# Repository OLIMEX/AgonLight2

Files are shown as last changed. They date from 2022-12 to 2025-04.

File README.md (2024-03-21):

# AgonLight2

AgonLight OSHW Retro Z80 computer - an updated version with few updates

This is a re-design of the original version of AgonLight made by Bernardo Kastrup: https://github.com/TheByteAttic/AgonLight

What is new:
- The board schematic and PCB were re-captured and re-layout in KiCad instead of EasyEDA, KiCad is open source software – free to download and use, it is a more fitting CAD tool for an Open Source Hardware project;
- The power of the original AgonLight is delivered through USB-A connector. We decided to replace it with USB-C connector which is used in all new phones, tablets, and devices due to the new EU directive. Usually everyone has such a cable at home to charge and transfer files to their cell phone;
- The linear voltage regulator is replaced with DCDC which delivers up to 2A current;
- Battery Li-Po charger and step-up converter were added, this keeps the board fully operational even if the external power supply gets disconnected;
- The original design has a PS2 connector for a keyboard and required a USB to PS2 adapter to operate with the more available USB keyboards. We replaced the PS2 connector with a USB-A connector so a normal USB keyboard (which supports PS2) can be directly plugged-in to AgonLight;
- AS7C34096A-10TCTR SRAM is routed with 40 ohm impedance lines as per the datasheet;
- Fixed a signal naming in the ESP32-PICO-D4, which now is updated in the original AgonLight documentation;
- The bare header 32-pin connector is replaced with a plastic boxed 34-pin connector following the same layout and adding two additional signals Vbat and Vin which allow AgonLight to be powered via this connector too;
- [UEXT connector](https://www.olimex.com/Products/Modules/UEXT/) was added - it allows AgonLight to be expanded easily (without soldering) with: [temperature sensors, environmental air quality sensors, pressure sensors, humidity sensors, gyroscopes, light sensors, RS485, LCDs, LED matrices, relays, Bluetooth modules, Zigbee modules, Lora modules, GSM modules, RFID readers, GPS, pulse, EKG, RTC, etc](https://www.olimex.com/Products/Modules/);
- Added four 3.3mm mount holes with GND sleeve were added so the board can be attached firmly to a box or another board but also kept the original 2.5mm mount holes.

Please do not forget to check AgonLight topics in GitHub for many utilities and code written by AgonLight community: https://github.com/topics/agon-light

## Useful Agon Resources
- Bernardo Kastrup https://github.com/TheByteAttic/AgonLight
- Dean Belfield Agon VDP, MOS, BBC-BASIC, Agon DOCs, projects https://github.com/breakintoprogram
- Lennart Benschop FORTH, Nano editor and MOS utilities https://github.com/lennart-benschop
- Jeroen Venema Agon Flash, HexLoad, Z80 assembler, tools, sokoban game https://github.com/envenomator
- Mario Smit Agon ZDI Load and tools https://github.com/S0urceror
- Reinhard Schu Agon Assembly https://github.com/schur/Agon-Light-Assembly
- AgonLight emulator https://github.com/james7780/AgonLightEmuSDL
- Alexander Sharikhin MOS tools https://github.com/nihirash/Agon-MOS-Tools
- Nicholas Pratt Agon Game https://github.com/NicholasPratt/Nova-Star
- Robert Lowe Agon Games collection https://github.com/pngwen
- LuzrBum Agon Games https://github.com/LuzrBum

## Licensee
* Hardware is released under CERN Open Hardware Licence Version 2 - Strongly Reciprocal, all silkscreen credits to Bernardo Kastrup and Dean Belfield should remain;
* Software is released under zlib Licensee
* Documentation is released under CC BY-SA 3.0

## Change History

23-04-2023 - Add Resources

14-12-2022 - Initial upload  of CAD files for first prototypes

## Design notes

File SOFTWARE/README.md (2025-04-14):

A properly operating AgonLight2 system has three software components: Quark™ VDP + Quark™ MOS + Quark™ BBC BASIC. By default each Olimex AgonLight2 board comes with VDP and MOS already programmed. You only need to download the contents of folder "1-SD-card-contents" to a micro SD card to start using the AgonLight2 board. You need an micro SD card in FAT or FAT32 format.

Notice that certain combinations of versions of VDP, MOS, and BBC BASIC might be incompatible. Meaning that you might need to upgrade or downgrade MOS, VDP, BASIC in order to run the board. If in doubt, use the versions we provide.

We load the versions currently at this GitHub but the board that was not purchased directly from us might arrive with previous version of VDP and MOS.

It is always recommended to get the latest files and instructions from the official VDP, MOS, BASIC locations listed below, however if you enounter problems use the versions we have provided, we have tested them and confirmed them to work. 

    • Quark™ BBC BASIC – https://github.com/breakintoprogram/agon-bbc-basic/releases - BBC Basic interpreter
    • Quark™ MOS - https://github.com/breakintoprogram/agon-mos/releases - command line machine operating system, similar to CP/M or DOS
    • Quark™ VDP - https://github.com/breakintoprogram/agon-vdp/releases - the VDP is a serial graphics terminal that takes a BBC basic text output stream as input. The output is via the VGA connector on the Agon.

The "1-SD-card-contents" folder contains sub-folders with files for the SD card, also mos files that can be flashed via bootloader without programmer (if possible);

The "2-AgonLight2-VDP-XXX" folder contains VDP;

The "3-AgonLight2-MOS-XXX" folder contains MOS that can be flashed via programmer;

The "4-AgonLight2-Console8" folder contains Console8 versions of VDP, MOS, BBC basic that can be used to upgrade the system via SD card. Refer to the README.md file in the folder for details on how to switch to Console8 VPD, MOS, BBC basic.

Copy the contents in from the "SD Card Content" into the root directory of the card. The contents are:

1) bbcbasic.bin (for the latest version check: https://github.com/breakintoprogram/agon-bbc-basic);
2) autoexec.txt which runs the BASIC on restart;
3) basic_examples_tests – various BASIC examples/test/games programs;
4) Agon-CPM2.2 – contains CPM;
5) mos – contains files suitable for updating mos without programmer.

**Updating the Agon Quark VDP on the ESP32 chip with a binary:**

1. If you don't want to compile the source code you can just upload the binary (if you wish to compile from source check next chapter)
2.  Download all contents from /2-AgonLight2-VDP-104/binary-flasher - https://github.com/OLIMEX/AgonLight2/tree/main/SOFTWARE/2-AgonLight2-VDP-104/binary-flasher
3.  Open terminal or command line to the folder where the contents are
4.  Execute flash.sh followed by com port number of device assigned by operating system (usually COMx in Windows, TTYx in Linux).

**To compile and update the Agon Quark VDP on the ESP32 chip you have to install IDE, package and libraries:**

1. Arduino IDE

    1.1. Go to: https://www.arduino.cc/en/software

    1.2 While this will most likely work with 2.x.x we recommend you to download 1.8.9 which is shown a little bit below in the section "Legacy IDE (1.8.x)"

    1.3. Download, install and run it

2. Install the ESP32 package

    2.1. Go to "Main menu --> Preferences" (CTRL+,)

    2.2. In the "Additional Boards Manager URLs" add in a new line: https://raw.githubusercontent.com/espressif/arduino-esp32/gh-pages/package_esp32_index.json

    2.3. Go to "Main menu -> Tools -> Board -> Boards manager..."

    2.4. Look for the package "ESP32" (since there are lots of packages you can filter them by typing "ESP32" in the search bar on the top)

    2.5. Install the package (it is tested with v2.0.14, notice that versions 3.x.x are confirmed not working)

3. Install the FabGL library

    3.1. Go to "Main menu -> Sketch -> Include Library -> Manage Libraries..." (CTRL+SHIFT+I)

    3.2. Look for library FabGL (just like the packages earlier you can filter all the libraries by typing "FabGL" in the search bar).

    3.3. There are two results, select the vdp-gl version by Igor Cananena. Install it. Notice: If you have trouble in the next step (errors during compilation) maybe deinstall vdp-gl and try the with FabGL instead, version 1.0.8, newer versions of the library may not work. 

4. VDP compile and update
   
    4.1. Open the sketch /2-AgonLight2-VDP-104/Source/Video/video.ino (the provided one is version 1.04, for the latest one check https://github.com/breakintoprogram/agon-vdp )

    4.2. Go to "Main menu -> Tools -> Board -> ESP32 Arduino" and select "ESP32 Dev Module"

    4.3. Plug the USB to the AgonLight2 board

    4.4. In Device manager you can see the COM# at which our device has connected

    4.5. Go to "Main menu -> Tools -> Port" select the one ESP32 has connected

    4.6. Go to "Main menu -> Tools -> PSRAM" select Enabled

    4.7. Compile and Upload (every time after opening the project in Arduino the first compilation is VERY slow - be patient)

**Updating the Agon Quark MOS on the eZ80 chip:**

1. Usually you can update the MOS without the need of programmer (the board needs to have MOS 1.02). Follow the instructions in /1-SD-card-contents/mos/README.txt - https://github.com/OLIMEX/AgonLight2/tree/main/SOFTWARE/1-SD-card-contents/mos

2. If there is no MOS at all or it's older than 1.02 you must have "ZILOG eZ80F92" programmer and have to install IDE:

    2.1. Download "ZDS II - eZ80Acclaim!" from here: https://zilog.com/index.php?option=com_zcm&task=view&soft_id=54&Itemid=74 (tested with 5.3.5 but should work with newer versions)

    2.2. Install the IDE and run it

    2.3. Go to "Main menu -> File -> Open Project" and navigate to  "3-AgonLight2-MOS-104/MOS.zdsproj" (the provided versions is 1.04, for the latest one check https://github.com/breakintoprogram/agon-mos )

    2.4. Build the project (F7)

    2.5. Connect the programmer to the ZDI connector on the AgonLight2 board

    2.6. Go to "Main menu -> Debug -> Download the code"

    2.7. When the download is complete go again to "Main menu --> Debug --> Stop Debugging" (SHIFT + F5)

    2.8. Disconnect the programmer from the board

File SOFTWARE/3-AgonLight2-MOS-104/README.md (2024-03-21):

# agon-mos

Part of the official Quark firmware for the Agon series of microcomputers

### What is the Agon

Agon is a modern, fully open-source, 8-bit microcomputer and microcontroller in one small, low-cost board. As a computer, it is a standalone device that requires no host PC: it puts out its own video (VGA), audio (2 identical mono channels), accepts a PS/2 keyboard and has its own mass-storage in the form of a µSD card.

https://www.thebyteattic.com/p/agon.html

### What is a MOS

The MOS is a command line machine operating system, similar to CP/M or DOS, that provides a human interface to the Agon file system.

It also provides an API for file I/O and other common operations for BBC Basic for Z80 and other third-party applications.

### Loadig BBC Basic for Z80

1. Download bbcbasic.bin from [agon-bbc-basic releases](https://github.com/breakintoprogram/agon-bbc-basic/releases)
2. Copy it to the root directory of the Agon SD card
3. Insert the SD card into the AGON and reset/boot it
4. Check the file is on the SD card with a `CAT` or `.` command
5. Type the following commands into MOS:
	- `LOAD bbcbasic.bin`
	- `RUN`
6. You should then be greeted with the BBC Basic for Z80 prompt

### Etiquette

Please do not issue pull requests or issues for this project; it is very much a work-in-progress.
I will review this policy once the code is approaching live status and I have time to collaborate more.

### Build

The eZ80 is programmed via the ZDI connector on the left-hand side of the board. This requires a Zilog Smart Cable that can be purchased from online stockists such as Mouser or RS Components.

There are three compatible cables with the following part numbers:

- `ZUSBSC00100ZACG`: USB Smart Cable (discontinued)
- `ZUSBASC0200ZACG`: USB Smart Cable (in stock - this requires ZDS II version 5.3.5)
- `ZENETSC0100ZACG`: Ethernet Smart Cable (in stock)

Important! Make sure you get the exact model of cable; there are variants for the Zilog Encore CPU that have similar part numbers, but are not compatible with the Acclaim! eZ80 CPU.

You can download the ZDS II tools for free via these links. The software contains an IDE, Debugger, C Compiler and eZ80 Assembler.

- [Zilog ZDS II Tools version 5.3.4](https://zilog.com/index.php?option=com_zcm&task=view&soft_id=38&Itemid=74)
- [Zilog ZDS II Tools version 5.3.5](https://zilog.com/index.php?option=com_zcm&task=view&soft_id=54&Itemid=74)

You will also need a [Hex2Bin utility](https://sourceforge.net/projects/hex2bin/) to convert the MOS.hex file to MOS.bin ready for release.

NB:

- The tools are only available for Windows PC.
- The tools are compatible with Wine on Linux / OSX, but the USB Smart Cable drivers do not work
- The Ethernet Smart Cable may be compatible with the tools running on Wine, though this combination has not been tested by me

I currently build the official Quark software on a Windows XP KVM running on Ubuntu 20.04 LTS, using ZDS II Tools version 5.3.4, connecting to the Agon with the discontinued USB smart cable.

It is recommended that building and testing the MOS is done via the ZDS II tools and a Zilog Smart Cable, otherwise there is an increased risk of bricking the Agon.

Other options for developing C and eZ80 on the Agon are available. Please check the [Agon Programmers Group on Facebook](https://www.facebook.com/groups/667325088311886) for more information.

Any custom settings for Agon development is contained within the project files, so no further configuration will need to be done.

### Documentation

The AGON documentation can now be found on the [Agon Light Documentation Wiki](https://github.com/breakintoprogram/agon-docs/wiki)

### Licenses

This code is released under an MIT license, with the following exceptions:

* FatFS: The license for the [FAT filing system by ChaN](http://elm-chan.org/fsw/ff/00index_e.html) can be found here [src_fatfs/LICENSE](src_fatfs/LICENSE) along with the accompanying code.

### Links

- [Zilog eZ80 User Manual](http://www.zilog.com/docs/um0077.pdf)
- [ZiLOG Developer Studio II User Manual](http://www.zilog.com/docs/devtools/um0144.pdf)
- [FatFS - Generic File System](http://elm-chan.org/fsw/ff/00index_e.html)
- [AVRC Tutorials - Initialising an SD Card](http://www.rjhcoding.com/avrc-sd-interface-1.php)

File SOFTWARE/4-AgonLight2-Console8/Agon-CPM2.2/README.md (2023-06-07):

# CP/M 2.2 for Agon Light



This is port of CP/M 2.2 for Agon Light(and Agon Light 2) that didn't require reflashing VDP.

It starts directly from MOS as application(exit only via RESET) and uses MOS's filesystem drivers for working with drive images.

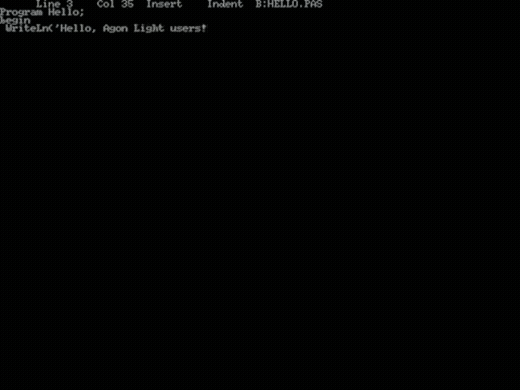
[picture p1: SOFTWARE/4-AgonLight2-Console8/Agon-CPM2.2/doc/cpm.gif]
GIF screen capture


## Usage

Create some directory on Agon's SD card, put `cpm.bin` and disk images(**TO THE SAME DIRECTORY**) that will be named `cpma.dsk`, `cpmb.dsk` etc, drives from `A:` to `P:` are supported. 

Load and run binary and you'll be in CP/M's wonderland.

## Working with images

I'm using [cpmtools](https://github.com/lipro-cpm4l/cpmtools) for working with CP/M drive images.

Disk definition can be copied from `diskdefs` file(in `disks` directory).

For new drives better use template.dsk(make copy with proper naming and copy yourown files to it). 

## Development

Make sure that you **really want it**.

Build process have 2 stages. Building CP/M itself(`sources` directory) - you'll need [sjasmplus](https://github.com/z00m128/sjasmplus). As result - you'll got `cpm.sys` file that should be placed to directory with bootstrap source. 

Bootstrap can be built with [ez80asm](https://github.com/envenomator/agon-ez80asm). Better use latest version.

As result - you'll got `cpm.bin` executable that will include bootstrap and system both.

## Important remarks

BIOS and CP/M core should be aligned by 256 bytes.

If you'll make some changes in code - make sure that bios starts from 0xXX00 address. In other case - you'll die until you find issue why software got broken.

All terminal issues caused by current VDP implementation. They can be fixed soon. 

## Licensing

CP/M itself [opensourced](https://www.theregister.com/2001/11/26/cp_m_collection_is_back/) and free for redistribution. 

My parts of code licensed as usual under [Coffeeware License](LICENSE).

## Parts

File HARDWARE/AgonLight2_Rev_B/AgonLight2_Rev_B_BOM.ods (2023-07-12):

Qty | Designation | Package | Designator
12 | 33R/0603 | R_0603_5MIL_DWS | R1,R2,R3,R5,R6,R7,R8,R12,R18,R19,R24,R43
1 | 150R/0603 | R_0603_5MIL_DWS | R23
1 | 220R/0603 | R_0603_5MIL_DWS | R58
1 | 270R/0603 | R_0603_5MIL_DWS | R25
3 | 430R/1%/0603 | R_0603_5MIL_DWS | R26,R28,R30
3 | 820R/0603 | R_0603_5MIL_DWS | R27,R29,R31
1 | 1.1K/1%/0603 | R_0603_5MIL_DWS | R50
10 | 2.2K/0603 | R_0603_5MIL_DWS | R22,R37,R38,R39,R40,R47,R48,R51,R56,R57
8 | 4.7K/0603 | R_0603_5MIL_DWS | R4,R9,R10,R11,R13,R14,R15,R16
2 | 5.1K/0603 | R_0603_5MIL_DWS | R45,R46
1 | 8.2K/1%/0603 | R_0603_5MIL_DWS | R49
12 | 10K/0603 | R_0603_5MIL_DWS | R17,R32,R33,R34,R42,R44,R54,R55,R61,R60, R62,R63
2 | 22K/0603 | R_0603_5MIL_DWS | R20,R21
1 | 49.9K/1%/0603 | R_0603_5MIL_DWS | R53
1 | 220K/0603 | R_0603_5MIL_DWS | R52
1 | RA1206_(4x0603)_4B8_100k | RA1206_(4X0603)_4B8_xx | RM1
2 | 27pF/C0G/50VDC/5%/0603 | C_0603_5MIL_DWS | C55,C56
8 | 1nF/X7R/50VDC/0402 | C_0402_5MIL_DWS | C9,C10,C11,C12,C14,C15,C16,C17
22 | 100nF/10V/20%/X5R/0402 | C_0402_5MIL_DWS | C5,C6,C7,C8,C13,C18,C19,C20,C21,C26,C28, C29,C31,C32,C35,C39,C40,C41,C42,C58, C62,C63
1 | 33nF/X7R/50VDC/10%/0603 | C_0603_5MIL_DWS | C38
20 | 10uF/6.3V/20%/X5R/0603 | C_0603_5MIL_DWS | C1,C2,C3,C4,C22,C23,C24,C25,C27,C30,C33, C34,C36,C37,C43,C44,C45,C49,C59,C60
4 | 22uF/6.3V/20%/X5R/C0603 | C_0603_5MIL_DWS | C51,C52,C57,C61
6 | 47uF/6.3V/20%/X5R/0805 | C_0805_5MIL_DWS | C46,C47,C48,C50,C53,C54
2 | 1N4148W/SOD123 | SOD-123_1C-2A_KA | D1,D2
2 | 1N5822/SS34/SMA | SMA-KA | D4,D5
2 | 1N5819S4/SOD123 | SOD-123_1C-2A_KA | D6,D7
1 | LED/YELLOW/0603 | LED_0603_KA | CHARGING1
1 | LED/RED/0603 | LED_0603_KA | POWER1
2 | 2.2uH/1.5A/ NRS3015T2R2MNGH | CD32 | L5,L6
4 | FB0805/600R/2A | L_0805_5MIL_DWS | L1,L2,L3,L4
2 | BSS138(SOT23-3) | SOT23 | FET1,FET2
1 | WPM2015-3/TR | SOT23 | FET3
3 | BC817-40NPN(SOT23) | SOT23 | Q2,Q4,Q5
1 | Q12MHz/20pF/10ppm/ 4P/3.2x2.5mm | TSX-3.2x2.5mm_GND(3) | Q3
1 | ASE-18.432MHZ-L-C-T | Oscillator-18.432MHz-3.2x2.5mm | Q1
2 | SN74LVC1G125DBVR | SOT-23-5 | BUF1,BUF2
1 | SN74LVC1G04DBVR | SOT-23-5 | BUF3
1 | EZ80F92AZ020EG(LQFP100) | LQFP-100_14x14mm_ STM32H730VBT6 | U1
1 | AS7C34096A-10TCTR | TSOP-44_Pitch-0.80mm_ 18.80x11.80x1.20mm | U2
1 | ESP32-PICO-D4 | ESP32-PICO-D4 | U3
1 | BL4054B-42TPRN(SOT23-5) | SOT-23-5 | U5
1 | SY8089AAAC(SOT23-5) | SOT-23-5 | U7
1 | MT3608(SOT23-6) | SOT23-6 | U8
1 | CH340T(SSOP20W) | SSOP-20W | U9
1 | VDA2710NTA(SOT-23) | SOT-23 | U10
1 | APS6404L-3SQR-SN | SO-8 | U4
1 | BUZZER_PB1221P (1.1-1.7V_2kHz_12MM) | PB1221P_1-Plus_2-Minus | BUZ1
1 | B-R-10-LF(BH10R) 2x05_90DEGREE | UEXT_BH10R | UEXT1
1 | BH06S_2x3(B-D-02x3-LF) | BH06S | ZDI1
1 | B-R-34-LF(BH34R) 2x17_90DEGREE | BH34R | GPIO1
1 | HN1x4 | HN1x4 | ACCESS_BUS1
1 | DW02R | LIPO_BAT-CON2DW02R | BAT1
1 | USBLC6-2P6 | SOT-666 | U6
1 | B3F-3150 | B3F-31XX | RESET1
1 | VGA15 | VGA15-F(CD0515S21J0) | VGA1
1 | PJ-3.5-365-5P (SCJ325P00XG0B02G)-COPY | SCJ325P00XG0B02G | AUDIO1
1 | TFC-WPAPR-08-LF | TFC-WPAPR-08 | MICRO_SD1
1 | USB-C-16P-F (A40-00119-A52-12) | USB2.0_TYPE-C (A40-00119-A52-12) | USB1
1 | USB-SRWH-4A-LF(USB-A) | USB_PN87520_HOST_PTH | USB_KEYBOARD1
3 | HN1x2+MJ6 | HN1x2_Jumper | BUZ_EN1,UART_DIS1,ESP_PROG1
45 | NA | D_0402_5MIL_DWS | TVS1,TVS2,TVS3,TVS4,TVS5,TVS6,TVS7, TVS11,TVS12,TVS13,TVS14,TVS15,TVS16, TVS17,TVS18,TVS19,TVS20,TVS21,TVS22, TVS23,TVS24,TVS25,TVS26,TVS27,TVS28, TVS29,TVS30,TVS31,TVS32,TVS33,TVS34, TVS35,TVS36,TVS37,TVS38,TVS39,TVS40, TVS41,TVS42,TVS43,TVS44,TVS45,TVS46, TVS47,TVS48
6 | NA(GG0402052R542P) | D_0402_5MIL_DWS | TVS8,TVS9,TVS10,TVS49,TVS50,TVS51
2 | NA(120R/0603) | R_0603_5MIL_DWS | R35,R36
2 | NA | R_0603_5MIL_DWS | R41,R59
1 | NA | SMA-KA | D3

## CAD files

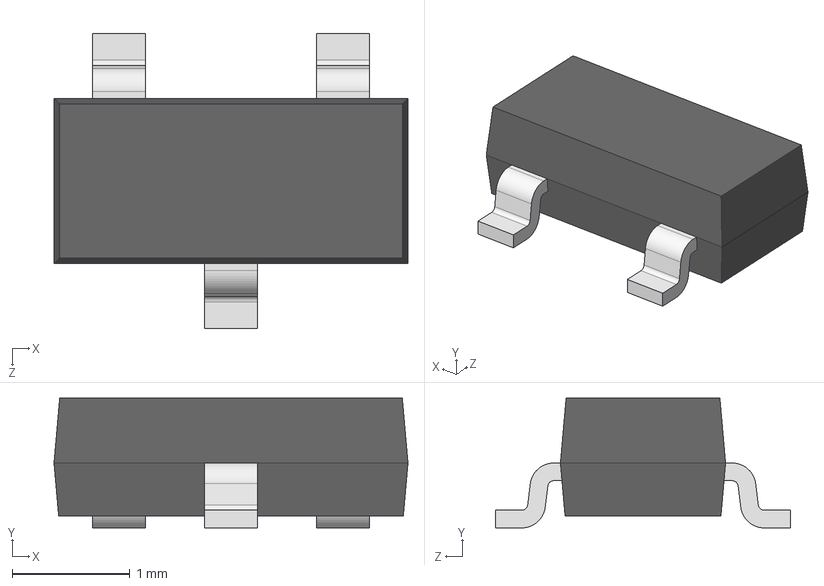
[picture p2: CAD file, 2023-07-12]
HARDWARE/AgonLight2_Rev_B/3d/SOT-23.step
3.00 x 1.10 x 2.50 mm

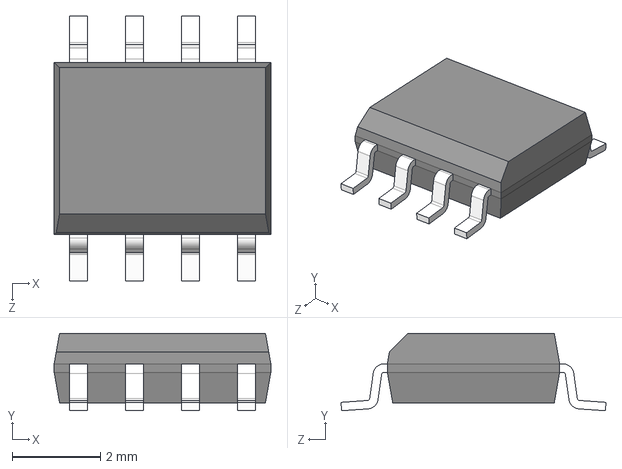
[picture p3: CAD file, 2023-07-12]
HARDWARE/AgonLight2_Rev_B/3d/SO-8_150mil---SN65HVDA1050AQDRQ1.STEP
4.90 x 1.75 x 5.99 mm

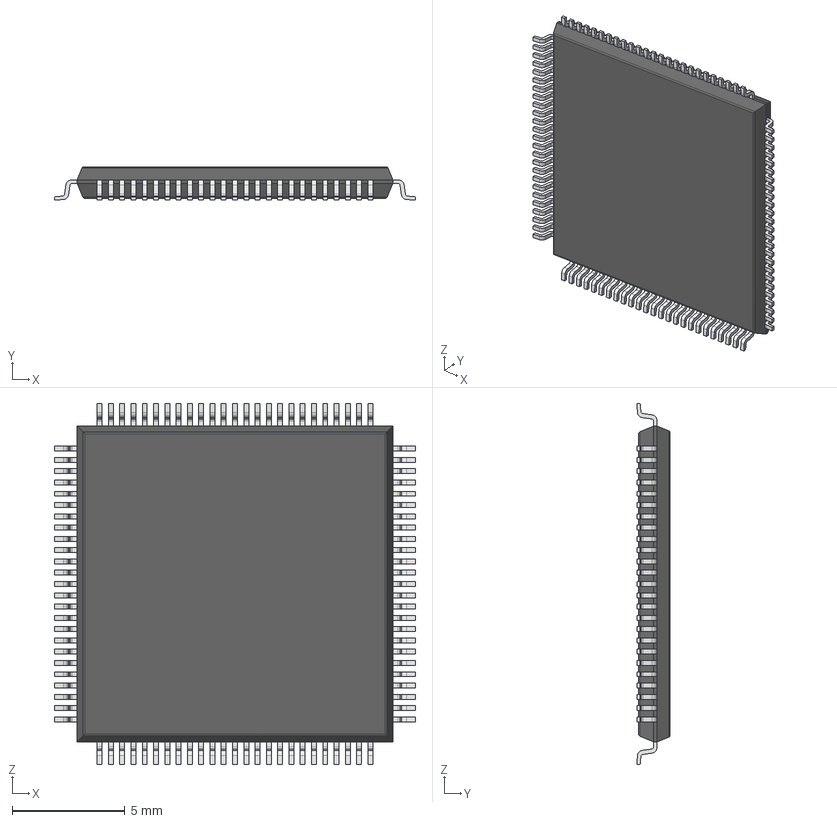
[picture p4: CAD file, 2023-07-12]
HARDWARE/AgonLight2_Rev_B/3d/stm32f103vet6.stp
16.0 x 1.48 x 16.0 mm

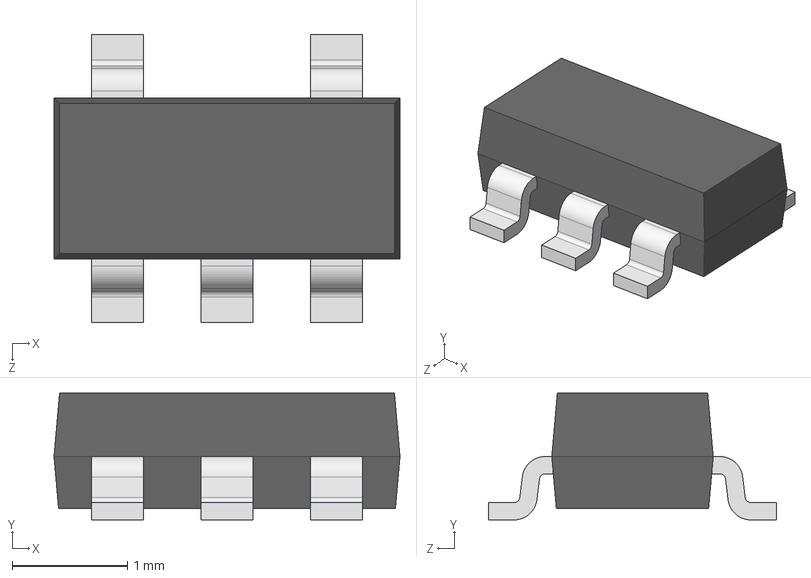
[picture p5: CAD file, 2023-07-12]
HARDWARE/AgonLight2_Rev_B/3d/SOT-23-5.step
3.00 x 1.10 x 2.50 mm

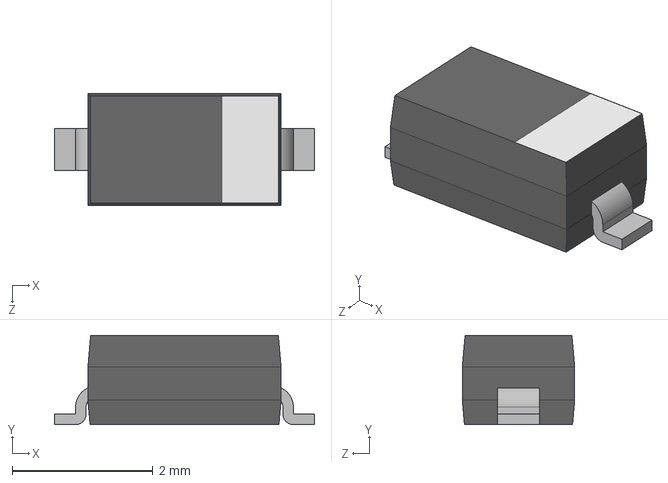
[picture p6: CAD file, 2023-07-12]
HARDWARE/AgonLight2_Rev_B/3d/SOD123.step
3.70 x 1.27 x 1.60 mm

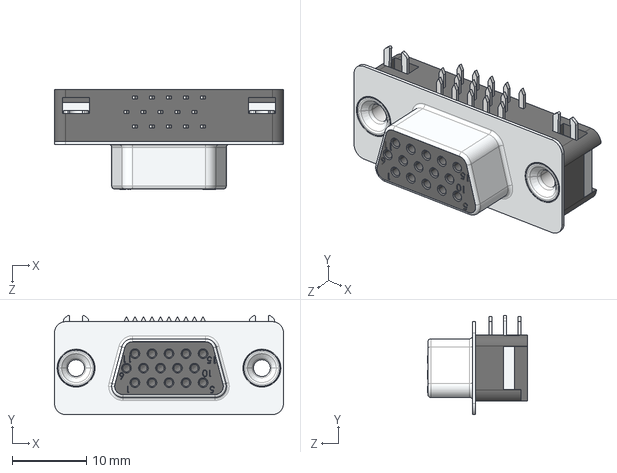
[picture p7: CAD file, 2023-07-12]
HARDWARE/AgonLight2_Rev_B/3d/User Library-SLIM D-SUB RIGHT ANGLE PCB MOUNT.step
30.8 x 13.3 x 13.5 mm

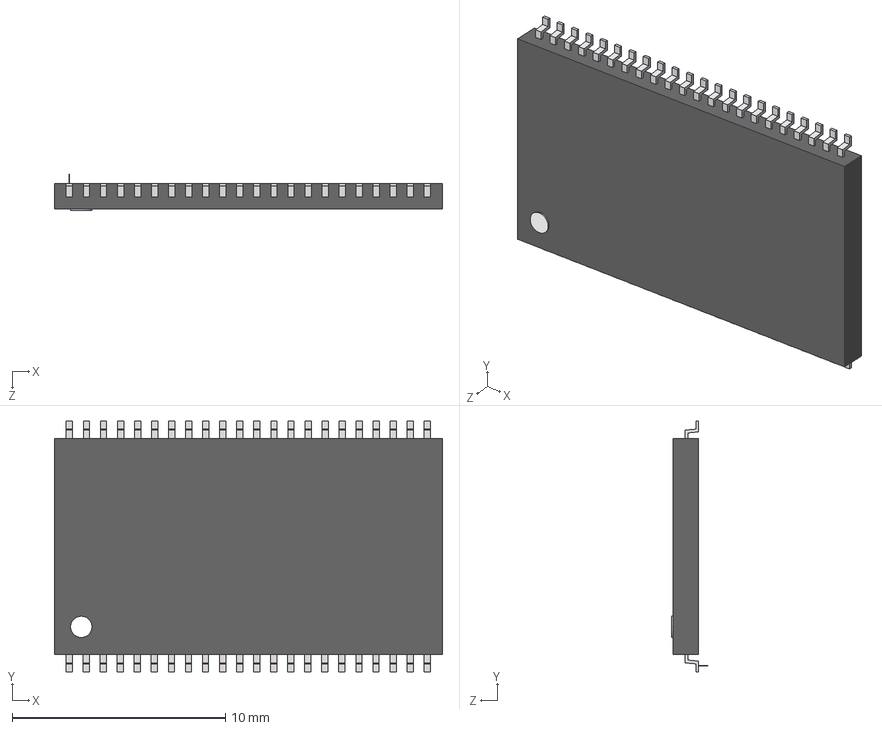
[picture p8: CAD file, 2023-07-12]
HARDWARE/AgonLight2_Rev_B/3d/User_Library-TSOP2-44.STEP
18.2 x 11.8 x 1.70 mm
Extruded2 x 44
Board4 x 44
Extruded3
Board3
Board5

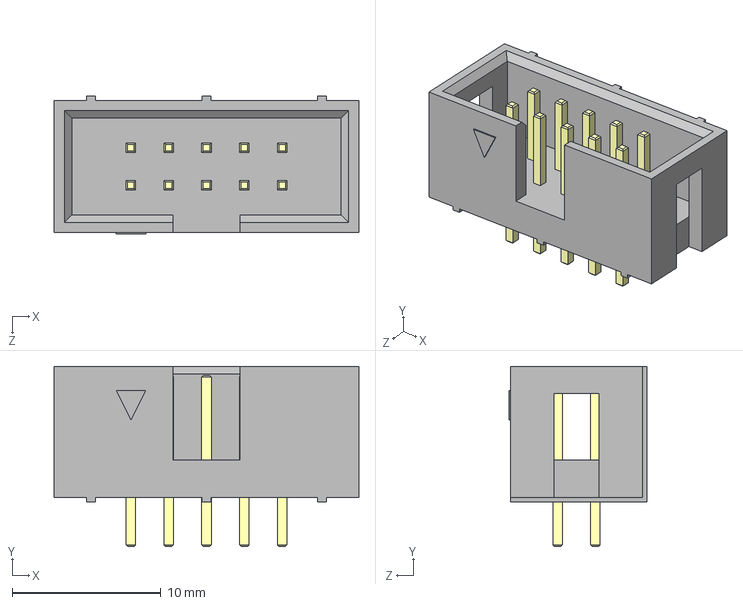
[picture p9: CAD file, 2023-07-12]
HARDWARE/AgonLight2_Rev_B/3d/BH-10__64.step
20.5 x 12.1 x 9.30 mm

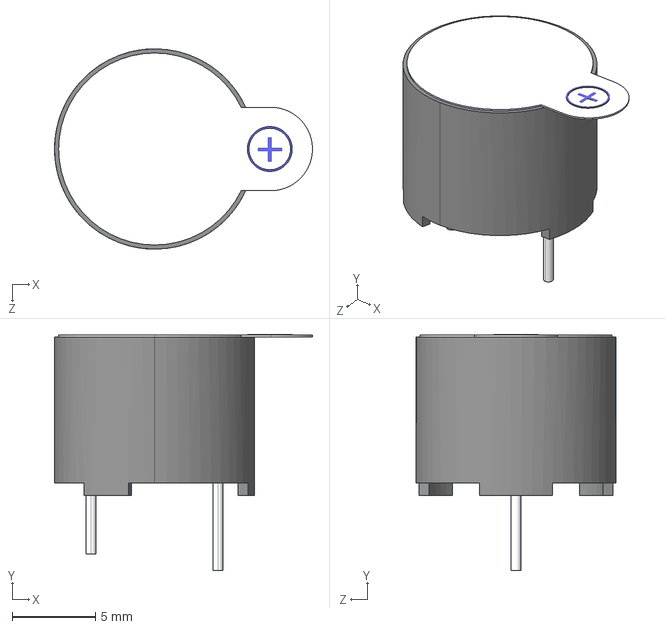
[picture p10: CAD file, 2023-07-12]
HARDWARE/AgonLight2_Rev_B/3d/ALSRobot-BUZZER.step
15.5 x 14.2 x 12.0 mm

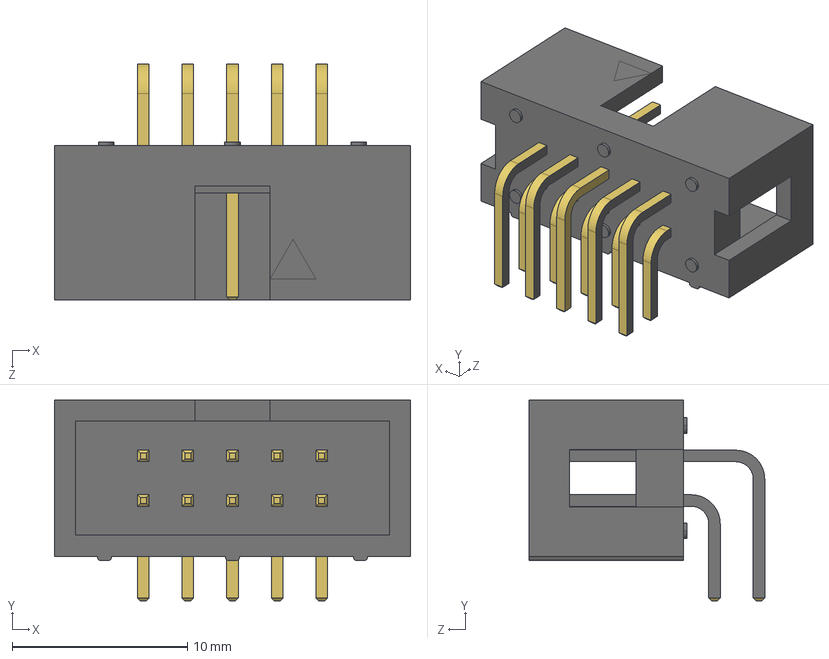
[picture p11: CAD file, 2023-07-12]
HARDWARE/AgonLight2_Rev_B/3d/Header_right_angle_10way(2x5).step
20.3 x 11.4 x 13.4 mm

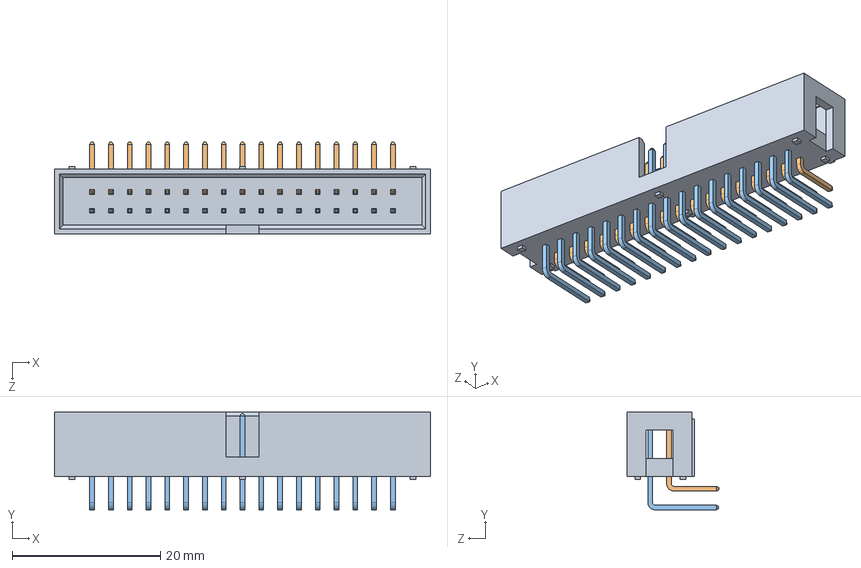
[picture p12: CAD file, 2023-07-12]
HARDWARE/AgonLight2_Rev_B/3d/BH34R_CH87342H100.STEP
50.8 x 13.2 x 12.4 mm
CH87 BASE_34
H TYPEµuPIN x 17
H TYPEªøPIN x 17

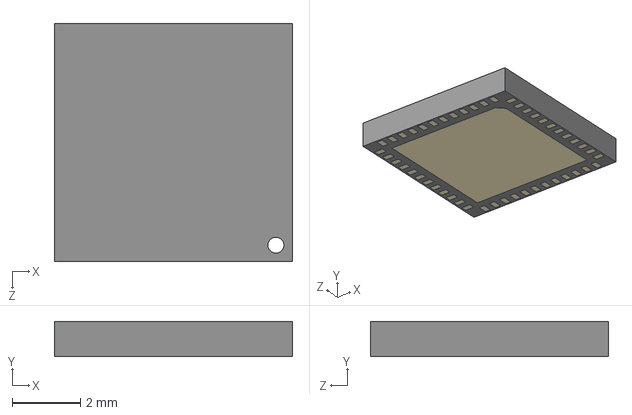
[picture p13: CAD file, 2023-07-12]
HARDWARE/AgonLight2_Rev_B/3d/ESP32-PICO-D4.STEP
7.00 x 1.04 x 7.00 mm

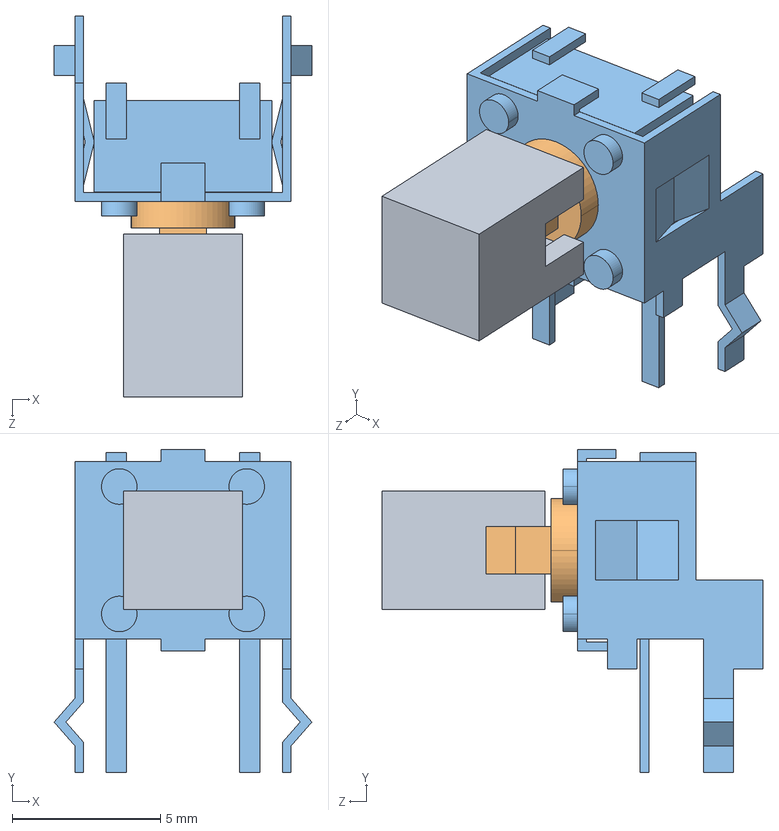
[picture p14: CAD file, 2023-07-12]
HARDWARE/AgonLight2_Rev_B/3d/B3F_3150.step
8.70 x 10.9 x 12.9 mm
B32_1000
B3F_3150_BUTTON
B3F_3150_BASE

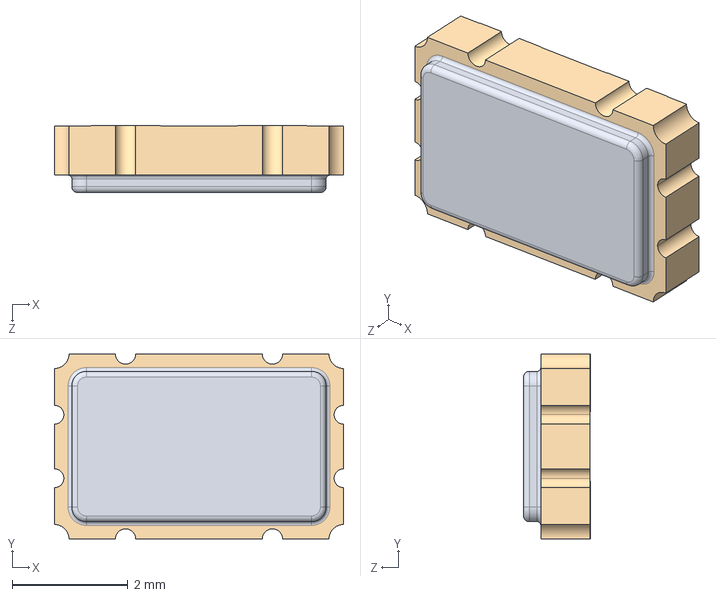
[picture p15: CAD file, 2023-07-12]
HARDWARE/AgonLight2_Rev_B/3d/QSG5032.step
5.00 x 3.20 x 1.16 mm

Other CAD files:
HARDWARE/AgonLight2_Rev_B/3d/TFC-WPAPR-08---112J-TXAR-R_C_1-1.STEP
HARDWARE/AgonLight2_Rev_B/3d/L-CD32_shielded.step
HARDWARE/AgonLight2_Rev_B/3d/72w2538_292303-4.stp
HARDWARE/AgonLight2_Rev_B/3d/DO-214AC_SMA.step
HARDWARE/AgonLight2_Rev_A/3d/72w2538_292303-4.stp
HARDWARE/AgonLight2_Rev_A/3d/Audio_Jack-3.5mm---CUI_SJ1-3515-SMT-TR.step
HARDWARE/AgonLight2_Rev_A/3d/DO-214AC_SMA.step
HARDWARE/AgonLight2_Rev_A/3d/HN1x2-PinHeader_1x02_P2.54mm_Vertical.step
HARDWARE/AgonLight2_Rev_A/3d/HN1x4-PinHeader_1x04_P2.54mm_Vertical.step
HARDWARE/AgonLight2_Rev_A/3d/JST_B2B-PH-SM4-TB(DW02R).step
HARDWARE/AgonLight2_Rev_A/3d/L-CD32_shielded.step
HARDWARE/AgonLight2_Rev_A/3d/SOT-23-6.step
HARDWARE/AgonLight2_Rev_A/3d/TFC-WPAPR-08---112J-TXAR-R_C_1-1.STEP
HARDWARE/AgonLight2_Rev_A/3d/User Library-SOT50P160X60-6.step
HARDWARE/AgonLight2_Rev_B/3d/Audio_Jack-3.5mm---CUI_SJ1-3515-SMT-TR.step
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

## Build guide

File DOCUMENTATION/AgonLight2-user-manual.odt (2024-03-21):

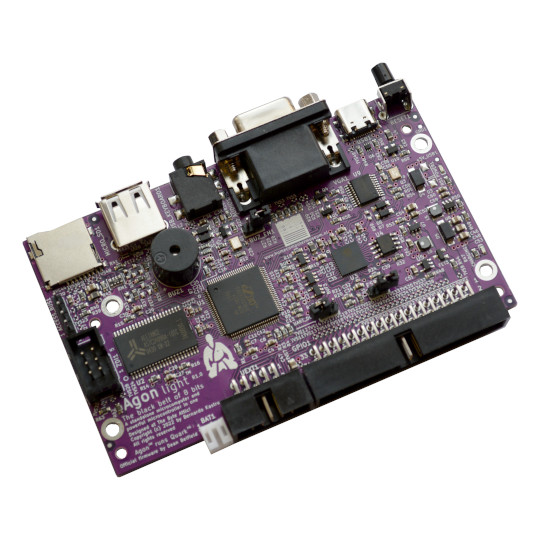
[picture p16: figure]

AgonLight2

User Manual

Rev.1.9 March 2024 olimex.com

# INTRODUCTION

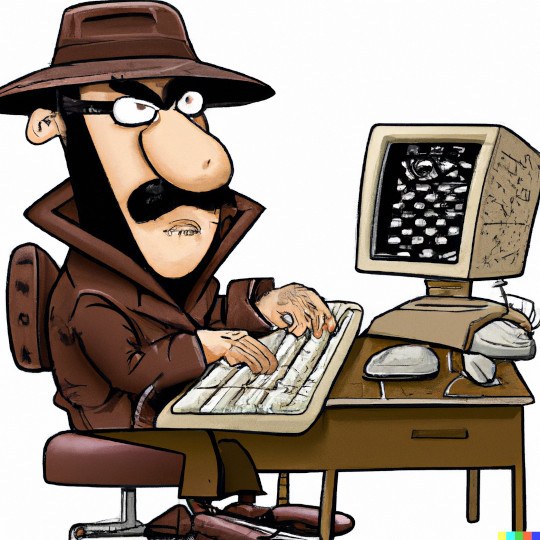
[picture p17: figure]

## What is AgonLight2?

AgonLight2 (https://www.olimex.com/Products/Retro-Computers/AgonLight2/open-source-hardware) is a re-design of the original AgonLight eZ80F92 retro computer, designed as a hobby project by Bernardo Kastrup;

AgonLight2 (https://www.olimex.com/Products/Retro-Computers/AgonLight2/open-source-hardware) is a complete Single Board Computer (SBC) with VGA display output, PS2 keyboard, and SD card (acting as an external disk). This means that to write and run programs you do not need an external computer like Arduino boards do;

AgonLight2 (https://www.olimex.com/Products/Retro-Computers/AgonLight2/open-source-hardware) is BASIC-programmable microcomputer;

AgonLigh (https://www.olimex.com/Products/Retro-Computers/AgonLight2/open-source-hardware)t2 (https://www.olimex.com/Products/Retro-Computers/AgonLight2/open-source-hardware) has a GPIO connector with GPIO ports, I2C, SPI, and more signals, which are accessible and can be used to interact with additional hardware (sensors, expansions, etc);

AgonLight and AgonLight2 (https://www.olimex.com/Products/Retro-Computers/AgonLight2/open-source-hardware) are Open Source Hardware and officially OSHWA certified (https://certification.oshwa.org/bg000090.html);

All CAD source files are available at AgonLight (https://github.com/TheByteAttic/AgonLight) and AgonLight2 (https://github.com/OLIMEX/AgonLight2) GitHub repositories. They are released under CERN Open Hardware License Version 2 – Strongly Reciprocal and allow users to learn, study, edit, modify, produce, and sell same or derivative products based on these designs. The only requirements is to open source their work under the same licensee.

The firmware of AgonLight is written by Dean Belfield and reproduces BBC Basic for Z80. The firmware is also Open Source Software and available on GitHub (https://github.com/breakintoprogram/agon-bbc-basic/). The same firmware works on AgonLight2 (https://www.olimex.com/Products/Retro-Computers/AgonLight2/open-source-hardware) without any modifications.

AgonLight2 (https://www.olimex.com/Products/Retro-Computers/AgonLight2/open-source-hardware) is RoHS, REACH, CE and UKCA compliant.

## Order codes and links for AgonLight2 and accessories

AgonLight2 (https://www.olimex.com/Products/Retro-Computers/AgonLight2/open-source-hardware) Single board BBC BASIC Z80 Retro style computer

MICRO-SD-CLASS (https://www.olimex.com/Products/Components/Storage/MICRO-SD-CLASS10/) You need a microSD card to store BASIC and software (demos, examples)

AgonLight2-Proto (https://www.olimex.com/Products/Retro-Computers/AgonLight2-Proto/open-source-hardware) DIY expansion kit with big proto area; compatible with AgonLight2

BOX-AGONLIGHT2-BLACK (https://www.olimex.com/Products/Retro-Computers/BOX-AGONLIGHT2-BLACK/) Protective metal boxwith polymer coating; compatible with AgonLight2

CABLE-USB-A-C-1M (https://www.olimex.com/Products/Components/Cables/CABLE-USB-A-C-1M/) USB-C data and power cable

BATTERY-LIPO1400mAh (https://www.olimex.com/Products/Power/Lipo-battery/BATTERY-LIPO1400mAh/) Li-po battery 3.7V 1400mAh – note that these batteries can be shipped only by ground so we can deliver only to EU destinations

USB-KEYBOARD-PS2 (https://www.olimex.com/Products/USB-Modules/USB-KEYBOARD-PS2/) USB keyboard which supports PS2 and can be used for AgonLight2 (https://www.olimex.com/Products/Retro-Computers/AgonLight2/open-source-hardware)

B (https://www.olimex.com/Products/Breadboarding/BREADBOARD-1/)READBOARD-1 (https://www.olimex.com/Products/Breadboarding/BREADBOARD-1/) Breadboard for experimenting with AgonLight2 (https://www.olimex.com/Products/Retro-Computers/AgonLight2/open-source-hardware)

JW-200x10-FM (https://www.olimex.com/Products/Breadboarding/JUMPER-WIRES/JW-200x10-FM/) 10 pieces female-male jumper wires for breadboarding

JW-200x10 (https://www.olimex.com/Products/Breadboarding/JUMPER-WIRES/JW-200x10/) 10 pieces male-male jumper wires for breadboarding

JW-200x10-FF (https://www.olimex.com/Products/Breadboarding/JUMPER-WIRES/JW-200x10-FF/) 10 pieces female-female jumper wires for breadboarding

UEXT modules (https://www.olimex.com/Products/Modules/) Different sensors, relays, LCDs, RTC, GSM, GPS etc accessories which can be connected to AgonLight2 (https://www.olimex.com/Products/Retro-Computers/AgonLight2/open-source-hardware) UEXT connector

MOD-Wii-UEXT-NUNCHUCK (https://www.olimex.com/Products/Modules/Sensors/MOD-WII/MOD-Wii-UEXT-NUNCHUCK/open-source-hardware) 3 axis joystick, two buttons game controller with UEXT connector

## The differences between AgonLight and AgonLight2

AgonLight2 (https://www.olimex.com/Products/Retro-Computers/AgonLight2/open-source-hardware) has these differences from the original design:

- KiCad is used for the CAD, instead of EasyEDA. KiCad is open source software – free to download and use, it is a more fitting CAD tool for an Open Source Hardware project;
- USB-C connector for power supply;
- DCDC power converter with up to 2A output instead of linear power converter;
- Li-Po battery backup power supply, the battery acts like a UPS and will power the computer even if the USB-C gets disconnected. The battery is charged automatically when USB or external power supply is present;
- USB connector for keyboard (but the keyboard must be PS2 compatible!!!);
- SRAM routed with 40 ohm impedance as per part datasheet;
- Fixed some wrong signal naming on ESP32-PICO-D4 GPU co-processor;
- Fixed GPIO and programming connector pin ordering;
- Replaced the naked header 32-pin connector with a plastic boxed 34-pin connector following the same layout and adding two additional signals Vbat and Vin which allow AgonLight2 (https://www.olimex.com/Products/Retro-Computers/AgonLight2/open-source-hardware) to be powered by this connector too;
- Added UEXT connector (https://www.olimex.com/Products/Modules/UEXT/) – it allows AgonLight to be expanded easily (without soldering) with: temperature sensors, environmental air quality sensors, pressure sensors, humidity sensors, gyroscopes, light sensors, RS485, LCDs, LED matrices, relays, Bluetooth modules, Zigbee modules, Lora modules, GSM modules, RFID readers, GPS, pulse, EKG, RTC, etc (https://www.olimex.com/Products/Modules/);
- Added 4 grounded mount holes with 3.3mm diameter, but also kept the original 2.5 mm mount holes.

## First time start up or how to prepare the SD card and boot

Important! Notice that AgonLight2 (https://www.olimex.com/Products/Retro-Computers/AgonLight2/open-source-hardware) comes completely assembled, tested, and programmed with firmware. The only thing you would need to do is prepare a microSD card with BBC basic and some examples, then connect your display and peripherals and apply power supply. The board comes without micro SD card which has to be purchased separately! You might need extra SD card writer.

1. Open a web browser and navigate to: https://github.com/OLIMEX/AgonLight2

2. Click on: “Code” → Download ZIP (in “Local” tab);

3. Extract the downloaded ZIP file in your PC;

4. Enter the folders “SOFTWARE” and then “1-SD-card-contents”, then copy the contents of the folder;

5. Attach a class-10 micro SD card to your PC (formatted in FAT32 and with a size of maximum 32GB);

6. Paste the contents of the folder “1-SD-card-contents” which you’ve copied in step 4, to the microSD card. Files should be placed directly into main folder of the card;

7. Eject the micro SD card from your PC;

8. Insert the micro SD card into the AgonLight2 board;

9. Connect a VGA monitor and a PS/2 keyboard (or a PS/2-compatible USB keyboard,

via a PS/2 adapter) to the AgonLight2 unit;

10. Turn the AgonLight2 board on by connecting it to the USB cable.

More detailed info about the software can be found further below in the document.

## AgonLight reference documents:

Links to original AgonLight manuals: AgonLight Hardware Manual (https://github.com/TheByteAttic/AgonLight/blob/main/Agon%20light%20R1.0%20Manual.pdf), QuickStart Guide (https://github.com/TheByteAttic/AgonLight/blob/main/Agon%20light%20Quick%20Start%20Guide.pdf), and Firmware Installation Guide (https://github.com/TheByteAttic/AgonLight/blob/main/Agon%20light™%20Firmware%20Installation%20Guide.pdf).

# HARDWARE

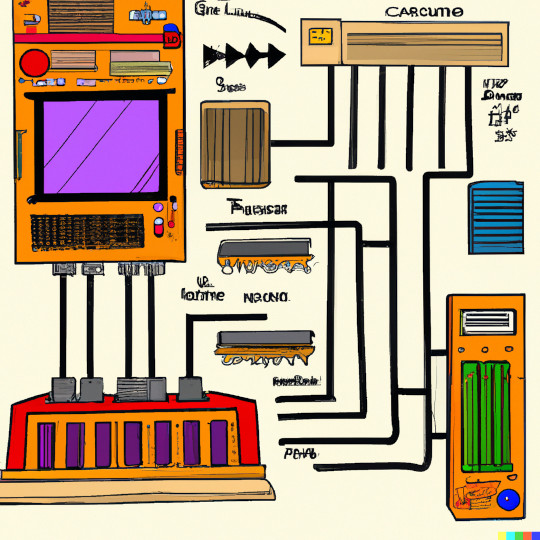
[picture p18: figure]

## AgonLight2 layout

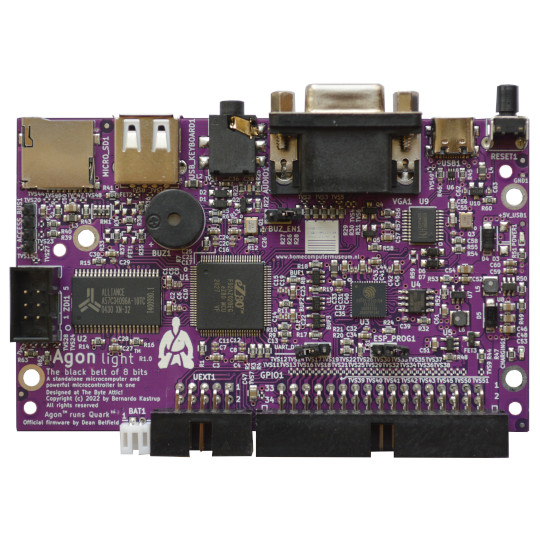
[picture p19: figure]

Micro SD card

USB-PS2 keyboard

Buzzer

LiPo battery

UEXT

GPIO

connector

ESP32 programming

jumper

ESP32 UART disable

jumper

Buzzer enable

jumper

EZ80 programming

Access bus

Audio Out

VGA

USB-C power

Reset button

## AgonLight2 schematic

The current AgonLight2 (https://www.olimex.com/Products/Retro-Computers/AgonLight2/open-source-hardware) design is available for download and print at GitHub (https://github.com/OLIMEX/AgonLight2/tree/main/HARDWARE) – there is PDF export of the schematic, all sources, 3D view files, gerbers, bill-of-materials and more.

## AgonLight2 dimensions

Dimensions can be found in this document:

https://github.com/OLIMEX/AgonLight2/blob/main/DOCUMENTATION/AgonLight2-dimensions-mm.pdf

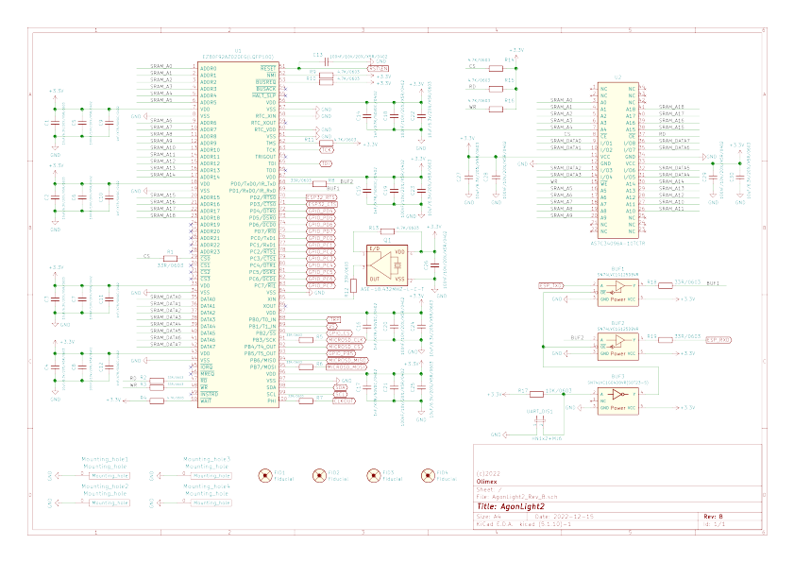
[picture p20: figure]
SVG Picture created as AgonLight2_Rev_B.svg date 2023/07/14 13:05:54 Picture generated by Eeschema-SVG
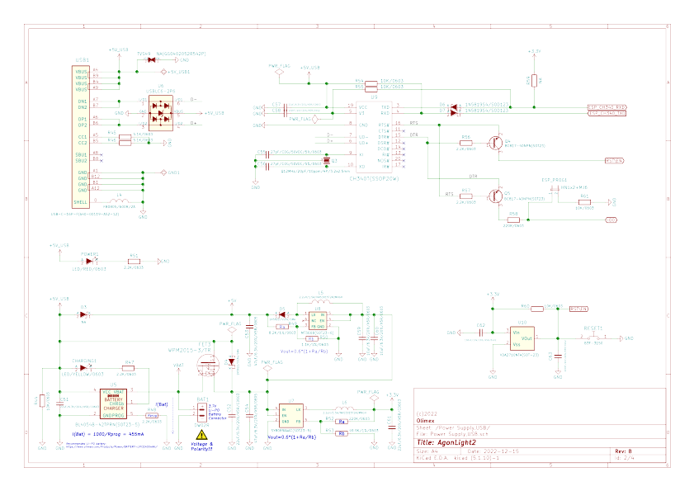
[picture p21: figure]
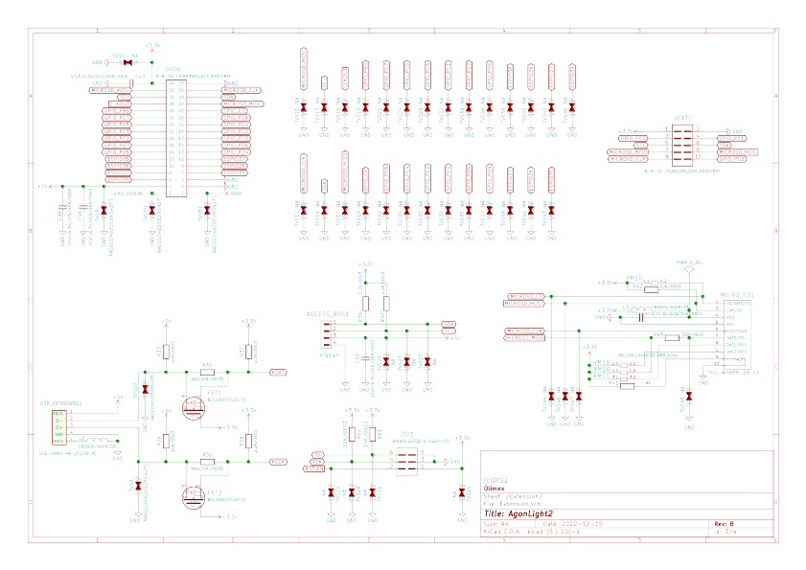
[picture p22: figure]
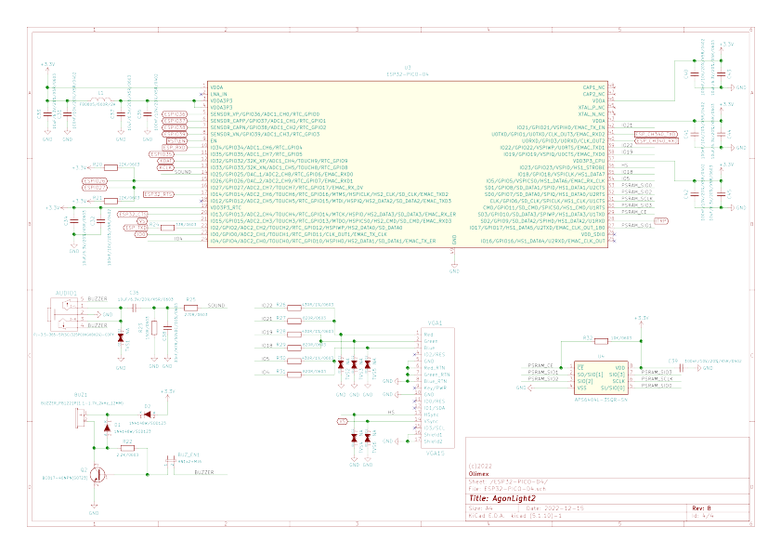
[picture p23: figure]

## AgonLight2 power supply and consumption

(https://www.olimex.com/Products/Retro-Computers/AgonLight2/open-source-hardware)

AgonLight2 (https://www.olimex.com/Products/Retro-Computers/AgonLight2/open-source-hardware) can be powered by 3 sources:

- USB-C connector;
- Li-Po battery connector;
- GPIO.pin2 (5V_USB) note that this wire is connected to the 5V of the USB so when you power AgonLight2 (https://www.olimex.com/Products/Retro-Computers/AgonLight2/open-source-hardware) from GPIO.pin2 – you should not connect have USB cable attached at the same time!!!

The power consumption of AgonLight2 (https://www.olimex.com/Products/Retro-Computers/AgonLight2/open-source-hardware) is approximately 130mA without a keyboard and around 180mA with a keyboard connected.

If a Li-Po battery is connected it will get charged automatically when power supply is attached with up to 100mA.

When the LiPo battery is attached and external power supply is missing internal DCDC step-up converter and switching circuit automatically powers AgonLight2 (https://www.olimex.com/Products/Retro-Computers/AgonLight2/open-source-hardware) from the battery. 1400mAh battery will provide about 8 hours of stand-alone operation.

+ The LiPo battery connector is JST 2.0 mm connector and uses Olimex’s battery polarity. If you use batteries from other manufacturers please make sure PLUS and MINUS are connected properly as you WILL damage the board!!!

## GPIO connector

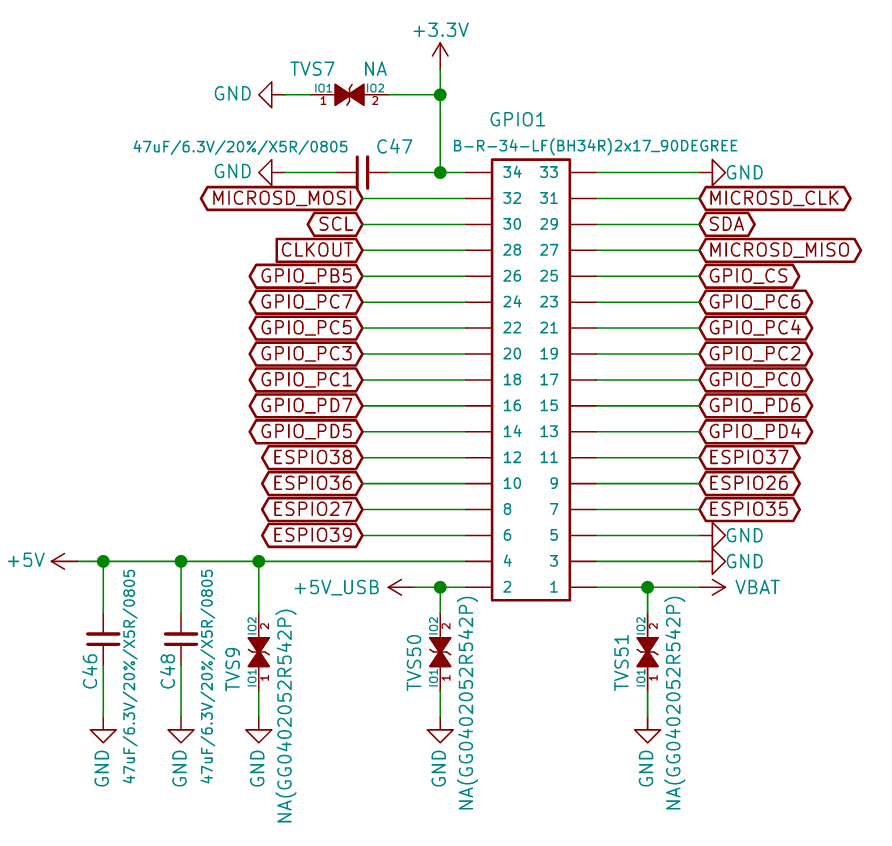
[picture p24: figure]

Pin.1 is connected to the Li-Po battery PLUS you can connect external battery on this pin or to use battery voltage to external circuits.

Pin. 2 is 5V power supply connected to USB-C +5V signal, you can power the board from this signal if the USB-C is not connected. It must be regulated 5V power supply, applying more than 5V will damage the board.

Pin.3, Pin.5, Pin.33 are GND

Pin.34 is +3.3V output capable to source up to 2A note that 200mA are used by AgonLight2

Pin.4 is +5V output capable to source up to 2A (1.8A + AgonLight2 0.2A), it’s backed by LiPo UPS so even if there is interruption on power supply if LiPo battery is attached there will be 5V on this pin.

All GPIOs operate at +3.3V levels. This means you should not connect signals above 3.3V to these ports as this will damage the board.

## UEXT connector

UEXT connector stands for Universal EXTension connector and contain +3.3V, GND, I2C, SPI, UART signals:

UEXT is 0.1” 2.54mm step boxed plastic connector. All signals are with 3.3V levels.

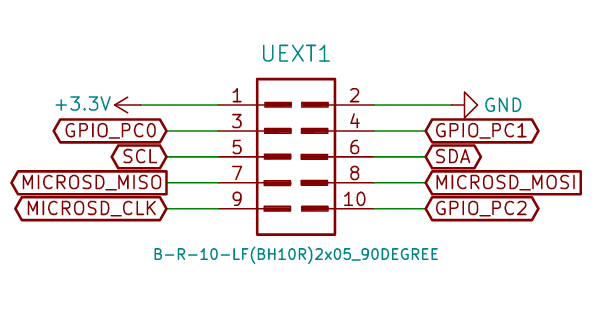
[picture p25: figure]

Olimex has developed number of MODULES (https://www.olimex.com/Products/Modules/) compatible with this connector. There are temperature, humidity, pressure, magnetic field, light sensors. Modules with LCDs, LED matrix, relays, Bluetooth, Zigbee, WiFi, GSM, GPS, RFID, RTC, EKG, etc.

## Access bus connector

This is I2C and power supply with 3.3V levels.

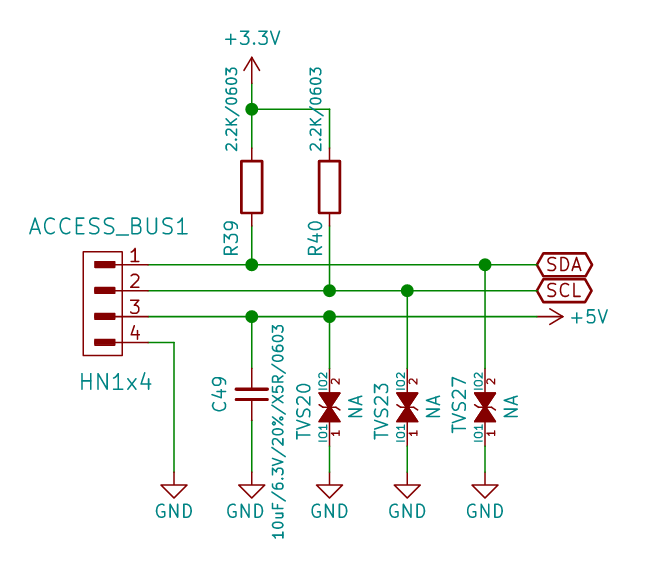
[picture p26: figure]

## eZ80 programming connector

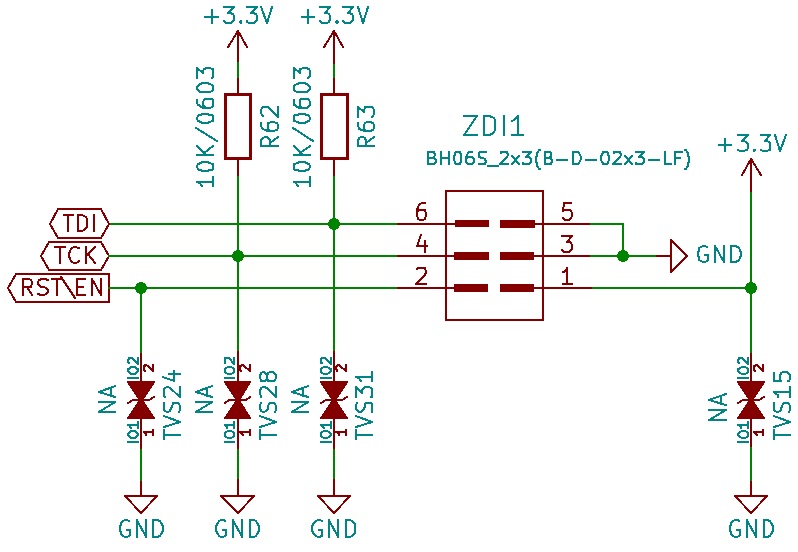
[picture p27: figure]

This connector is used for initial programming of eZ80 microcontroller. AgonLight2 comes with pre-programmed firmware so you do not need to use this connector nor programmer for it.

If you want to develop your own firmware Jeroen Venema (https://github.com/envenomator/Agon/tree/master/Programs/flash)wrote flash utility (https://github.com/envenomator/Agon/tree/master/Programs/flash) which allows you to flash new firmware without need of external programmer.

## Jumpers

Typically you don’t need to change the positions of the jumpers to use the board.

BUZ_EN1 – buzzer enable jumper – when closed the buzzer plays the sound commands.

Default state: Open (Buzzer disabled)

ESP_PROG1 – ESP programming enabled when closed ESP32 enters bootloader mode at reset and can be programmed over the USB connector.

Default state: Open (ESP programming handled by software)

UART_D – UART disable – when closed the UART connection between eZ80 and ESP32 is disconnected. This is necessary when ESP32 is programming.

Default state: Open (communication between eZ80 and ESP32 enabled)

# SOFTWARE

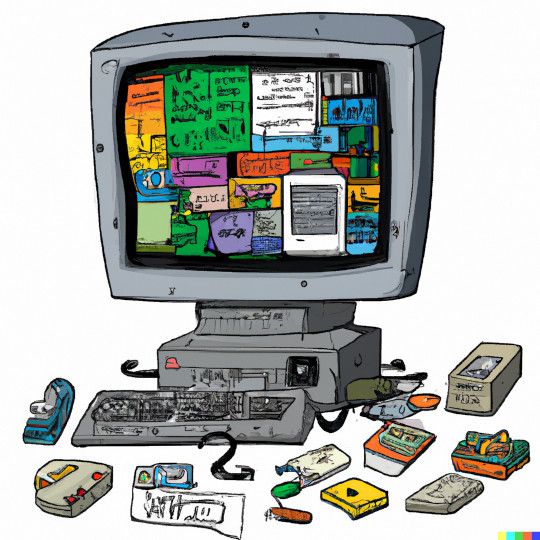
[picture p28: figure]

## Official AgonLight Firmware

The three modules of AgonLight official firmware, called Quark™, can be found here:

- Quark™ BBC BASIC (https://github.com/breakintoprogram/agon-bbc-basic/releases) – BBC Basic interpreter
- Quark™ MOS (https://github.com/breakintoprogram/agon-mos/releases) - command line machine operating system, similar to CP/M or DOS
- Quark™ VDP (https://github.com/breakintoprogram/agon-vdp/releases) - The VDP is a serial graphics terminal that takes a BBC Basic text output stream as input. The output is via the VGA connector on the Agon.

## Extra info about AgonLight2 firmware:

A properly operating AgonLight2 system has three software components Quark™ VDP + Quark™ MOS + Quark™ BBC BASIC. By default each Olimex AgonLight2 board comes with VDP and MOS already programmed. You only need to download the basic and the examples to an SD card to start using the AgonLight2 board. For the BASIC, MOS updater, CP/M and other examples and test programs you need a micro SD card in FAT or FAT32 format and a SD card writer. Micro SD cards are purchased separately.

Notice that certain combinations of versions of VDP, MOS and basic might be incompatible. Meaning that you might need to upgrade or downgrade MOS, VDP, basic in order to run the board. If in doubt, use the versions we provide.

It is always recommended to get the latest files and instructions from the official VDP, MOS, BASIC locations listed below:

• Quark™ BBC BASIC – https://github.com/breakintoprogram/agon-bbc-basic/releases – BBC Basic interpreter

• Quark™ MOS – https://github.com/breakintoprogram/agon-mos/releases – command line machine operating system, similar to CP/M or DOS

• Quark™ VDP – https://github.com/breakintoprogram/agon-vdp/releases – the VDP is a serial graphics terminal that takes a BBC basic text output stream as input. The output is via the VGA connector on the Agon.

However, if you encounter problems use the versions we have provided at our GitHub, we have tested them and confirmed them to work:

https://github.com/OLIMEX/AgonLight2/tree/main/SOFTWARE

The "1-SD-card-contents" folder contains sub-folders with files for the SD card, also mos files that can be flashed via bootloader without programmer (if possible);

The "2-AgonLight2-VDP-XXX" folder contains VDP;

The "3-AgonLight2-MOS-XXX" folder contains MOS that can be flashed via programmer.

## BASIC and demo installation

Brand new AgonLight2 board requires only the contents of folder “1-SD-card-contents” to start. Copy the contents from the "1-SD-card-contents" into the root directory of a micro SD card.

The content involves:

1) bbcbasic.bin (current version is 1.04, for the latest one check: https://github.com/breakintoprogram/agon-bbc-basic);

2) autoexec.txt which runs the BASIC on restart;

3) basic_examples_tests – various BASIC examples/test/games programs;

4) Agon-CPM2.2 – contains CPM;

5) mos – contains files suitable for updating mos without programmer.

### Agon Quark VDP installation

For the Agon Quark VDP on the ESP32 chip you have to install IDE, package and libraries:

1) Arduino IDE

1.1) Go to: https://www.arduino.cc/en/software

1.2) While this will most likely work with 2.x.x we recommend you to download 1.8.9 which is shown a little bit below in the section "Legacy IDE (1.8.x)"

1.3) Download, install and run it

2) Install the ESP32 package

2.1) Go to "Main menu -> Preferences" (CTRL+,)

2.2) In the "Additional Boards Manager URLs" add in a new line: https://raw.githubusercontent.com/espressif/arduino-esp32/gh-pages/package_esp32_index.json

2.3) Go to "Main menu -> Tools -> Board -> Boards manager..."

2.4) Look for the package "ESP32" (since there are lots of packages you can filter them by typing "ESP32" in the search bar on the top)

2.5) Install the package (it is tested with 2.0.9v but later are likely to work)

3) Install the FabGL library

3.1) Go to "Main menu -> Sketch -> Include Library -> Manage Libraries..." (CTRL+SHIFT+I);

3.2) Look for library FabGL (just like the packages earlier you can filter all the libraries by typing "FabGL" in the search bar);

3.3) Install it (it is tested with 1.0.8, newer versions of the library may not work);

4) Compile and Upload the firmware (Agon Quark VDP);

4.1) Open the sketch 2-AgonLight2-VDP-104-RC1.ino(the provided one is version 1.04RC1, for the latest one check https://github.com/breakintoprogram/agon-vdp );

4.2) Go to "Main menu -> Tools -> Board -> ESP32 Arduino" and select "ESP32 Dev Module";

4.3) Plug the USB to the AgonLight2 board;

4.4) In Device manager you can see the COM# at which our device has connected;

4.5) Go to "Main menu -> Tools -> Port" select the one ESP32 has connected;

4.6) Go to "Main menu -> Tools -> PSRAM" select Enabled;

4.7) Compile and Upload (every time after opening the project in Arduino the first compilation is VERY slow – be patient).

### Agon Quark MOS installation on the eZ80 chip

1) If there is no MOS at all or it's older than 1.02 you must have "ZILOG eZ80F92" programmer and have to install IDE:

1.1) Download "ZDS II - eZ80Acclaim!" from here: https://zilog.com/index.php?option=com_zcm&task=view&soft_id=54&Itemid=74 (tested with 5.3.5 but should work with newer versions)

1.2) Install the IDE and run it

1.3) Go to "Main menu -> File -> Open Project" and navigate to "3-AgonLight2-MOS-104-RC1/MOS.zdsproj" (the provided version is 1.04-RC1, for the latest one check https://github.com/breakintoprogram/agon-mos )

1.4) Build the project (F7)

1.5) Connect the programmer to the ZDI connector on the AgonLight2 board

1.6) Go to "Main menu -> Debug -> Download the code"

1.7) When the download is complete go again to "Main menu -> Debug -> Stop Debugging" (SHIFT + F5)

1.8) Disconnect the programmer from the board

2) If there is MOS 1.02 and you want to update it to a newer version you can still use the method described above but you can also do it from the console on the AgonLight2 board itself without the need of the programmer and IDE

## Olimex tested firmware and examples

These can be found in the repository here:

https://github.com/OLIMEX/AgonLight2/tree/main/SOFTWARE/

Disclaimer: Most of the examples located in the repository above are NOT written by Olimex. We have just tested them and confirmed them working at the time of release, then re-hosted them. The repository contains: examples taken from AgonLight repository (https://github.com/TheByteAttic/AgonLight/tree/main/uSD%20card%20files), solutions to our weekly programming challenge, and other interesting examples we found online.

## MOS commands

LOAD “”

SAVE “”

*CAT *DIR

*CD /

*MKDIR

*BYE *CPM

*ERA file

*ESC [ON OFF]

*EXEC file

*OPT

*REN oldfile ewfile

*SAVE file aaaa bbbb

*SPOOL file

*TYPE file

*| comment

## BBC Basic commands reference

Variables:

X – float

X% - integer

X$ - string

&X – hex

Pressing ESC key breaks the code execution

This is list of the BBC Basic commands click on the command name for more info and use.

ABS

ACS

ADVAL

AND

ASC

ASN

ATN

AUTO

BGET

BPUT

CALL

CHAIN

CHR$

CLEAR

CLG

CLOSE

CLS

COLOUR

COS

COUNT

DATA

DEF

DEG

DELETE

DIM

DIV

DRAW

ELSE

END

ENDPROC

ENVELOPE

EOF

EOR

ERL

ERR

ERROR

EVAL

EXP

EXT

FALSE

FN

FOR

GCOL

GET

GET()

GET$

GOSUB

GOTO

HIMEM

IF

INKEY

INKEY$

INPUT

INSTR(

INT

LEFT$

LEN

LET

LINE

LIST

LN

LOAD

LOCAL

LOG

LOMEM

MID$

MOD

MODE

MOVE

NEW

NEXT

NOT

OFF

OLD

ON ERROR

ON ERROR OFF

ON X%

OPENIN

OPENOUT

OPT

OR

PAGE

PAGE

PI

PLOT

POINT(

POS

PRINT

PROC

PTR

PUT A, X

RAD

READ

REM

RENUMBER

REPEAT

REPORT

RESTORE

RETURN

RIGHT$(

RND

RUN

SAVE

SGN

SIN

SOUND

SPC

SQR

STEP

STOP

STR$

STRING$(

TAB(X)

TAB(X,Y)

TAN

THEN

TIME

TO

TRACE

TRUE

UNTIL

USR

VAL

VDU

VPOS

WIDTH

## Software access to GPIOs

eZ80 ports are described in the eZ80-specification (https://www.zilog.com/docs/ez80/ps0130.pdf).

Port direction register set if the port is INPUT or OUTPUT. Upon RESET all GPIOs are set as Inputs.

Direction registers are 8 bit and each bit corresponds to port signal. If 1 is written on the corresponding port will be set as Input if 0 as Output.

Port B data direction register is at address: 009Bh = 153 decimal

Port C data direction register is at address: 009Fh = 159 decimal

Port D data direction register is at address: 00A3h = 163 decimal

If we read the Port C direction register we can PRINT GET(159) and it should return 255

If we want to set GPIO_PC0 as output we should write 0 in bit 0 with the command PUT 159,254.

Data registers are 8 bit and each bit corresponds to port signal. If 1 is written on the corresponding port will be set 3.3V if 0 is written 0V will be set.

Port B data register is at address: 009Ah = 152 decimal

Port C data register is at address: 009Eh = 158 decimal

Port D data register is at address: 00A2h = 162 decimal

If we read data register with GET() command, for instance PRINT GET(158) it will return the state of Port C.

We can write the data register with PUT command, for instance PUT 158,1 will set GPIO_PC0 to +3.3V and PUT 158,0 will set it to 0V.

## Software access to I2C

TBD

## Software access to SPI

TBD

## Software access to VPU

TBD

## Text Editors:

- AED: Another Text Editor (https://github.com/avalonbits/aed) – Another Text Editor.
- nano (https://github.com/lennart-benschop/agon-utilities#nano) – Editor with nano-style key bindings.
- Vi (https://github.com/tomm/toms-agon-experiments/tree/main/vi) – Vi for the Agon series of eZ80 computers.

## Programming Languages:

- AgDev (https://github.com/pcawte/AgDev) – Port to Agon Light of TI-84-CE C/C++ Toolchain which uses LLVM and generates eZ80 ADL code.
- agon-ez80asm (https://github.com/envenomator/agon-ez80asm) – ez80 assembler, running natively on the Agon platform.
- Agon Forth (https://github.com/lennart-benschop/agon-forth) – Forth for Agon computer.
- BBC Basic (https://github.com/breakintoprogram/agon-bbc-basic) – Official AGON QUARK Firmware: BASIC Interpreter.
- BBC Basic ADL (https://github.com/breakintoprogram/agon-bbc-basic-adl) – Official AGON QUARK Firmware: BASIC Interpreter (ADL version).
- Turbo Rascal Syntax Error (https://lemonspawn.com/turbo-rascal-syntax-error-expected-but-begin/) – TRSE is a complete suite (IDE, compiler, programming language, resource editor) intended for developing games/demos for 8 / 16-bit line of computers.
- Z88DK (https://github.com/z88dk/z88dk) – The Development Kit for Z80 Computers.

## Operating systems:

- CP/M 2.2 for Agon Light (https://github.com/nihirash/Agon-CPM2.2) – CP/M 2.2 port for Agon Light that didn’t require custom firmware. Use your Agon fully and have access to CP/M system.
- TRS-OS for Agon Light (https://github.com/sijnstra/agon-projects/tree/main/OSboot) – A bootstrap to run TRS-OS on Agon Light under MOS. TRS-OS is an eZ80 port of the LS-DOS TRS-80 operating system. No firmware change required.
- Zeal-8-bit-OS for Agon Light (https://github.com/sijnstra/agon-projects/tree/main/OSbootZ) – A bootstrap to run Zeal 8-bit on the Agon Light under MOS. No firmware change required.

## Games:

- AgonLight Game Library (https://github.com/eightbitswide/AgonLight-Game-Library) – Games for the BBC Micro and Electron converted for AgonLight.
- Agon Light Invaders (https://github.com/pgregory/agon-light-invaders) – Invaders for the Agon Light.
- Dans la prison hantée (https://mokona78.itch.io/dans-la-prison-hante) – This prison is haunted. But this prison also hides a treasure. And finding treasures is your job.
- Diamond Quest (https://github.com/richardturnnidge/diamond) – eZ80 game on AgonLight. A simple game, built purely as a goal to learn z80 assembly routines on the Agon Light.
- Draegerman (https://github.com/8BitVino/draegerman) – Draegerman for Agon Light.
- Drug Wars (https://github.com/oldpatientsea/DRUG-WARS-for-the-Agon-Light) – An adaption of the DOS version of the game, converted to BBC BASIC (Z80) for the Agon Light.
- Escape the Mansion (https://github.com/richardturnnidge/adventure) – Multi-room graphical adventure.
- Game of Life (https://github.com/craiglp/agon-life) – Conway’s Game of Life for the Agon Light.
- Haunted_House (https://github.com/lovejoy777/Haunted_House) – Agon Light2 Text Adventure Game, written in BBC BASIC.
- Haunted House III (https://github.com/The-8bit-Noob/Haunted-House-III) – Haunted House Text Adventure Game for the Agon Light2.
- Lunar Lander (https://github.com/richardturnnidge/lunar_lander) – Lunar Lander Game.
- Pitman (https://github.com/xianpinder/Agon/tree/main/Pitman) – Port of Pitman, written in BBC BASIC.
- Realm (https://github.com/NicholasPratt/Realm) – An adventure game for Agon Light.
- Rokky (https://github.com/nihirash/Agon-rokky) – Dungeons and Diamonds game for Agon Light.
- Sargon Chess (https://github.com/sijnstra/agon-projects/tree/main/sargon) – Port of the award-winning Sargon Chess program by Dan and Kathe Spracklen from 1978.
- Sokoban (https://github.com/envenomator/agon-sokoban) – A custom port of the Sokoban game for the Agon platform.
- Space Birds (https://github.com/james7780/Agon_SpaceBirds) – A simple game written in C for the Agon Light retro computer.
- The Valley (https://github.com/james7780/The-Valley) – Agon Light conversion of The Valley adventure game.
- TINACOT (https://github.com/tonedef71/agon-tinacot) – An original game inspired by tower defense games and Tetris.
- Vezza (https://sijnstra.itch.io/vezza-agon) – Vezza is a tool for running Infocom compatible (Z-machine) text adventure games.
- Wizard’s Castle (https://github.com/thrazen/AgonLight) – The Wizard’s castle modded for BBC Basic on the Agon Light.

## Connectivity:

- Snail (https://github.com/nihirash/Agon-MOS-Tools/tree/main/esp8266/snail) – Fast gopher browser for Agon Light (and Agon Light 2)

## Music:

- Agon MOD (https://github.com/HeathenUK/agon_mod) – Agon .MOD tracker.

## Utilities:

- agon_64cfontloader (https://github.com/eightbitswide/agon_64cfontloader) – Load .64c fonts on the Agon in BBC BASIC.
- Agon Basic Header (https://github.com/The-8bit-Noob/AGON_BASIC_HEADER) – Agon Light 2 Basic Header.
- Agon Bootlogo (https://github.com/sijnstra/agon-projects/tree/main/bootlogo) – Assembler MOSlet bootlogo of the Basic Header.
- Agon Flash (https://github.com/envenomator/agon-flash) – Agon firmware update utility.
- Agon Hex (https://github.com/HeathenUK/agon_hex) – Agon hex editor.
- Agon Light 2 Serial Printer (https://github.com/tdg8934/Agon-Light-2-Serial-Printer) – Mini Thermal Receipt Printer (Serial RxD).
- Agon Utilities (https://github.com/lennart-benschop/agon-utilities) – MOS utilities for Agon: copy, view, editor…
- Agon Utils (https://github.com/vascocosta/agon-utils) – Utilities for the Agon Light computer.
- calc24 (https://github.com/sijnstra/agon-projects/tree/main/calc24) – 24 bit integer calculations in both hex and decimal.
- Console8 Recover (https://github.com/envenomator/console8-recover) – Console8 MOS recover utility.
- HEXLOAD utility (https://github.com/envenomator/agon-hexload) – Utility for the Agon platform, to load Intel HEX files over one of its serial ports.
- More Agon Utilities (https://github.com/sijnstra/agon-projects/tree/main) – MOS utilities including gunzip, hexdump tools for interactive navigation of file or memory, strings to extract strings from a binary file

# Beginners resources:

AgonLight FAQ (https://github.com/envenomator/Agon-FAQ) by Jeroen Venema

AgonLight wiki (https://github.com/breakintoprogram/agon-docs/wiki) by Dean Belfield

# DOCUMENT REVISION

Revision 1.0 January 2023

- initial release

Revision 1.1 January 2023

- added “How to prepare the SD card and boot the first time”, taken and edited from “Agon light™ Firmware Installation Guide.pdf”

Revision 1.2 June 2023

- general improvements to the structure of the document; added more info about first steps with the board

Revision 1.3 July 2023

- general improvements to the structure of the document; fixed links; added info about firmware and firmware update

Revision 1.5 July 2023

- bug fixes around names of folders and instructions;

Revision 1.6 July 2023

- updated schematics with latest ones

Revision 1.7 September 2023

- reverted title page and removed table of related products

Revision 1.8 October 2023

- added dimensions

Revision 1.9 March 2024

- added Software and FAQ

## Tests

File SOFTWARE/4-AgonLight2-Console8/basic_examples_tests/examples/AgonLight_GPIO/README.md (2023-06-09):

# AgonLight_GPIO

## Background
Agon Light is a compact low-cost board that is both a microcomputer and a BASIC-programmed microcontroller. It is intended to be easily hackable and allow interfacing with the outside world. It features 20x GPIO, plus SPI, I2C, UART for serial communication and allows a great opportunity for learning and experimentation.

## Introduction 

This repo is intended to provide some simple add on boards for gpio examples and experiments. Although I am of the 8 bit vintage, I consider myself a novice. I enjoy hardware making as a way to better understand the inner hardware workings and to ultimately improve my coding. All is a work in progress and is open to contributions and ideas, within the stated aims and limitations of this project.

## Aims
* Provide a range of simple IO hardware to aid coding in BBC BASIC.
* To be useful in gaining a general understanding of GPIO usage and real world interfacing.
* Stick to the general GPIOs only.
* Avoid cables and breadboards and try to fit a standardised form factor. In this case a plugable "faceplate" for the exiting gpio port. The board should avoid constraining any existing ports and access.
* Ideally, provide onboard visual feedback to aid learning.
* Avoid additional hardware processing on the add on board. Keeping access to the low level hardware prevents adding more complications when learning. I.e. GALs, additional controller ICs are to be avoided.

## The PCBs

KiCad, Schematics and Gerbers are provided. Renders of the boards are shown in the KiCad directory. Please review before making a commitment. No warranties or support are provided. As of this date PCBs are not yet tested but I will mark as such once done.

#### #1 - The Blinkenlight. - tested working


Every 8 bit computer needs blinky lights. Not only do they look like good, they are useful for debugging and understanding what is going on at a bit level.
The Blinkenlight PCB is pretty much the breadboard example from the official documentation but without the fiddly wires. It directly plugs into the GPIO header and provides an easily viewable "faceplate". This presents the form for future boards.

#### #2 - 7 segment display. - tested working


This is a single 7 segment display linked to the Port C GPIOs. Allows a simple message display with a delay. Ok its only single digits but something to build on.
A caution on this is that you need a 7 segment display to suit the pin out (they do vary). Review the schematics, Pin 3 and 8 are power.I have provided a solder jumper for setting of common anode and common cathode displays. Note that for common anode the coding assumes a LOW signal for on and HIGH for off.

#### #3 - Double Seven


**In progress.**

This is a **double** 7 segment display linked to the Port C GPIOs for data and 2No. Port D GPIOs to do the multiplexing.
To save space resistor networks are used instead of individual resistors.

#### #4 - Moody. - tested working


This is an RGB LED linked to the Port C GPIOs, 2No. push buttons are also provided. The two push buttons on PC_3 and PC_4 are to establish some input and mode switching capability. 

## The Code

I have created some code to introduce the boards. As said, codng is not my strength so excuse the code, in some cases its not a great example but enough to get things going and for a challenge to improve.

| Board | Code | Description |
|:---|:---|:-----|
|[#1_Blinkenlight](https://github.com/Kayto/AgonLight_GPIO/tree/main/KiCad/%231_Blinkenlight) | [PortC_blink.bbc](https://github.com/Kayto/AgonLight_GPIO/tree/main/Code) | select individual LEDs, set number of blinks and speed. |
|[#1_Blinkenlight](https://github.com/Kayto/AgonLight_GPIO/tree/main/KiCad/%231_Blinkenlight) | [gpioknight.bbc](https://github.com/Kayto/AgonLight_GPIO/tree/main/Code)| Some blinky patterns. Excuse the code, its a bad example with lots of inefficient duplication to get things done. The **challenge** is open to simplify this, perhaps a data array for the gpio commands and a single procedure for the delay?|
|[#2_seven_segment](https://github.com/Kayto/AgonLight_GPIO/tree/main/KiCad/%232_7Segment)|  [diceroll.bbc](https://github.com/Kayto/AgonLight_GPIO/tree/main/Code) | A random 1-6 generator for board games, handy. | 
|[#2_seven_segment](https://github.com/Kayto/AgonLight_GPIO/tree/main/KiCad/%232_7Segment)|  [counter.bbc](https://github.com/Kayto/AgonLight_GPIO/tree/main/Code) | A single digit counter, you're welcome. | 
|[#4_Moody](https://github.com/Kayto/AgonLight_GPIO/tree/main/KiCad/%234_Moody)|  [moodyfade.bbc](https://github.com/Kayto/AgonLight_GPIO/tree/main/Code) | An RGB fade using some crude PWM in BBC BASIC. | 
|[#4_Moody](https://github.com/Kayto/AgonLight_GPIO/tree/main/KiCad/%234_Moody)|  [moodybutton.bbc](https://github.com/Kayto/AgonLight_GPIO/tree/main/Code) | The RGB fade but now includes buttons. Button A for on and off. Button B to increase the fade speed.| 

## Disclaimer & Credits

Just a note that I am not in any way affiliated or linked with the Agon project.
I am just an aspiring maker, sharing hobbyist builds.
Thanks to the Agon project and supporters.

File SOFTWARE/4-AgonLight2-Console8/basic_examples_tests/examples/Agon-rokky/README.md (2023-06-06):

# Rokky - Small Rocks'n'Diamonds-like game for Agon Light



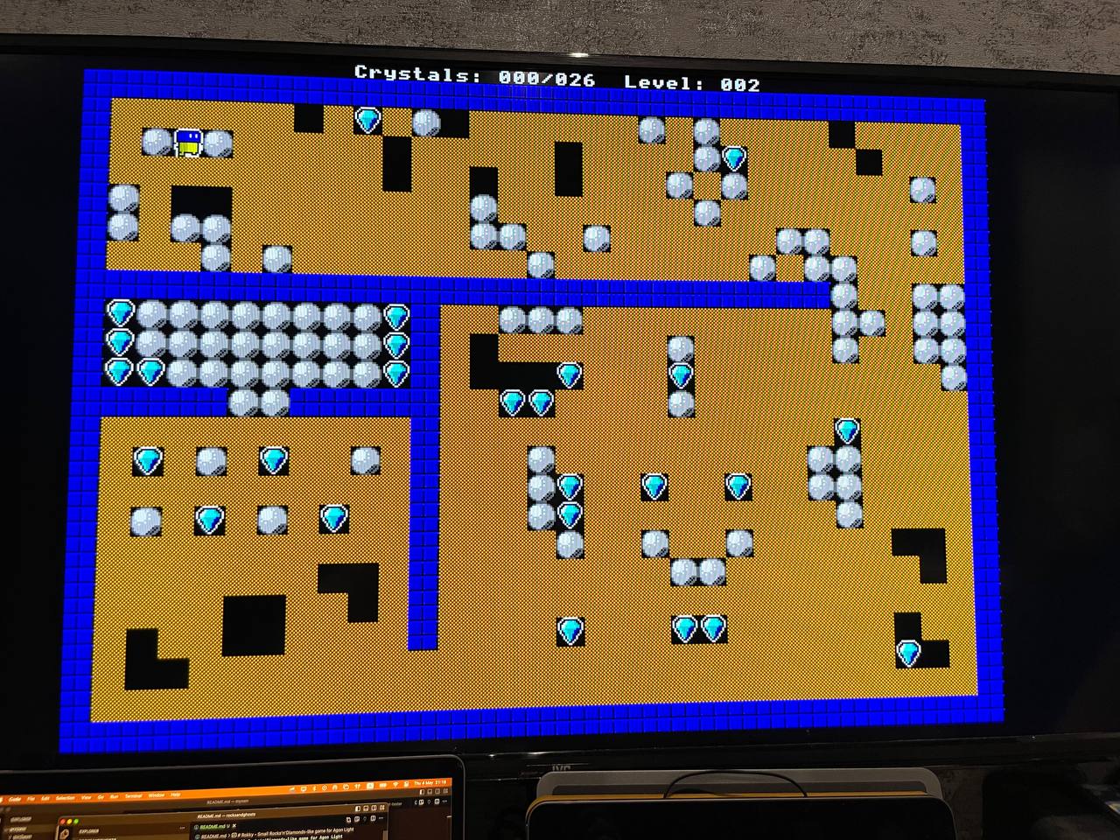
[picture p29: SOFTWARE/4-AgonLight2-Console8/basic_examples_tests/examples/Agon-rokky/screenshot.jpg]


## Playing game

Just copy binary to SD card - load and run it from MOS and enjoy game.

## Development

Code written directly on Agon Light and compiled with [agon-ez80asm](https://github.com/envenomator/agon-ez80asm). I'm strongly recommend use latest version of ez80asm - cause it updates often and goes better and better every day.

I'm using [Nano](https://github.com/lennart-benschop/agon-utilities) text editor for Agon Light for writting code directly on Agon.

Images just converted with imagemagick.

Levels was created in CharPad tool(use 32x23 size and `chars.raw` font - included in repo) and you'll can make new levels or edit existings. 

## Known issues

Rarely(really) cursor key can be "locked". Press this direction again and it will be fixed - it happens cause I'm reading OS var for scan codes and even button pressed and button released and it can happens if I lost one even. 

I didn't found another way make controls so responsive without using external devices(like joystick).

## Licensing

Rokky licensed with [Nihirash's Coffeware License](LICENSE). 

It isn't hard to respect it.

Happy hacking!

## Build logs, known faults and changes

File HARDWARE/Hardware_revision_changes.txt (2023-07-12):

Hardware revision changes for AgonLight2

Board revision can be identified by the white print. It is printed on the board itself. Boards were designed with KiCAD.

--- Hardware revision B (initial release)

First public release. Major changes compared to hardware revision A:

1. VGA and audio jack moved to the left 1mm;
2. ZDI connector pinout fixed;
3. R22 now 2.2K, moved between B and C of transistor for feedback;
4. Improved the logo print;
5. R41 now NA;
6. Improved keyboard design, R35 and R36 now NA;
7. R17 now 10K.

--- Hardware revision A (preliminary, unrleased)

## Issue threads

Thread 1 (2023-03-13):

suggestion: add agon-light topic

andypiper, 2023-03-13:
Could you add the [agon-light](https://github.com/topics/agon-light) GitHub topic to this repository, to aid in community discovery of related resources? Thanks! 🙏🏻

TsvetanUsunov, 2023-04-15:
Done

Closed 2023-04-15.

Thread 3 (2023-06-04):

Firmware is out of date for Version of Quark (MOS/VDP v 1.03) Currently Being Shipped

oldpatientsea, 2023-06-04:
New Agon Lights are being shipped with 1.03 but this repo still includes firmware (i.e. BBC BASIC for Z80 plus example and test files) that is incompatible with 1.03.

I have seen several new users tripping over this recently on Facebook and Discord.

Perhaps it makes sense to replace the cached firmware in this repository with a README pointing users to the official agon-bbc-basic repository instead, along with a brief explanation of which versions of BASIC work with which versions of Quark just in case people who bought older stock of the boards that shipped with 1.02 (or earlier?) come looking for firmware.

Also worth noting that if you find you need to press ENTER twice after each line in BASIC then you are running an incompatible, earlier version since this is what new users notice immediately.

DanKoloff, 2023-06-09:
It should be now updated, thanks for notice.

DanKoloff, 2023-06-16:
Yeah we just copy-pasted these and added some more:

https://github.com/TheByteAttic/AgonLight/tree/main/uSD%20card%20files

The idea was to place everything we've tested in one place instead of just posting links and throwing people left and right.

oldpatientsea, 2023-06-16:
I like your thinking :)

Yeah, that's a very good idea to have everything in one place and it makes sense that it would be the Olimex repo since you are the ones manufacturing and selling the board.

Unfortunately though the files you copied are out of date - if you look at the README in TheByteAttic's repository he warns "THE FILES ABOVE ARE APPROPRIATE ONLY FOR RELEASE 1.02 OF THE FIRMWARE."

You need to replace them with the ones from Dean's BBC BASIC repository, https://github.com/breakintoprogram/agon-bbc-basic

DanKoloff, 2023-06-19:
Thanks, will check it. On first look it appears the "Examples" are same if not older, will probably just delete "Examples" from our repo if they don't compile with the newer firmware.

theflynn49, 2023-07-10:
The files in "tests" still don't work, because (at least in my setup which says basic version 3.00) the lines in the .bas files all end with a single "0x0a" instead of "0x0d 0x0a". Once corrected, it works.

theflynn49, 2023-07-10:
I only considered the files in directory "tests"; I treated the file sound_1.bas to generate sound_2.bas. All files give me a "Bad program" message when I try to "LOAD" them, except sound_2.bas, the one I generated.
I have no idea where to fond basic 1.04, I only know the one in THIS repository which says "basic 3.00"
Or else, this linux command should answer your question :

file *
assembler_stub.bas: ASCII text
benchm1.bas:        ASCII text
benchm2.bas:        ASCII text
benchm3.bas:        ASCII text
benchm4.bas:        ASCII text
benchm5.bas:        ASCII text
benchm6.bas:        ASCII text
benchm7.bas:        ASCII text
benchm8.bas:        ASCII text
benchm9.bas:        ASCII text
BENCHMARK.md:       ASCII text
circle_1.bas:       ASCII text
circle_2.bas:       ASCII text
cube.bas:           ASCII text
fireworks.bas:      ASCII text
gpio_port_1.bas:    ASCII text
hatgraph.bas:       ASCII text
keyboard_1.bas:     ASCII text
lines.bas:          ASCII text
mandlebrot_1.bas:   ASCII text
mode_test_1.bas:    ASCII text
mode_test_2.bas:    ASCII text
palette_1.bas:      ASCII text
README.md:          ASCII text
rtc.bas:            ASCII text
scroll_1.bas:       ASCII text
scroll_2.bas:       ASCII text
shadows.bas:        data
sound_1.bas:        ASCII text
sound_2.bas:        ASCII text, with CRLF line terminators
sprites_1.bas:      ASCII text
sprites_2.bas:      ASCII text
sprites_3.bas:      ASCII text
sprites_4.bas:      ASCII text
sprites_5.bas:      ASCII text
sysvars.bas:        ASCII text
triangles.bas:      ASCII text
udg.bas:            ASCII text

theflynn49, 2023-07-10:
Regarding the bbcbasic version, it seems that version "3.00" is  version 1.04  (my file is identical to the one you gave me an url for, beside, it CAN read text-non-tokenized basic files, which means it has the 1.04 capabilities)

strings bbcbasic.bin | grep -i version
3BBC BASIC (Z80) Version 3.00
3BBC BASIC (Agon) Version 1.04

DanKoloff, 2023-07-10:
Thanks for info will look into it.

theflynn49, 2023-07-10:
Welcome.
I wonder where the problem really comes from though.
I just checked all files in the subtree "1-SD-card-contents", none has CRLF to terminate a line. On another hand, it's a very recent capability of bbcbasic to read non-tokenized files; so the old .BAS files format was due to a complete different publishing scheme and we are the first people to try LOADing these directly from bbcbasic.

To me, fixing bbcbasic to accept both CRLF and single LF text files should be the way to go ?

DanKoloff, 2023-07-12:
From what we see right now is that the original files had carriage return, but when we uploaded them to the GitHub carriage return disappeared, only LF is in the files at GitHub. Some setting made them Unix style.

oldpatientsea, 2023-07-12:
I haven't tested this but if you create a .gitattributes file and include the following it should force the .bas files to have the required CRLF line endings.

```
# Declare files that will always have CRLF line endings on checkout.
*.bas text eol=crlf
```

Note this will override any local settings so you may want to check with colleagues what else if anything this file should contain before creating it :)

See: https://docs.github.com/en/get-started/getting-started-with-git/configuring-git-to-handle-line-endings

BASIC currently shows the version number for the BBC BASIC (Z80) code on which it has been based rather than the BBC BASIC (Agon) version number. There is an open issue suggesting it display both on startup to reduce confusion: https://github.com/breakintoprogram/agon-bbc-basic/issues/54

DanKoloff, 2023-07-12:
Alright let's give it a try.

DanKoloff, 2023-07-12:
This seems to fix it. Interesting that we encounter this issue for first time. And I wonder why would it convert CRLF to just LF.

theflynn49, 2023-07-12:
Good news it's a git problem and not an Agon mess. Congrats for the elegant solution.
More historical info here : https://www.aleksandrhovhannisyan.com/blog/crlf-vs-lf-normalizing-line-endings-in-git/

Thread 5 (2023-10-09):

Please provide PS/2 - USB adapter circuit diagram

Durobot, 2023-10-09:
Since Olimex Agon Light 2 does away with PS/2 keyboard port, replacing it with a USB connector, but still requires a PS/2 compatible keyboard (which means Agon Light 2 can't function as a proper USB host), I assume a proper PS/2 keyboard should work too, with a simple passive adapter.

Could you please provide circuit diagram for such adapter?

PS/2 compatibility in USB keyboards is not advertised, and seems to be dying out anyway, so looking for a PS/2 keyboard appears to be an easier task.

Durobot, 2023-10-27:
> This schematics works fine.
Thank you so much!
Curiously enough, all the adapters in your photos are green, which normally means they're for mice, not keyboards 🤷‍♂️

nihirash, 2023-10-27:
> > This schematics works fine.
>
> Thank you so much! Curiously enough, all the adapters in your photos are green, which normally means they're for mice, not keyboards 🤷‍♂️

They're the same for mouse and keyboard and no contains active components - just sockets and wires

Closed 2023-10-27.

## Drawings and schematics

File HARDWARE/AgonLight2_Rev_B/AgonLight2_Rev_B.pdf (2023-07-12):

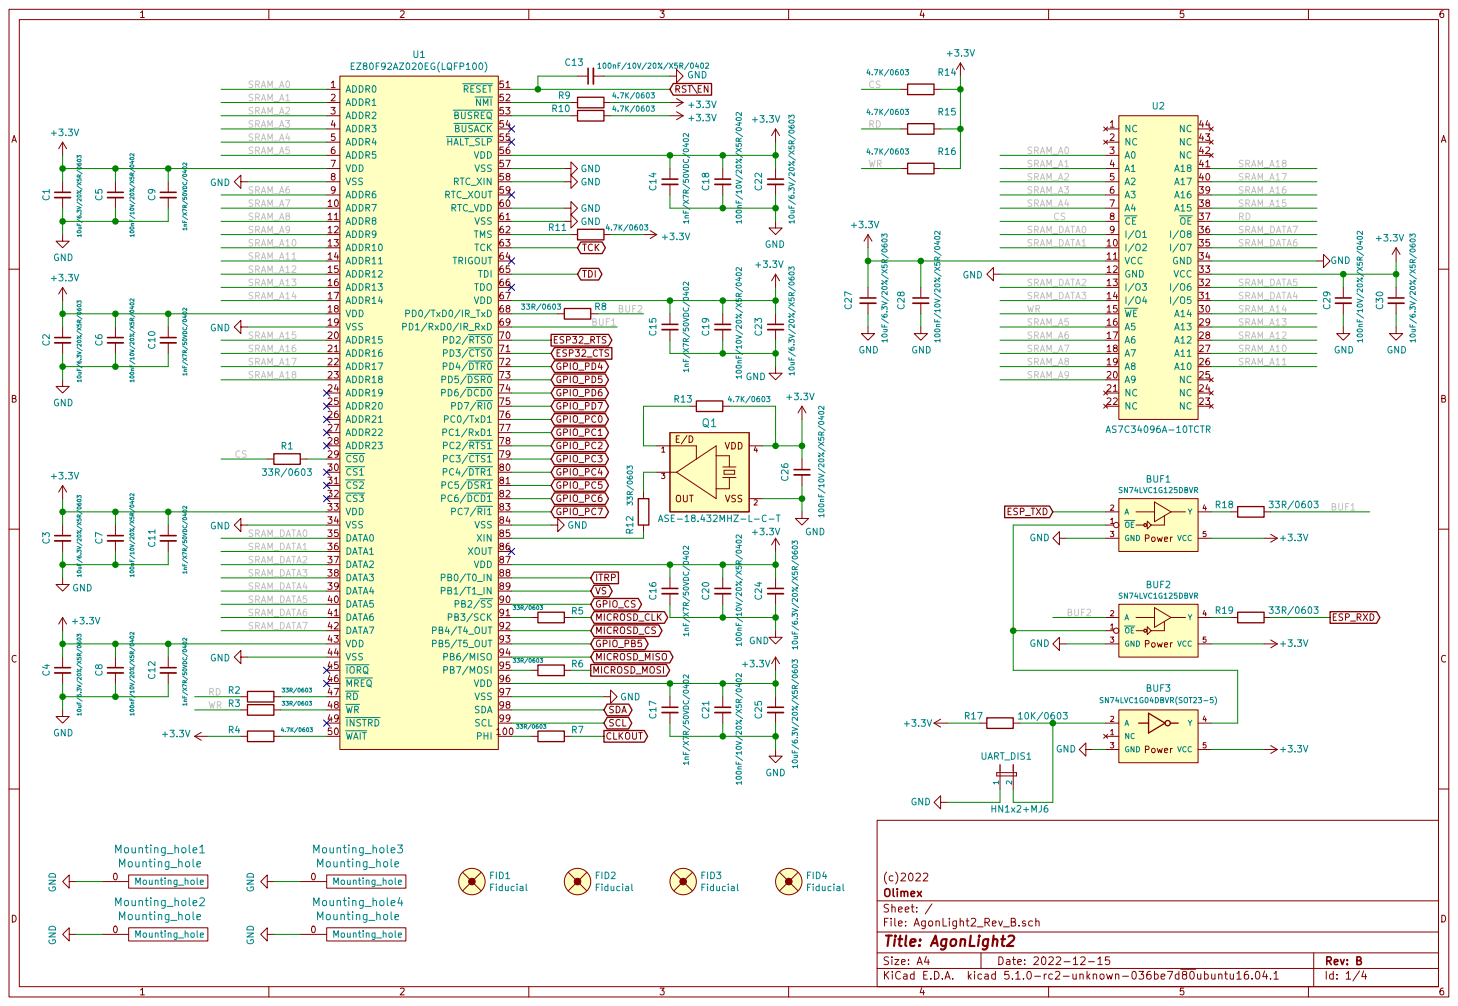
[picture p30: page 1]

+3.3V GND GND GND GND

File: AgonLight2_Rev_B.sch Sheet: / Olimex

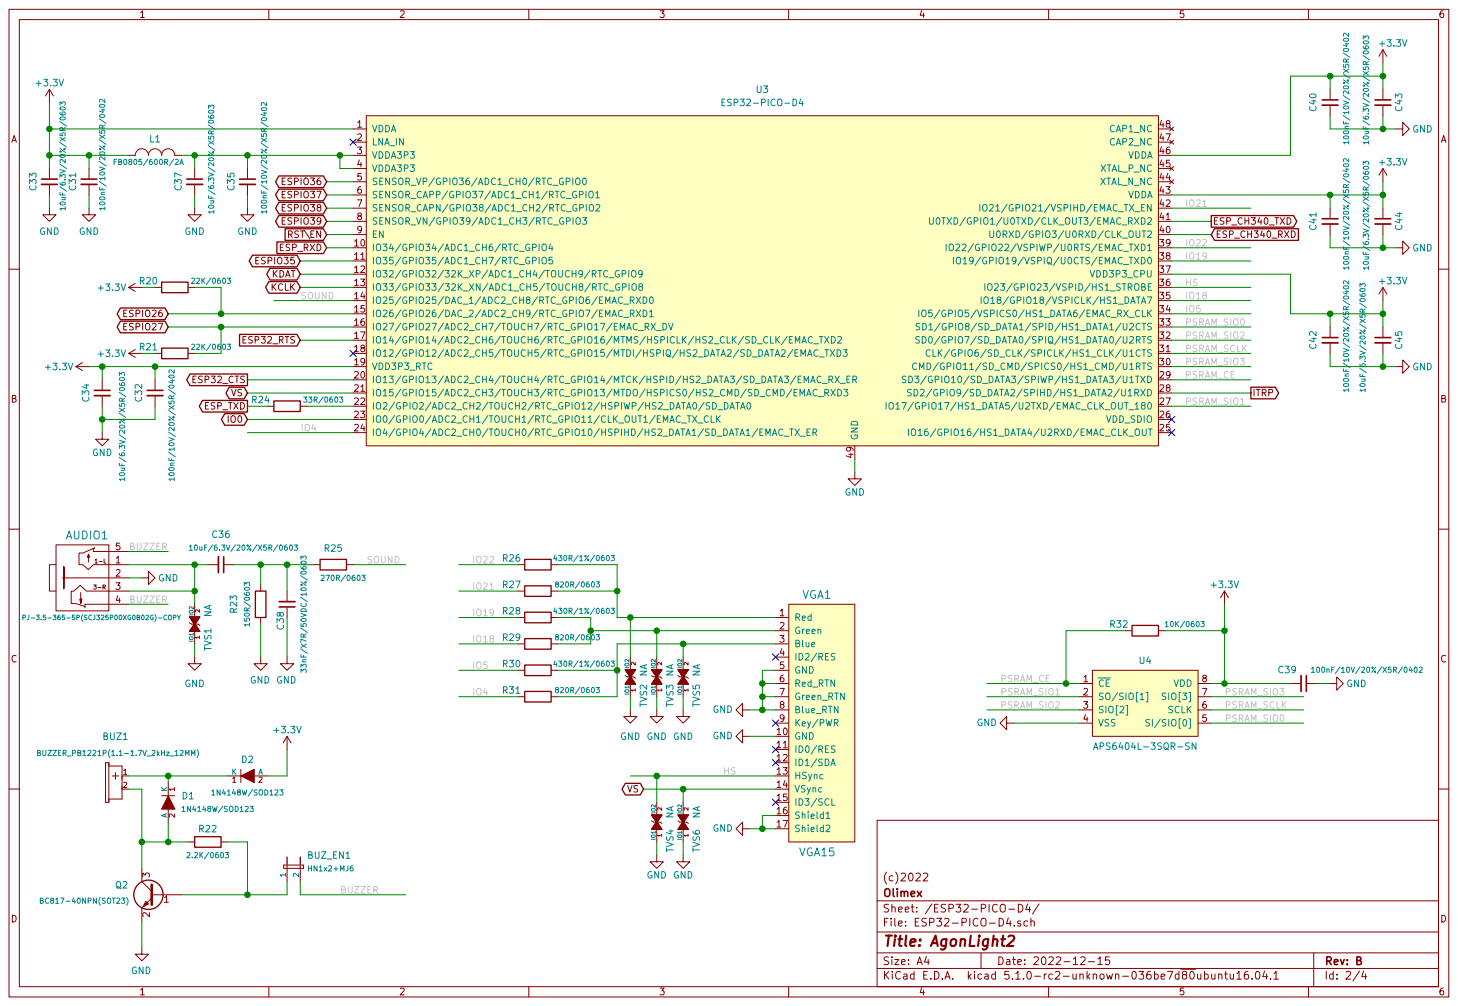
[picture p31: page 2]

ESP_CH340_RXD IO11 IO22 TVS5 NA GND IO11 IO22 TVS4 NA GND IO11 IO22 TVS6 NA GND IO11 IO22 TVS2 NA GND IO11 IO22 TVS3 NA GND

File: ESP32-PICO-D4.sch Sheet: /ESP32-PICO-D4/ Olimex

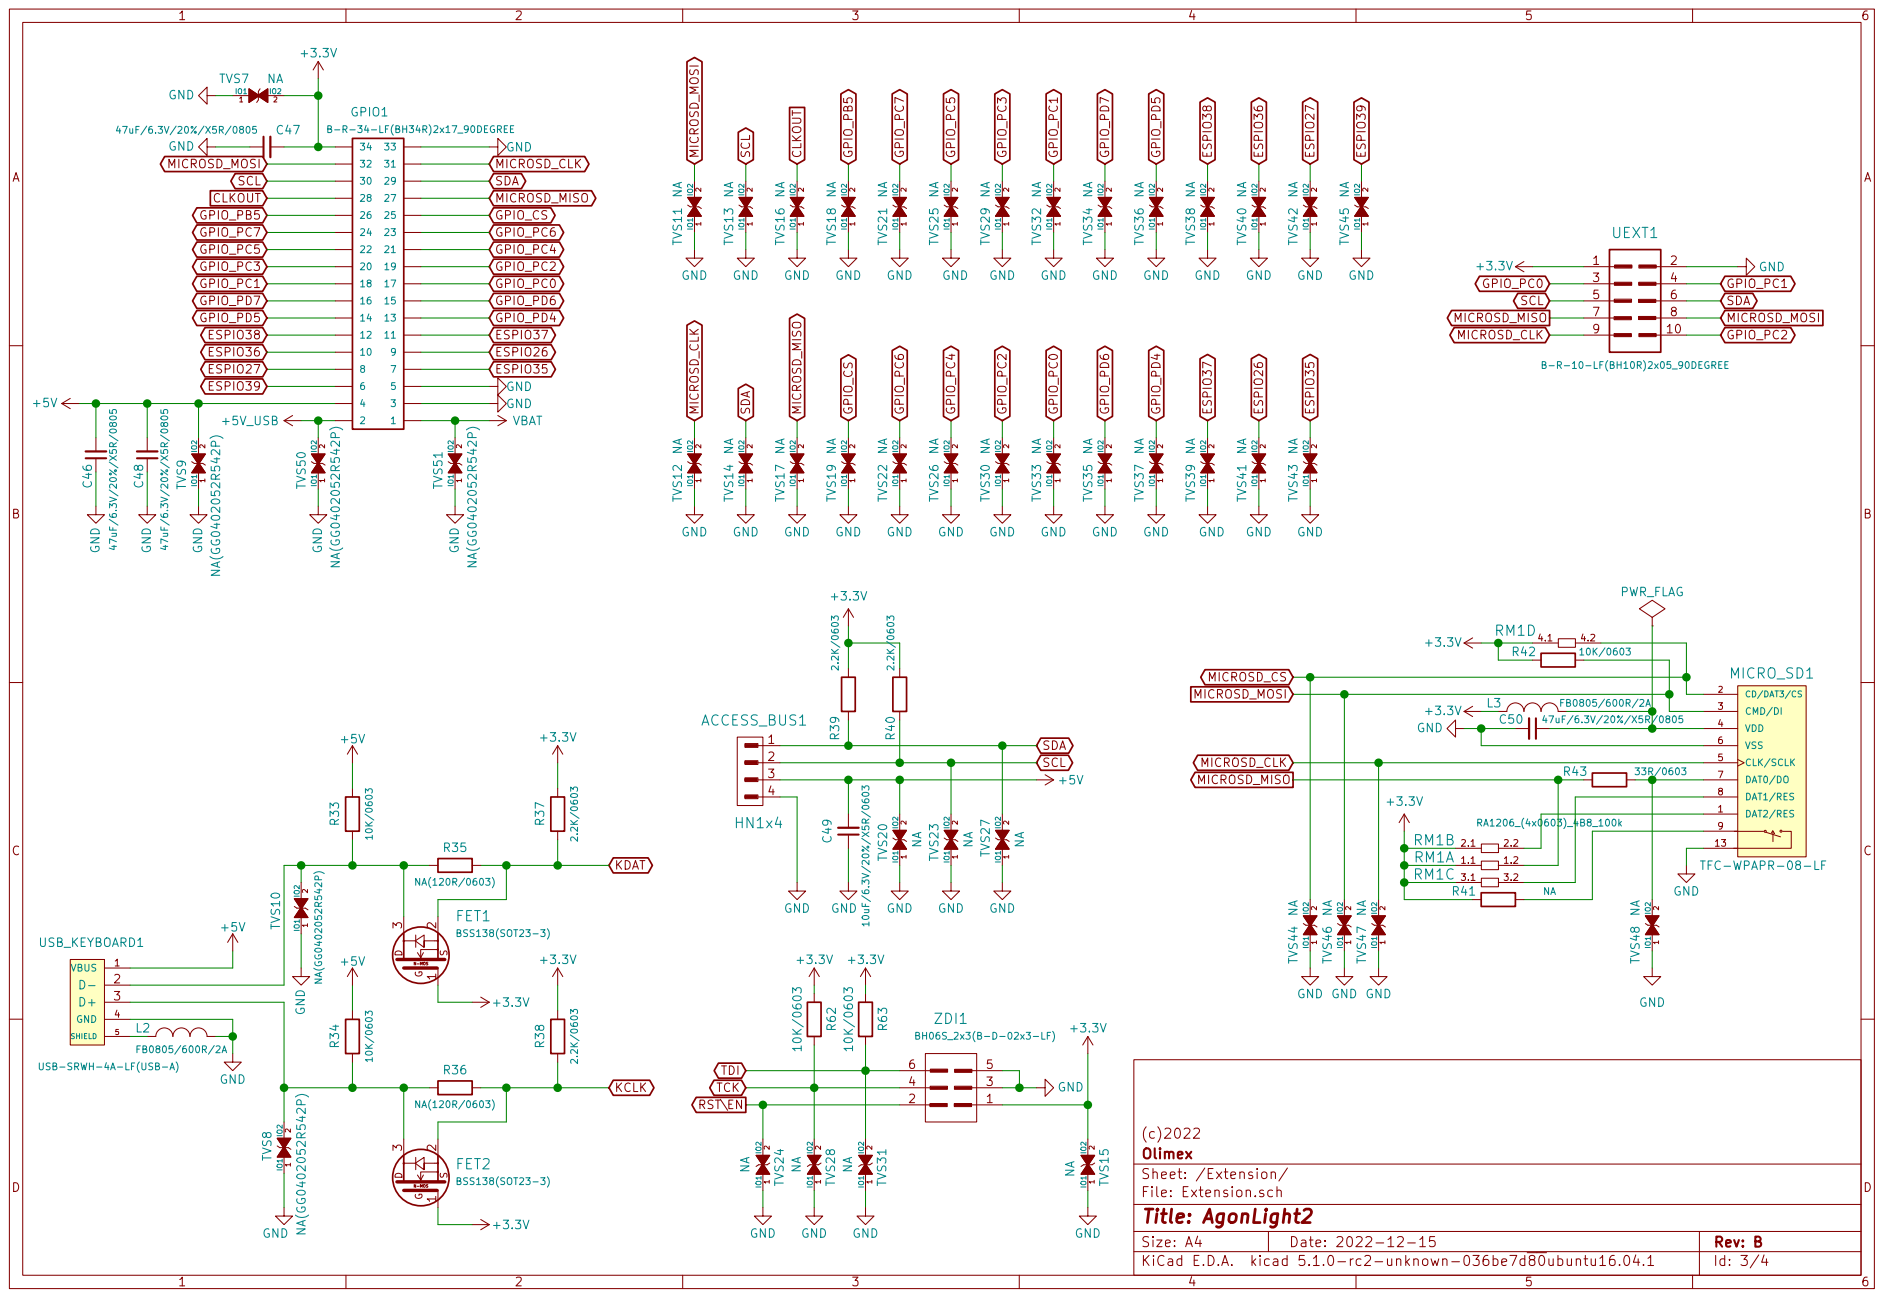
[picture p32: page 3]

File: Extension.sch Sheet: /Extension/ Olimex

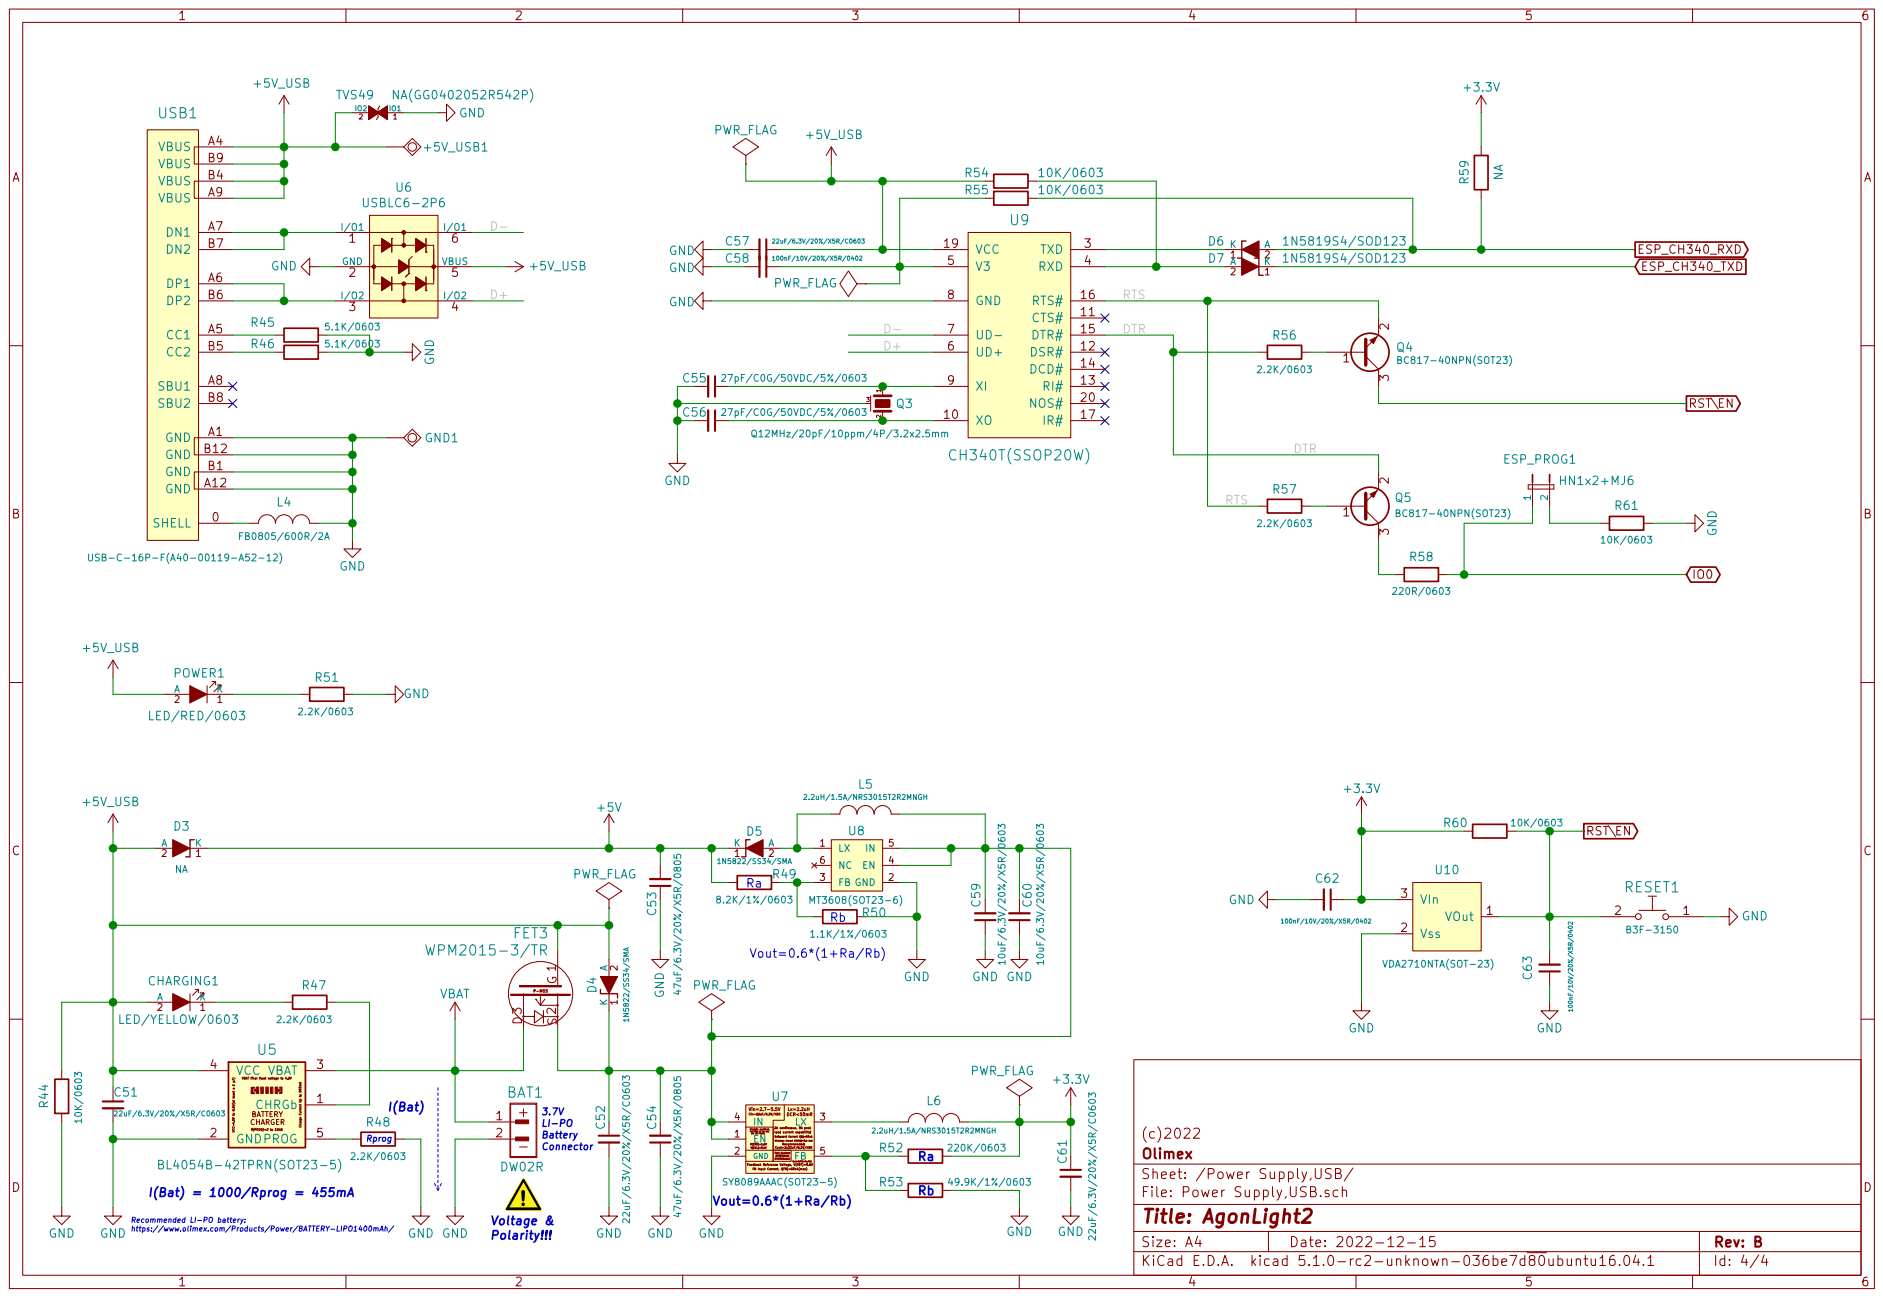
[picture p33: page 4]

load current capability! Lx=2.2uH

Do not float. Enable control. FB Input Current, I(FB)=50nA(max) Feedback Reference Voltage, V(REF)=0.6V

Sheet: /Power Supply,USB/ Olimex

File: Power Supply,USB.sch
Id: 4/4 Title: AgonLight2

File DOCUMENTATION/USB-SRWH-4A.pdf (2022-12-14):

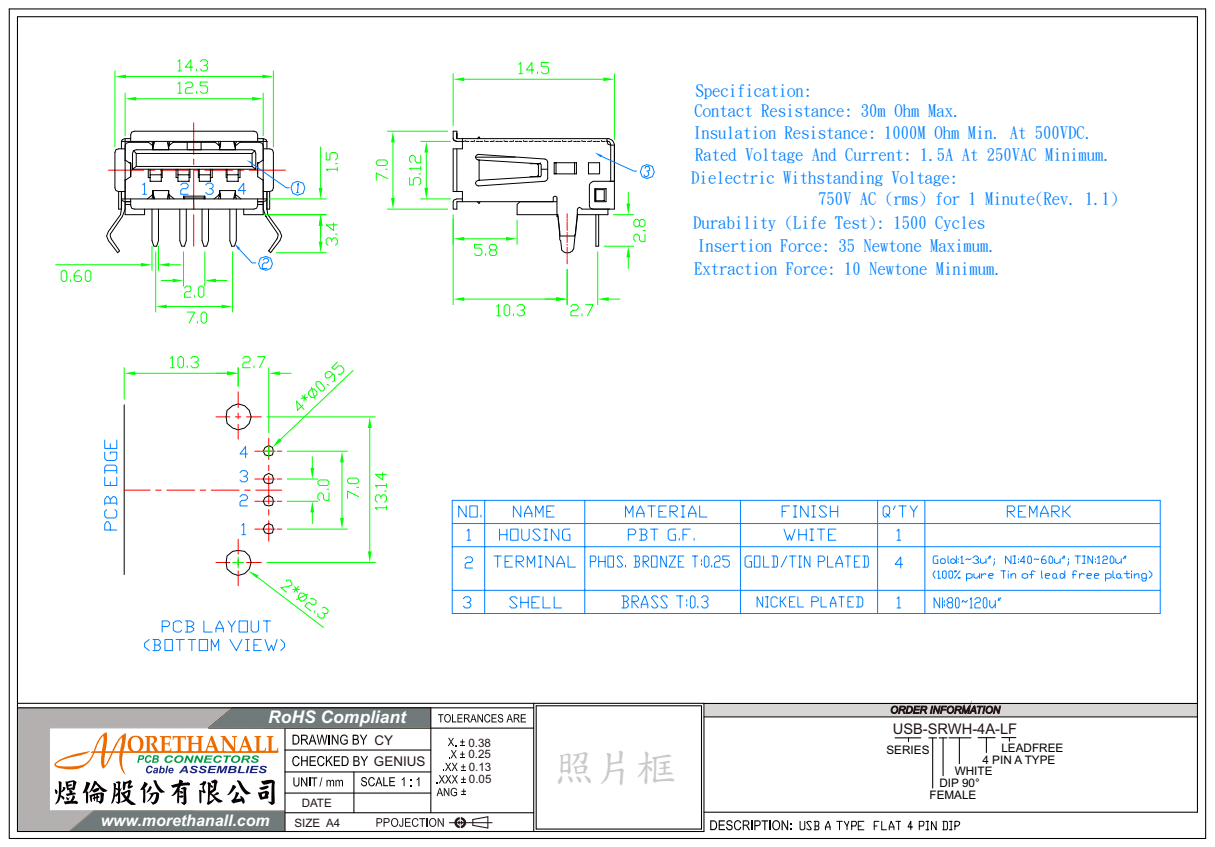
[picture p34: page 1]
GENIUS; SIZE A4; 照片框; WHITE; 4 PIN A TYPE; LEADFREE; DIP 90°; SERIES

Specification:
Contact Resistance: 30m Ohm Max.
Insulation Resistance: 1000M Ohm Min. At 500VDC.
Rated Voltage And Current: 1.5A At 250VAC Minimum.
Dielectric Withstanding Voltage:

750V AC (rms) for 1 Minute(Rev. 1.1)

Durability (Life Test): 1500 Cycles
Insertion Force: 35 Newtone Maximum.
Extraction Force: 10 Newtone Minimum.

ORDER INFORMATION
USB-SRWH-4A-LF | FEMALE

RoHS Compliant

DATE

www.morethanall.com

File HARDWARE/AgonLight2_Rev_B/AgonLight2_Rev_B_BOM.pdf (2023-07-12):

AgonLight2_Rev_B_BOM | 12/23/2022

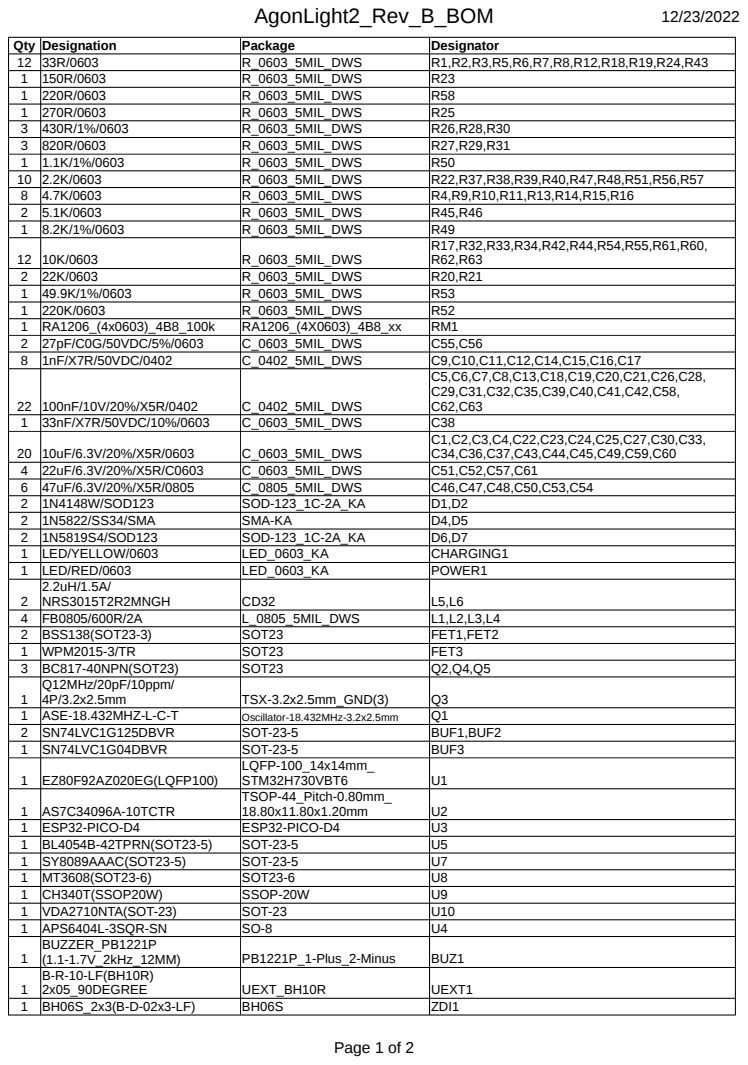
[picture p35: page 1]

AgonLight2_Rev_B_BOM | 12/23/2022
1 | BH34R | GPIO1
1 HN1x4 | HN1x4 | ACCESS_BUS1
1 DW02R | LIPO_BAT-CON2DW02R | BAT1
1 USBLC6-2P6 | SOT-666 | U6
1 B3F-3150 | B3F-31XX | RESET1
1 VGA15 | VGA15-F(CD0515S21J0) | VGA1
1 | SCJ325P00XG0B02G | AUDIO1
1 TFC-WPAPR-08-LF | TFC-WPAPR-08 | MICRO_SD1
1 | | USB1
1 USB-SRWH-4A-LF(USB-A) | USB_PN87520_HOST_PTH | USB_KEYBOARD1
3 HN1x2+MJ6 | HN1x2_Jumper | BUZ_EN1,UART_DIS1,ESP_PROG1
45 NA | D_0402_5MIL_DWS
6 NA(GG0402052R542P) | D_0402_5MIL_DWS | TVS8,TVS9,TVS10,TVS49,TVS50,TVS51
2 NA(120R/0603) | R_0603_5MIL_DWS | R35,R36
2 NA | R_0603_5MIL_DWS | R41,R59
1 NA | SMA-KA | D3

B-R-34-LF(BH34R)
2x17_90DEGREE

PJ-3.5-365-5P
(SCJ325P00XG0B02G)-COPY

USB-C-16P-F
(A40-00119-A52-12)

USB2.0_TYPE-C
(A40-00119-A52-12)

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

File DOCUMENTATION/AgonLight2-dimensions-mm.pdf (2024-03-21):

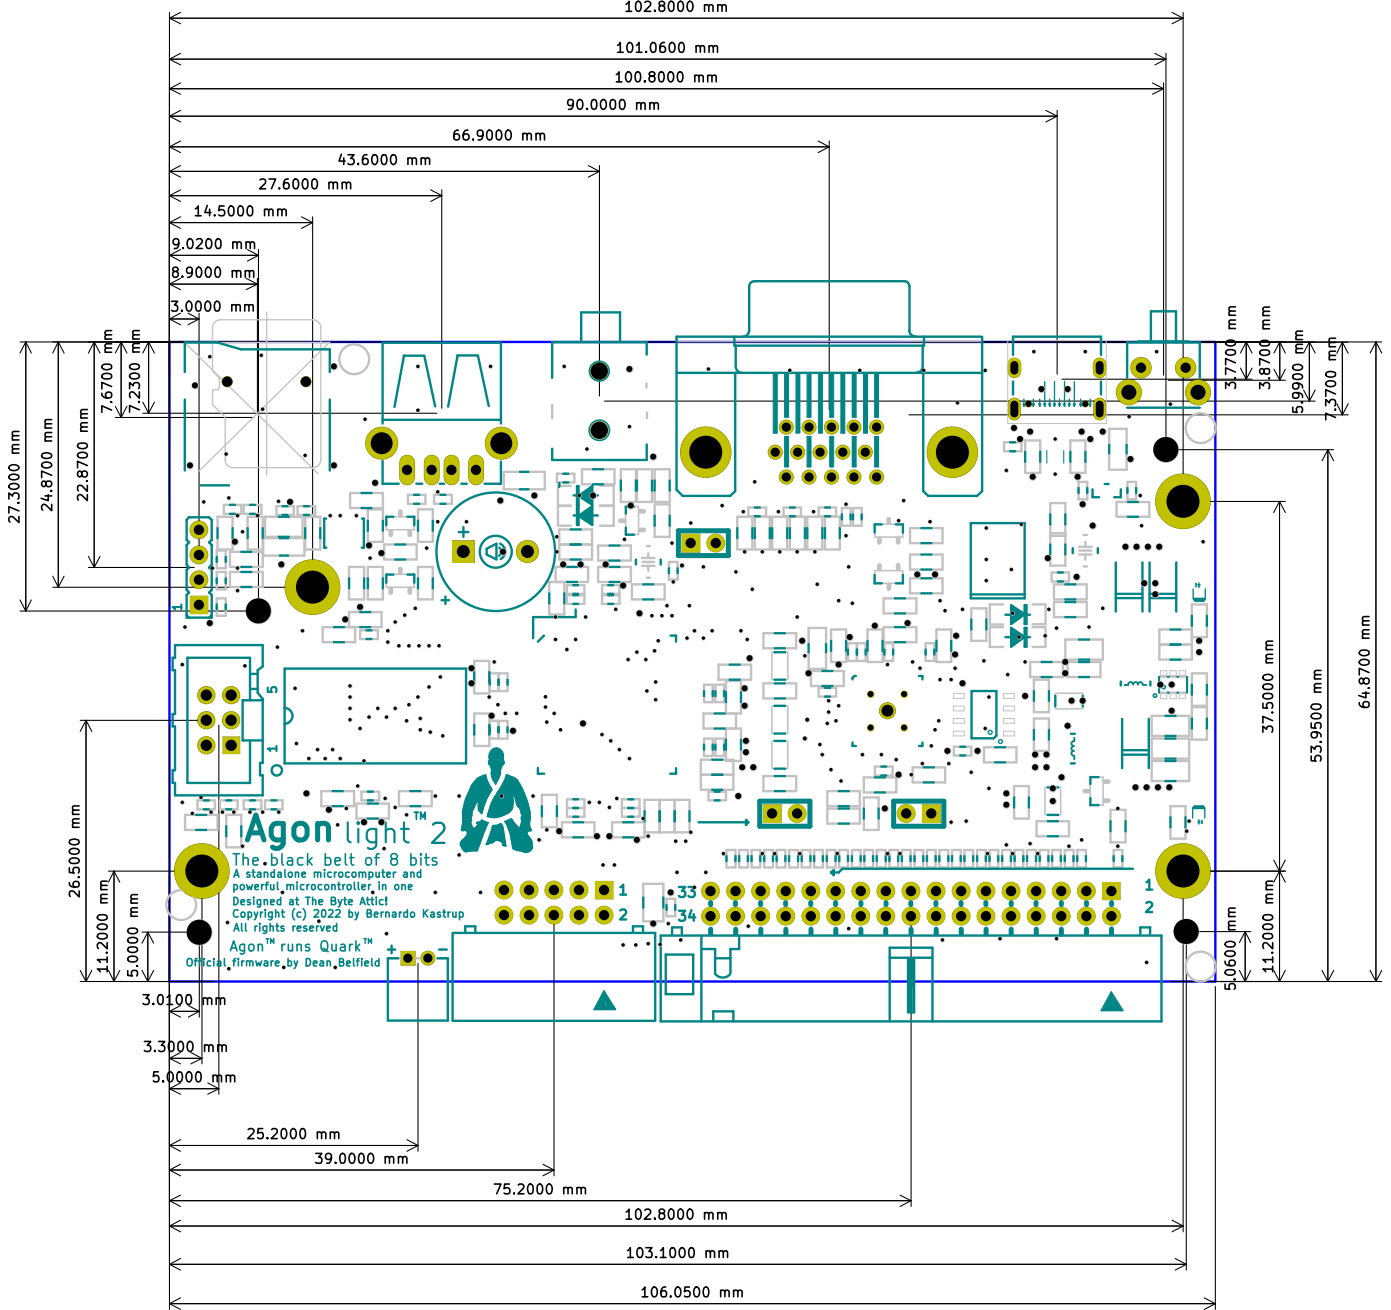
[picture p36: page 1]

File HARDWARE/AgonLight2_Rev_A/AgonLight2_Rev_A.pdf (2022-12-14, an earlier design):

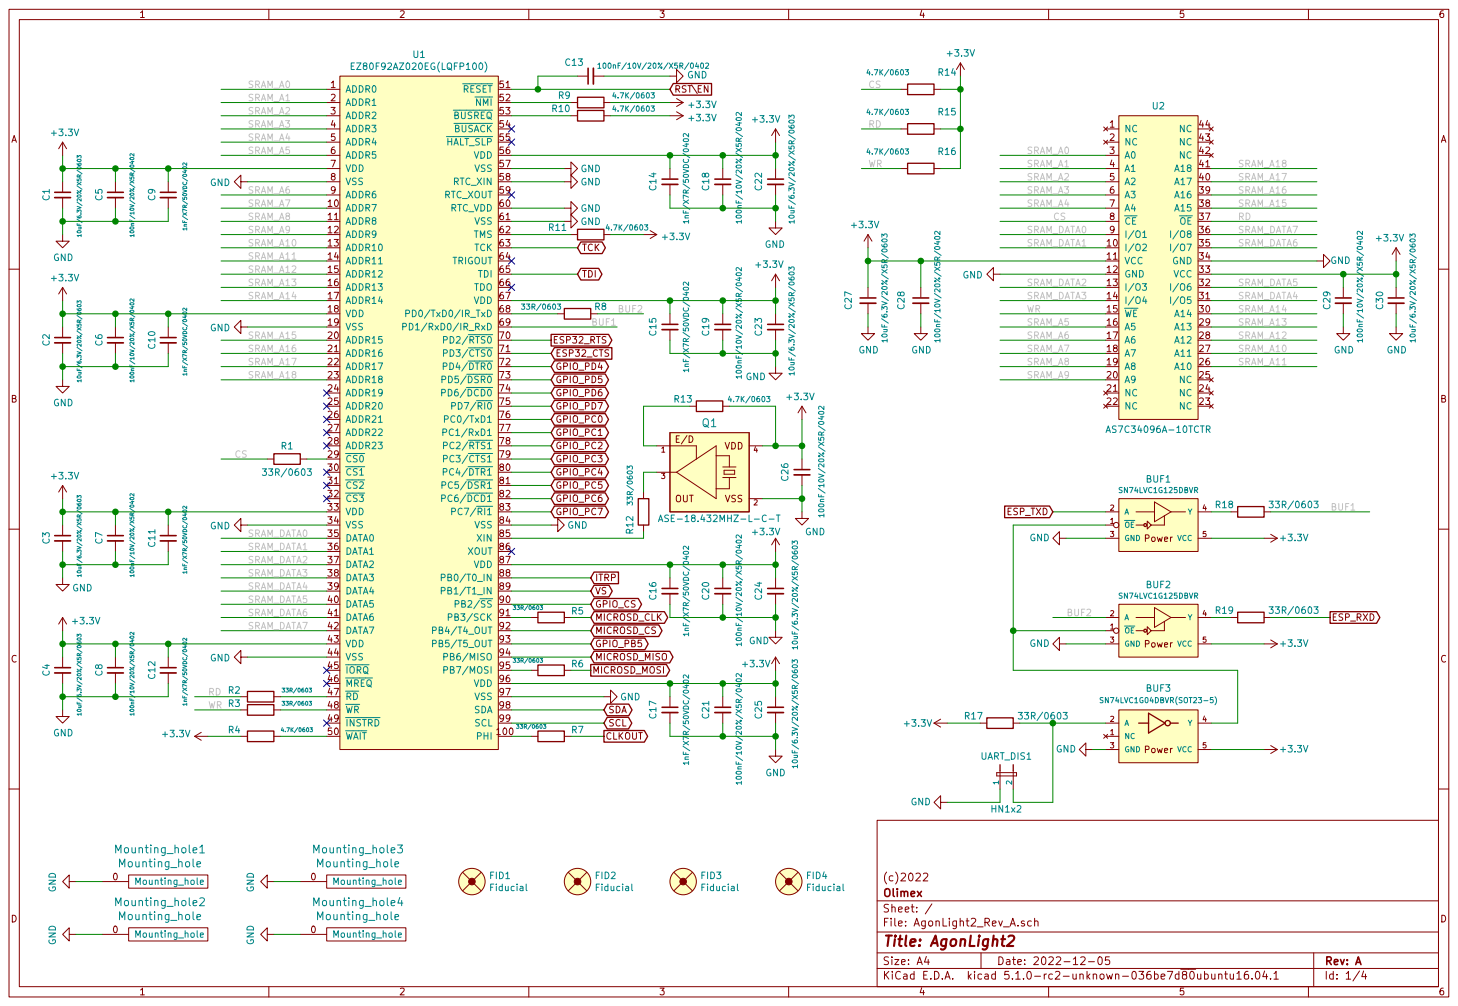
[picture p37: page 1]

+3.3V GND GND GND GND

File: AgonLight2_Rev_A.sch Sheet: / Olimex

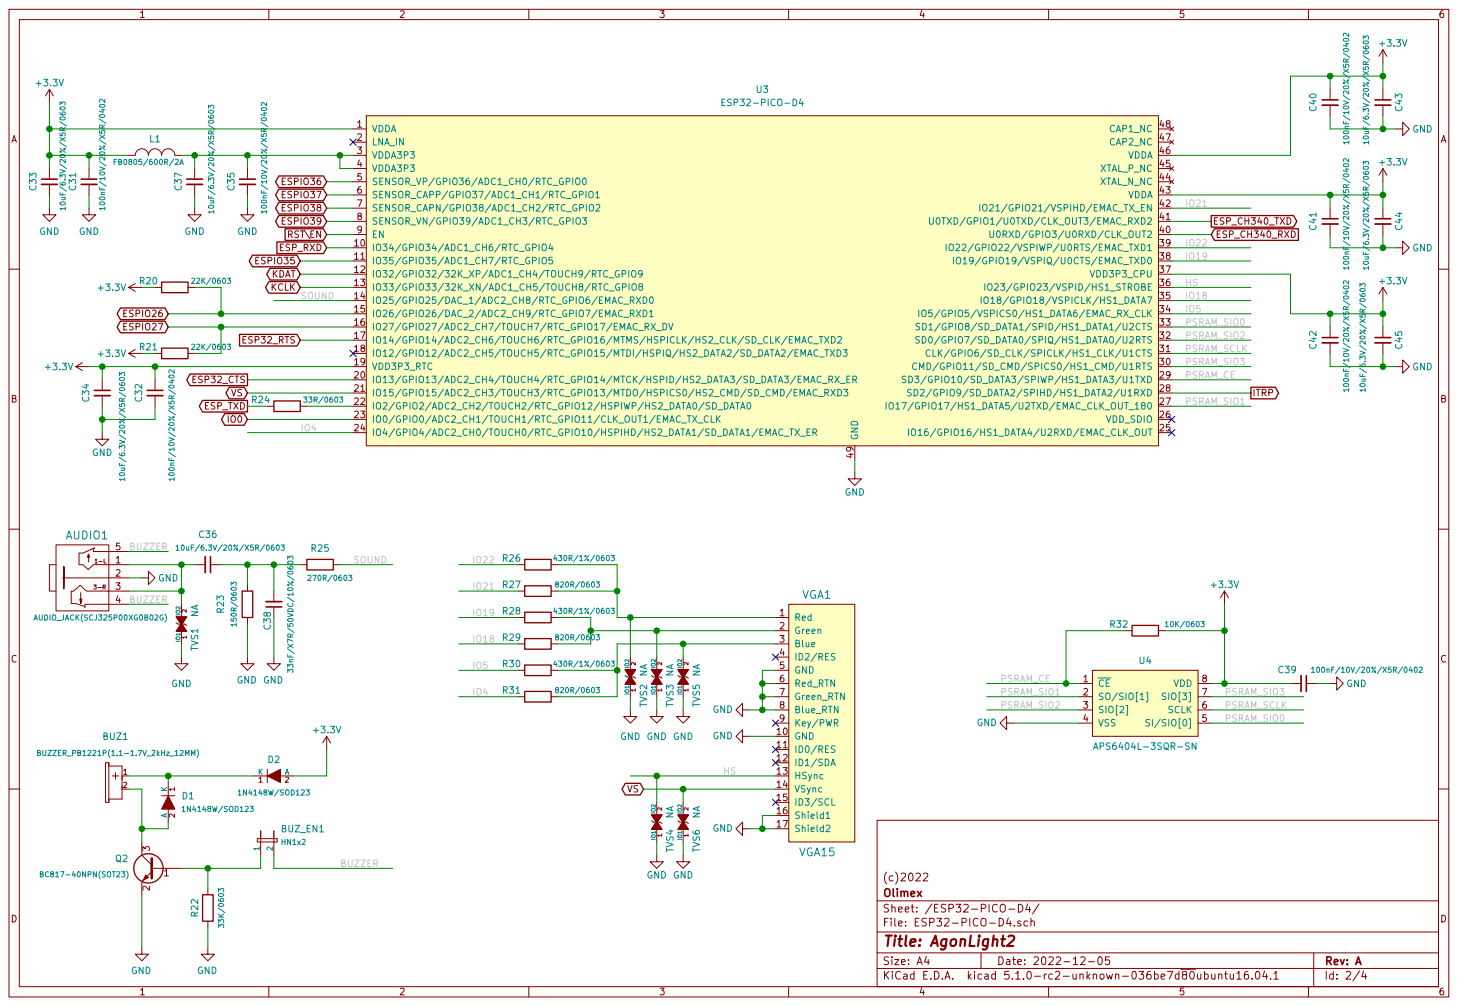
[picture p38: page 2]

ESP_CH340_RXD IO11 IO22 TVS5 NA GND IO11 IO22 TVS4 NA GND IO11 IO22 TVS6 NA GND IO11 IO22 TVS2 NA GND IO11 IO22 TVS3 NA GND

File: ESP32-PICO-D4.sch Sheet: /ESP32-PICO-D4/ Olimex

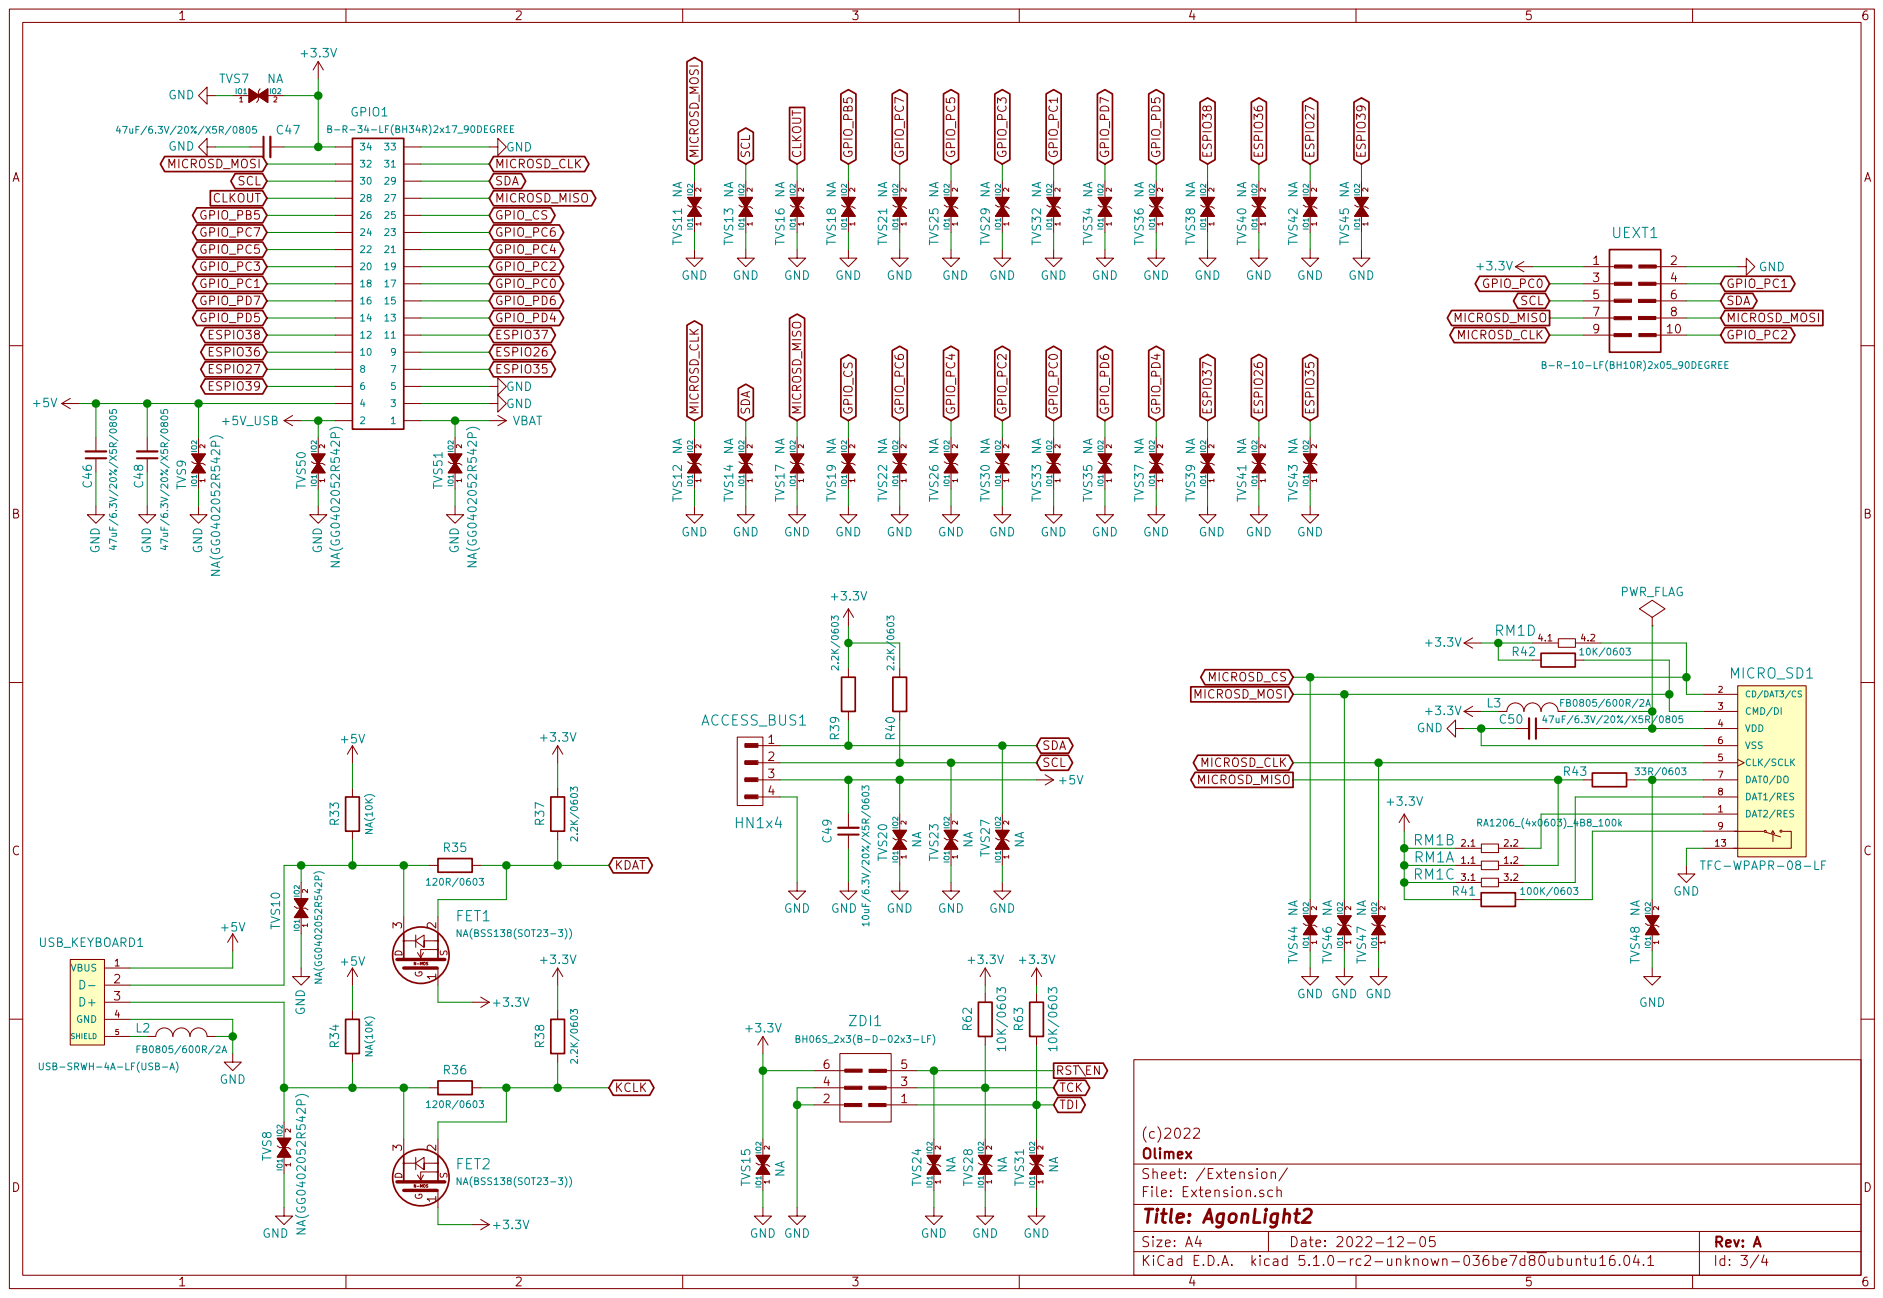
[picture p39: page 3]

File: Extension.sch Sheet: /Extension/ Olimex

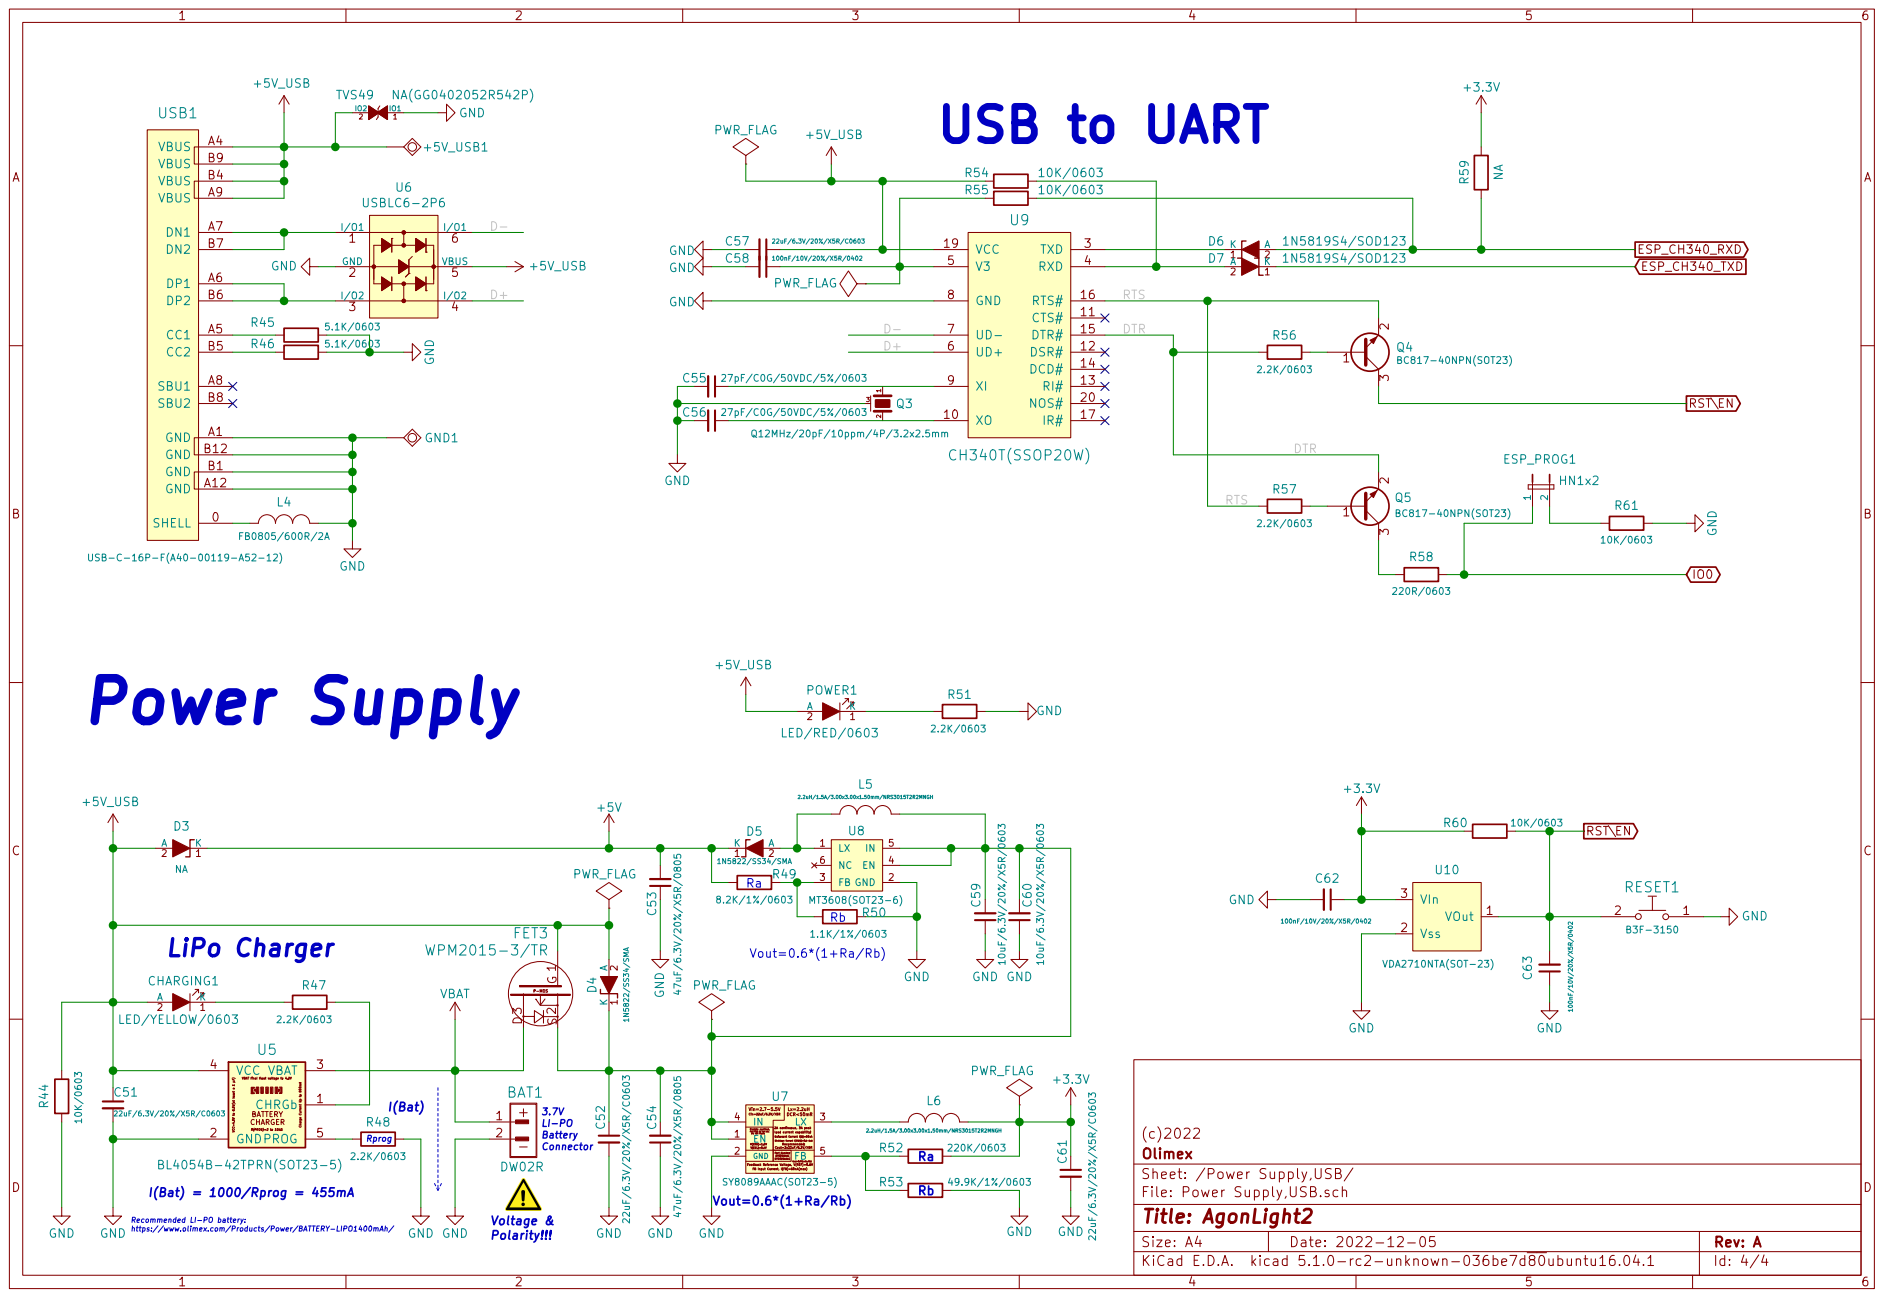
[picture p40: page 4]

load current capability! Lx=2.2uH

Do not float. Enable control. FB Input Current, I(FB)=50nA(max) Feedback Reference Voltage, V(REF)=0.6V

Sheet: /Power Supply,USB/ Olimex

File: Power Supply,USB.sch
Id: 4/4 Title: AgonLight2

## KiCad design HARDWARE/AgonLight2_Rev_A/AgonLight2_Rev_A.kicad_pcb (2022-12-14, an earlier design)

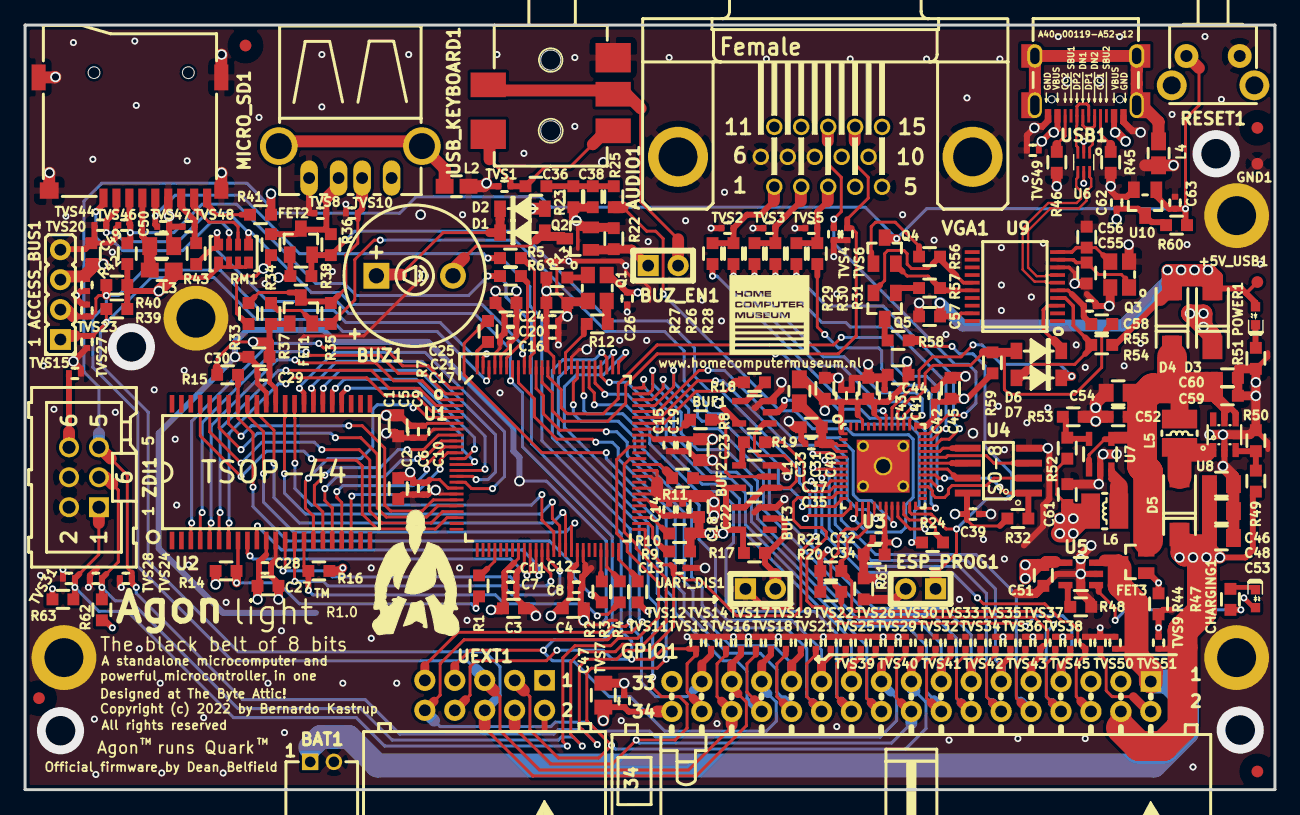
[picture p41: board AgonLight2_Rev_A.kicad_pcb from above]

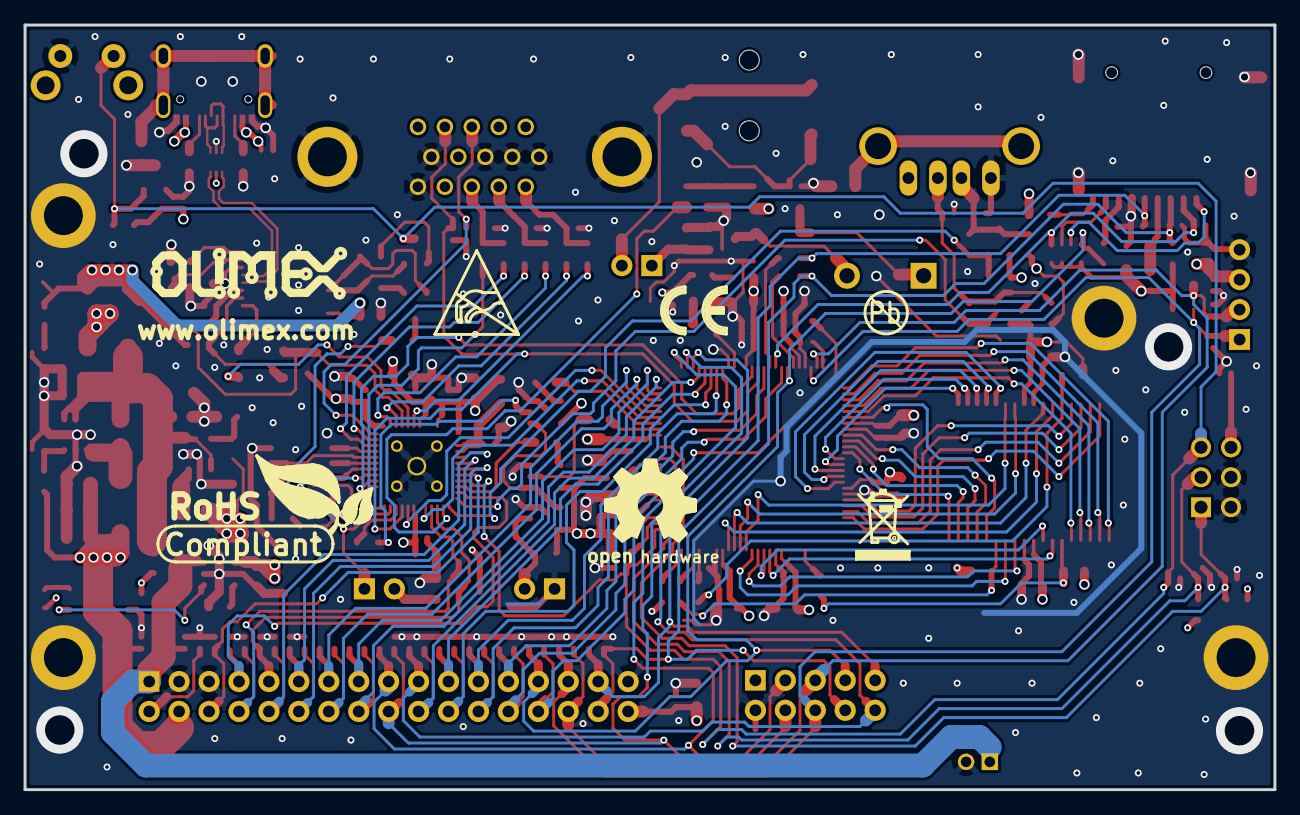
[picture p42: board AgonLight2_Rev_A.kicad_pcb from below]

Board: 4 copper layers, 106.1 x 64.9 mm, 247 parts (7 on the bottom side), 157 nets.

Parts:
+5V_USB1: TESTPAD; TP_SMD
ACCESS_BUS1: HN1x4
AUDIO1: AUDIO_JACK(SCJ325P00XG0B02G); SCJ325P00XG0B02G
BAT1: DW02R; LIPO_BAT-CON2DW02R
BUF1, BUF2: SN74LVC1G125DBVR; SOT-23-5
BUF3: SN74LVC1G04DBVR(SOT23-5); SOT-23-5
BUZ1: BUZZER_PB1221P(1.1-1.7V_2kHz_12MM); PB1221P_1-Plus_2-Minus
BUZ_EN1: HN1x2; HN1x2_Jumper
C1, C2, C3, C4, C22, C23, C24, C25, C27, C30, C33, C34, C36, C37, C43, C44, C45, C49, C59, C60: 10uF/6.3V/20%/X5R/0603; C_0603_5MIL_DWS
C5, C6, C7, C8, C13, C18, C19, C20, C21, C26, C28, C29, C31, C32, C35, C39, C40, C41, C42, C58, C62, C63: 100nF/10V/20%/X5R/0402; C_0402_5MIL_DWS
C9, C10, C11, C12, C14, C15, C16, C17: 1nF/X7R/50VDC/0402; C_0402_5MIL_DWS
C38: 33nF/X7R/50VDC/10%/0603; C_0603_5MIL_DWS
C46, C47, C48, C50, C53, C54: 47uF/6.3V/20%/X5R/0805; C_0805_5MIL_DWS
C51, C52, C57, C61: 22uF/6.3V/20%/X5R/C0603; C_0603_5MIL_DWS
C55, C56: 27pF/C0G/50VDC/5%/0603; C_0603_5MIL_DWS
CHARGING1: LED/YELLOW/0603; LED_0603_KA
D1, D2: 1N4148W/SOD123; SOD-123_1C-2A_KA
D3: NA; SMA-KA
D4, D5: 1N5822/SS34/SMA; SMA-KA
D6, D7: 1N5819S4/SOD123; SOD-123_1C-2A_KA
ESP_PROG1: HN1x2; HN1x2_Jumper
FET1, FET2: NA(BSS138(SOT23-3)); SOT23
FET3: WPM2015-3/TR; SOT23
FID1, FID2, FID3, FID4: Fiducial; Fiducial1x3
GND1: TESTPAD; TP_SMD
GPIO1: B-R-34-LF(BH34R)2x17_90DEGREE; BH34R
L1, L2, L3, L4: FB0805/600R/2A; L_0805_5MIL_DWS
L5, L6: 2.2uH/1.5A/3.00x3.00x1.50mm/NRS3015T2R2MNGH; CD32
Logo_OLIMEX_TB: Logo_OLIMEX_TB
MICRO_SD1: TFC-WPAPR-08-LF; TFC-WPAPR-08
Mounting_hole1, Mounting_hole2, Mounting_hole3, Mounting_hole4: Mounting_hole; Mounting_hole_3.3mm_with_5.5mm_pad
POWER1: LED/RED/0603; LED_0603_KA
Q1: ASE-18.432MHZ-L-C-T; Oscillator-18.432MHz-3.2x2.5mm
Q2, Q4, Q5: BC817-40NPN(SOT23); SOT23
Q3: Q12MHz/20pF/10ppm/4P/3.2x2.5mm; TSX-3.2x2.5mm_GND(3)
R1, R2, R3, R5, R6, R7, R8, R12, R17, R18, R19, R24, R43: 33R/0603; R_0603_5MIL_DWS
R4, R9, R10, R11, R13, R14, R15, R16: 4.7K/0603; R_0603_5MIL_DWS
R20, R21: 22K/0603; R_0603_5MIL_DWS
R22: 33K/0603; R_0603_5MIL_DWS
R23: 150R/0603; R_0603_5MIL_DWS
R25: 270R/0603; R_0603_5MIL_DWS
R26, R28, R30: 430R/1%/0603; R_0603_5MIL_DWS
R27, R29, R31: 820R/0603; R_0603_5MIL_DWS
R32, R42, R44, R54, R55, R60, R61, R62, R63: 10K/0603; R_0603_5MIL_DWS
R33, R34: NA(10K); R_0603_5MIL_DWS
R35, R36: 120R/0603; R_0603_5MIL_DWS
R37, R38, R39, R40, R47, R48, R51, R56, R57: 2.2K/0603; R_0603_5MIL_DWS
R41: 100K/0603; R_0603_5MIL_DWS
R45, R46: 5.1K/0603; R_0603_5MIL_DWS
R49: 8.2K/1%/0603; R_0603_5MIL_DWS
R50: 1.1K/1%/0603; R_0603_5MIL_DWS
R52: 220K/0603; R_0603_5MIL_DWS
R53: 49.9K/1%/0603; R_0603_5MIL_DWS
R58: 220R/0603; R_0603_5MIL_DWS
R59: NA; R_0603_5MIL_DWS
RESET1: B3F-3150; B3F-31XX
RM1: RA1206_(4x0603)_4B8_100k; RA1206_(4X0603)_4B8_xx
S*: Sign; HomeComputerMuseum
Sign_Antistatic: Sign_Antistatic
Sign_CE: CE_Sign
Sign_OSHW_8x8: Sign_OSHW_8x8
Sign_PB-Free: Sign_PB-Free
Sign_RecycleBin_1: Sign_RecycleBin_1
Sign_RoHS_1: Sign_RoHS_1
TVS1, TVS2, TVS3, TVS4, TVS5, TVS6, TVS7, TVS11, TVS12, TVS13, TVS14, TVS15, TVS16, TVS17, TVS18, TVS19, TVS20, TVS21, TVS22, TVS23, TVS24, TVS25, TVS26, TVS27, TVS28, TVS29, TVS30, TVS31, TVS32, TVS33, TVS34, TVS35, TVS36, TVS37, TVS38, TVS39, TVS40, TVS41, TVS42, TVS43, TVS44, TVS45, TVS46, TVS47, TVS48: NA; D_0402_5MIL_DWS
TVS8, TVS9, TVS10, TVS49, TVS50, TVS51: NA(GG0402052R542P); D_0402_5MIL_DWS
U1: EZ80F92AZ020EG(LQFP100); LQFP-100_14x14mm_STM32H730VBT6
U2: AS7C34096A-10TCTR; TSOP-44_Pitch-0.80mm_18.80x11.80x1.20mm
U3: ESP32-PICO-D4
U4: APS6404L-3SQR-SN; SO-8
U5: BL4054B-42TPRN(SOT23-5); SOT-23-5
U6: USBLC6-2P6; SOT-666
U7: SY8089AAAC(SOT23-5); SOT-23-5
U8: MT3608(SOT23-6); SOT23-6
U9: CH340T(SSOP20W); SSOP-20W
U10: VDA2710NTA(SOT-23); SOT-23
UART_DIS1: HN1x2; HN1x2_Jumper
UEXT1: B-R-10-LF(BH10R)2x05_90DEGREE; UEXT_BH10R
USB1: USB-C-16P-F(A40-00119-A52-12); USB2.0_TYPE-C(A40-00119-A52-12)
USB_KEYBOARD1: USB-SRWH-4A-LF(USB-A); USB_PN87520_HOST_PTH
VGA1: VGA15; VGA15-F(CD0515S21J0)
ZDI1: BH06S_2x3(B-D-02x3-LF); BH06S

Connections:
+3.3V: BUF1.5, BUF2.5, BUF3.5, C1.1, C2.1, C3.1, C4.1, C5.1, C6.1, C7.1, C8.1, C9.1, C10.1, C11.1, C12.1, C14.1, C15.1, C16.1, C17.1, C18.1, C19.1, C20.1, C21.1, C22.1, C23.1, C24.1, C25.1, C26.1, C27.1, C28.1, C29.1, C30.1, C31.1, C32.1, C33.1, C34.1, C39.2, C40.1, C41.1, C42.1, C43.1, C44.1, C45.1, C47.2, C61.1, C62.1, D2.2, FET1.1, FET2.1, GPIO1.34, L1.1, L3.1, L6.2, Q1.4, R4.1, R9.1, R10.1, R11.1, R13.1, R14.1, R15.1, R16.1, R17.2, R20.1, R21.1, R32.2, R37.2, R38.2, R39.2, R40.2, R41.2, R42.2, R52.2, R59.2, R60.2, R62.2, R63.2, RM1.1.1, RM1.2.1, RM1.3.1, RM1.4.1, TVS7.2, TVS15.2, U1.7, U1.18, U1.33, U1.43, U1.56, U1.67, U1.87, U1.96, U2.11, U2.33, U3.1, U3.19, U3.37, U3.43, U3.46, U4.8, U10.3, UEXT1.1, ZDI1.6
+5V: ACCESS_BUS1.3, C46.2, C48.2, C49.2, C53.2, D3.1, D5.1, GPIO1.4, R33.2, R34.2, R49.1, TVS9.2, TVS20.2, USB_KEYBOARD1.1
+5V_USB: +5V_USB1.1, C51.1, C57.1, CHARGING1.2, D3.2, D4.2, FET3.1, GPIO1.2, POWER1.2, R44.1, R54.1, TVS49.2, TVS50.2, U5.4, U6.5, U9.19, USB1.A4, USB1.A9, USB1.B4, USB1.B9
/BUF1: R18.1, U1.69
/BUF2: BUF2.2, R8.1
/CS: R1.1, R14.2, U2.8
/ESP32-PICO-D4/BUZZER: AUDIO1.4, AUDIO1.5, BUZ_EN1.2
/ESP32-PICO-D4/HS: TVS4.2, U3.36, VGA1.13
/ESP32-PICO-D4/IO4: R31.1, U3.24
/ESP32-PICO-D4/IO5: R30.1, U3.34
/ESP32-PICO-D4/IO18: R29.1, U3.35
/ESP32-PICO-D4/IO19: R28.1, U3.38
/ESP32-PICO-D4/IO21: R27.1, U3.42
/ESP32-PICO-D4/IO22: R26.1, U3.39
/ESP32-PICO-D4/PSRAM_CE: R32.1, U3.29, U4.1
/ESP32-PICO-D4/PSRAM_SCLK: U3.31, U4.6
/ESP32-PICO-D4/PSRAM_SIO0: U3.33, U4.5
/ESP32-PICO-D4/PSRAM_SIO1: U3.27, U4.2
/ESP32-PICO-D4/PSRAM_SIO2: U3.32, U4.3
/ESP32-PICO-D4/PSRAM_SIO3: U3.30, U4.7
/ESP32-PICO-D4/SOUND: R25.2, U3.14
/Power Supply,USB/D+: U6.4, U9.6
/Power Supply,USB/D-: U6.6, U9.7
/Power Supply,USB/DTR: Q5.2, R56.1, U9.15
/Power Supply,USB/RTS: Q4.2, R57.1, U9.16
/RD: R2.1, R15.2, U2.37
/SRAM_A0: U1.1, U2.3
/SRAM_A1: U1.2, U2.4
/SRAM_A2: U1.3, U2.5
/SRAM_A3: U1.4, U2.6
/SRAM_A4: U1.5, U2.7
/SRAM_A5: U1.6, U2.16
/SRAM_A6: U1.9, U2.17
/SRAM_A7: U1.10, U2.18
/SRAM_A8: U1.11, U2.19
/SRAM_A9: U1.12, U2.20
/SRAM_A10: U1.13, U2.27
/SRAM_A11: U1.14, U2.26
/SRAM_A12: U1.15, U2.28
/SRAM_A13: U1.16, U2.29
/SRAM_A14: U1.17, U2.30
/SRAM_A15: U1.20, U2.38
/SRAM_A16: U1.21, U2.39
/SRAM_A17: U1.22, U2.40
/SRAM_A18: U1.23, U2.41
/SRAM_DATA0: U1.35, U2.9
/SRAM_DATA1: U1.36, U2.10
/SRAM_DATA2: U1.37, U2.13
/SRAM_DATA3: U1.38, U2.14
/SRAM_DATA4: U1.39, U2.31
/SRAM_DATA5: U1.40, U2.32
/SRAM_DATA6: U1.41, U2.35
/SRAM_DATA7: U1.42, U2.36
/WR: R3.1, R16.2, U2.15
CLKOUT: GPIO1.28, R7.2, TVS16.2
ESP32_CTS: U1.71, U3.20
ESP32_RTS: U1.70, U3.17
ESPIO26: GPIO1.9, R20.2, TVS41.2, U3.15
ESPIO27: GPIO1.8, R21.2, TVS42.2, U3.16
ESPIO35: GPIO1.7, TVS43.2, U3.11
ESPIO36: GPIO1.10, TVS40.2, U3.5
ESPIO37: GPIO1.11, TVS39.2, U3.6
ESPIO38: GPIO1.12, TVS38.2, U3.7
ESPIO39: GPIO1.6, TVS45.2, U3.8
ESP_CH340_RXD: D6.2, R55.2, R59.1, U3.40
ESP_CH340_TXD: D7.1, U3.41
ESP_RXD: R19.1, U3.10
ESP_TXD: BUF1.2, R24.1
GND: ACCESS_BUS1.4, AUDIO1.2, BAT1.2, BUF1.3, BUF2.3, BUF3.3, C1.2, C2.2, C3.2, C4.2, C5.2, C6.2, C7.2, C8.2, C9.2, C10.2, C11.2, C12.2, C13.2, C14.2, C15.2, C16.2, C17.2, C18.2, C19.2, C20.2, C21.2, C22.2, C23.2, C24.2, C25.2, C26.2, C27.2, C28.2, C29.2, C30.2, C31.2, C32.2, C33.2, C34.2, C35.2, C37.2, C38.1, C39.1, C40.2, C41.2, C42.2, C43.2, C44.2, C45.2, C46.1, C47.1, C48.1, C49.1, C50.2, C51.2, C52.2, C53.1, C54.1, C55.2, C56.2, C57.2, C58.2, C59.1, C60.1, C61.2, C62.2, C63.1, GND1.1, GPIO1.3, GPIO1.5, GPIO1.33, L2.2, L4.2, MICRO_SD1.6, MICRO_SD1.10, MICRO_SD1.11, MICRO_SD1.12, MICRO_SD1.13, Mounting_hole1.0, Mounting_hole2.0, Mounting_hole3.0, Mounting_hole4.0, Q1.2, Q2.2, Q3.3, R22.2, R23.2, R44.2, R45.2, R46.2, R48.2, R50.2, R51.2, R53.2, R61.2, RESET1.1, TVS1.1, TVS2.1, TVS3.1, TVS4.1, TVS5.1, TVS6.1, TVS7.1, TVS8.1, TVS9.1, TVS10.1, TVS11.1, TVS12.1, TVS13.1, TVS14.1, TVS15.1, TVS16.1, TVS17.1, TVS18.1, TVS19.1, TVS20.1, TVS21.1, TVS22.1, TVS23.1, TVS24.1, TVS25.1, TVS26.1, TVS27.1, TVS28.1, TVS29.1, TVS30.1, TVS31.1, TVS32.1, TVS33.1, TVS34.1, TVS35.1, TVS36.1, TVS37.1, TVS38.1, TVS39.1, TVS40.1, TVS41.1, TVS42.1, TVS43.1, TVS44.1, TVS45.1, TVS46.1, TVS47.1, TVS48.1, TVS49.1, TVS50.1, TVS51.1, U1.8, U1.19, U1.34, U1.44, U1.57, U1.58, U1.60, U1.61, U1.84, U1.97, U2.12, U2.34, U3.49, U4.4, U5.2, U6.2, U7.2, U8.2, U9.8, U10.2, UART_DIS1.1, UEXT1.2, USB1.A1, USB1.A12, USB1.B1, USB1.B12, USB_KEYBOARD1.4, VGA1.5, VGA1.6, VGA1.7, VGA1.8, VGA1.10, VGA1.16, VGA1.17, ZDI1.2, ZDI1.4
GPIO_CS: GPIO1.25, TVS19.2, U1.90
GPIO_PB5: GPIO1.26, TVS18.2, U1.93
GPIO_PC0: GPIO1.17, TVS33.2, U1.76, UEXT1.3
GPIO_PC1: GPIO1.18, TVS32.2, U1.77, UEXT1.4
GPIO_PC2: GPIO1.19, TVS30.2, U1.78, UEXT1.10
GPIO_PC3: GPIO1.20, TVS29.2, U1.79
GPIO_PC4: GPIO1.21, TVS26.2, U1.80
GPIO_PC5: GPIO1.22, TVS25.2, U1.81
GPIO_PC6: GPIO1.23, TVS22.2, U1.82
GPIO_PC7: GPIO1.24, TVS21.2, U1.83
GPIO_PD4: GPIO1.13, TVS37.2, U1.72
GPIO_PD5: GPIO1.14, TVS36.2, U1.73
GPIO_PD6: GPIO1.15, TVS35.2, U1.74
GPIO_PD7: GPIO1.16, TVS34.2, U1.75
IO0: ESP_PROG1.1, R58.2, U3.23
ITRP: U1.88, U3.28
KCLK: FET2.2, R36.2, R38.1, U3.13
KDAT: FET1.2, R35.2, R37.1, U3.12
MICROSD_CLK: GPIO1.31, MICRO_SD1.5, R5.2, TVS12.2, TVS47.2, UEXT1.9
MICROSD_CS: MICRO_SD1.2, RM1.4.2, TVS44.2, U1.92
MICROSD_MISO: GPIO1.27, R43.2, RM1.1.2, TVS17.2, U1.94, UEXT1.7
MICROSD_MOSI: GPIO1.32, MICRO_SD1.3, R6.2, R42.1, TVS11.2, TVS46.2, UEXT1.8
unnamed: AUDIO1.1, AUDIO1.3, C36.2, TVS1.2
unnamed: BUF1.1, BUF2.1, BUF3.4
unnamed: BUF1.4, R18.2
unnamed: BUF2.4, R19.2
unnamed: BUF3.2, R17.1, UART_DIS1.2
unnamed: BUZ1.1, D1.1, D2.1
unnamed: BUZ1.2, D1.2, Q2.3
unnamed: BUZ_EN1.1, Q2.1, R22.1
unnamed: C35.1, C37.1, L1.2, U3.3, U3.4
unnamed: C36.1, C38.2, R23.1, R25.1
unnamed: C50.1, L3.2, MICRO_SD1.4
unnamed: C52.1, C54.2, C59.2, C60.2, D4.1, FET3.2, L5.2, U7.1, U7.4, U8.4, U8.5
unnamed: C55.1, U9.9
unnamed: C56.1, U9.10
unnamed: C58.1, R55.1, U9.5
unnamed: CHARGING1.1, R47.1
unnamed: D5.2, L5.1, U8.1
unnamed: D6.1, U9.3
unnamed: D7.2, R54.2, U9.4
unnamed: ESP_PROG1.2, R61.1
unnamed: FET1.3, R33.1, R35.1, TVS10.2, USB_KEYBOARD1.2
unnamed: FET2.3, R34.1, R36.1, TVS8.2, USB_KEYBOARD1.3
unnamed: L2.1, USB_KEYBOARD1.5
unnamed: L4.1, USB1.0
unnamed: L6.1, U7.3
unnamed: MICRO_SD1.1, RM1.2.2
unnamed: MICRO_SD1.7, R43.1, TVS48.2
unnamed: MICRO_SD1.8, RM1.3.2
unnamed: MICRO_SD1.9, R41.1
unnamed: POWER1.1, R51.1
unnamed: Q1.1, R13.2
unnamed: Q1.3, R12.1
unnamed: Q4.1, R56.2
unnamed: Q5.1, R57.2
unnamed: Q5.3, R58.1
unnamed: R1.2, U1.29
unnamed: R2.2, U1.47
unnamed: R3.2, U1.48
unnamed: R4.2, U1.50
unnamed: R5.1, U1.91
unnamed: R6.1, U1.95
unnamed: R7.1, U1.100
unnamed: R8.2, U1.68
unnamed: R9.2, U1.52
unnamed: R10.2, U1.53
unnamed: R11.2, U1.62
unnamed: R12.2, U1.85
unnamed: R24.2, U3.22
unnamed: R26.2, R27.2, TVS2.2, VGA1.1
unnamed: R28.2, R29.2, TVS3.2, VGA1.2
unnamed: R30.2, R31.2, TVS5.2, VGA1.3
unnamed: R45.1, USB1.A5
unnamed: R46.1, USB1.B5
unnamed: R47.2, U5.1
unnamed: R48.1, U5.5
unnamed: R49.2, R50.1, U8.3
unnamed: R52.1, R53.1, U7.5
unnamed: U6.1, USB1.A7, USB1.B7
unnamed: U6.3, USB1.A6, USB1.B6
RST\EN: C13.1, C63.2, Q4.3, R60.1, RESET1.2, TVS24.2, U1.51, U3.9, U10.1, ZDI1.5
SCL: ACCESS_BUS1.2, GPIO1.30, R40.1, TVS13.2, TVS23.2, U1.99, UEXT1.5
SDA: ACCESS_BUS1.1, GPIO1.29, R39.1, TVS14.2, TVS27.2, U1.98, UEXT1.6
TCK: R62.1, TVS28.2, U1.63, ZDI1.3
TDI: R63.1, TVS31.2, U1.65, ZDI1.1
VBAT: BAT1.1, FET3.3, GPIO1.1, TVS51.2, U5.3
VS: TVS6.2, U1.89, U3.21, VGA1.14

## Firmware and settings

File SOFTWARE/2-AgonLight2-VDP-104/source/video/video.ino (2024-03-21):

//
// Title:			Agon Video BIOS
// Author:			Dean Belfield
// Contributors:	Jeroen Venema (Sprite Code, VGA Mode Switching)
//					Damien Guard (Fonts)
//					Igor Chaves Cananea (vdp-gl maintenance)
//					Steve Sims (Audio enhancements, refactoring, bug fixes)
// Created:			22/03/2022
// Last Updated:	11/11/2023
//
// Modinfo:
// 11/07/2022:		Baud rate tweaked for Agon Light, HW Flow Control temporarily commented out
// 26/07/2022:		Added VDU 29 support
// 03/08/2022:		Set codepage 1252, fixed keyboard mappings for AGON, added cursorTab, VDP serial protocol
// 06/08/2022:		Added a custom font, fixed UART initialisation, flow control
// 10/08/2022:		Improved keyboard mappings, added sprites, audio, new font
// 05/09/2022:		Moved the audio class to agon_audio.h, added function prototypes in agon.h
// 02/10/2022:		Version 1.00: Tweaked the sprite code, changed bootup title to Quark
// 04/10/2022:		Version 1.01: Can now change keyboard layout, origin and sprites reset on mode change, available modes tweaked
// 23/10/2022:		Version 1.02: Bug fixes, cursor visibility and scrolling
// 15/02/2023:		Version 1.03: Improved mode, colour handling and international support
// 04/03/2023:					+ Added logical screen resolution, sendScreenPixel now sends palette index as well as RGB values
// 09/03/2023:					+ Keyboard now sends virtual key data, improved VDU 19 to handle COLOUR l,p as well as COLOUR l,r,g,b
// 15/03/2023:					+ Added terminal support for CP/M, RTC support for MOS
// 21/03/2023:				RC2 + Added keyboard repeat delay and rate, logical coords now selectable
// 22/03/2023:					+ VDP control codes now indexed from 0x80, added paged mode (VDU 14/VDU 15)
// 23/03/2023:					+ Added VDP_GP
// 26/03/2023:				RC3 + Potential fixes for FabGL being overwhelmed by faster comms
// 27/03/2023:					+ Fix for sprite system crash
// 29/03/2023:					+ Typo in boot screen fixed
// 01/04/2023:					+ Added resetPalette to MODE, timeouts to VDU commands
// 08/04/2023:				RC4 + Removed delay in readbyte_t, fixed VDP_SCRCHAR, VDP_SCRPIXEL
// 12/04/2023:					+ Fixed bug in play_note
// 13/04/2023:					+ Fixed bootup fail with no keyboard
// 17/04/2023:				RC5 + Moved wait_completion in vdu so that it only executes after graphical operations
// 18/04/2023:					+ Minor tweaks to wait completion logic
// 12/05/2023:		Version 1.04: Now uses vdp-gl instead of FabGL, implemented GCOL mode, sendModeInformation now sends video mode
// 19/05/2023:					+ Added VDU 4/5 support
// 25/05/2023:					+ Added VDU 24, VDU 26 and VDU 28, fixed inverted text colour settings
// 30/05/2023:					+ Added VDU 23,16 (cursor movement control)
// 28/06/2023:					+ Improved get_screen_char, fixed vdu_textViewport, cursorHome, changed modeline for Mode 2
// 30/06/2023:					+ Fixed vdu_sys_sprites to correctly discard serial input if bitmap allocation fails
// 13/08/2023:				RC2	+ New video modes, mode change resets page mode
// 05/09/2023:					+ New audio enhancements, improved mode change code
// 12/09/2023:					+ Refactored
// 11/11/2023:				RC3 + See Github for full list of changes

#include <WiFi.h>
#include <HardwareSerial.h>
#include <fabgl.h>

#define VERSION			1
#define REVISION		4
#define RC				0

#define	DEBUG			0						// Serial Debug Mode: 1 = enable
#define SERIALBAUDRATE	115200

HardwareSerial	DBGSerial(0);

bool			terminalMode = false;			// Terminal mode (for CP/M)
bool			consoleMode = false;			// Serial console mode (0 = off, 1 = console enabled)

#include "agon.h"								// Configuration file
#include "agon_ps2.h"							// Keyboard support
#include "agon_audio.h"							// Audio support
#include "agon_ttxt.h"
#include "graphics.h"							// Graphics support
#include "cursor.h"								// Cursor support
#include "vdp_protocol.h"						// VDP Protocol
#include "vdu_stream_processor.h"
#include "hexload.h"

fabgl::Terminal			Terminal;				// Used for CP/M mode
VDUStreamProcessor *	processor;				// VDU Stream Processor

#include "zdi.h"								// ZDI debugging console

void setup() {
	disableCore0WDT(); delay(200);				// Disable the watchdog timers
	disableCore1WDT(); delay(200);
	DBGSerial.begin(SERIALBAUDRATE, SERIAL_8N1, 3, 1);
	setupVDPProtocol();
	processor = new VDUStreamProcessor(&VDPSerial);
	processor->wait_eZ80();
	setupKeyboardAndMouse();
	init_audio();
	copy_font();
	set_mode(1);
	processor->sendModeInformation();
	boot_screen();
}

// The main loop
//
void loop() {
	uint32_t count = 0;						// Generic counter, incremented every loop iteration
	bool cursorVisible = false;
	bool cursorState = false;

	while (true) {
		if (terminalMode) {
			do_keyboard_terminal();
			continue;
		}
		cursorVisible = ((count & 0xFFFF) == 0);
		if (cursorVisible) {
    		if (!cursorState && ttxtMode) ttxt_instance.flash(true);
			cursorState = !cursorState;
			do_cursor();
      		if (!cursorState && ttxtMode) ttxt_instance.flash(false);
		}
		do_keyboard();
		do_mouse();

		if (processor->byteAvailable()) {
			if (cursorState) {
				cursorState = false;
				do_cursor();
			}
			processor->processNext();
		}
		count++;
	}
}

// Handle the keyboard: BBC VDU Mode
//
void do_keyboard() {
	uint8_t keycode;
	uint8_t modifiers;
	uint8_t vk;
	uint8_t down;
	if (getKeyboardKey(&keycode, &modifiers, &vk, &down)) {
		// Handle some control keys
		//
		switch (keycode) {
			case 14: setPagedMode(true); break;
			case 15: setPagedMode(false); break;
		}
		// Create and send the packet back to MOS
		//
		uint8_t packet[] = {
			keycode,
			modifiers,
			vk,
			down,
		};
		processor->send_packet(PACKET_KEYCODE, sizeof packet, packet);
	}
}

// Handle the keyboard: CP/M Terminal Mode
// 
void do_keyboard_terminal() {
	uint8_t ascii;
	if (getKeyboardKey(&ascii)) {
		// send raw byte straight to z80
		processor->writeByte(ascii);
	}

	// Write anything read from z80 to the screen
	//
	while (processor->byteAvailable()) {
		Terminal.write(processor->readByte());
	}
}

// Handle the mouse
//
void do_mouse() {
	// get mouse delta, if the mouse is active
	MouseDelta delta;
	if (mouseMoved(&delta)) {
		auto mouse = getMouse();
		auto mStatus = mouse->status();
		// update mouse cursor position if it's active
		setMouseCursorPos(mStatus.X, mStatus.Y);
		processor->sendMouseData(&delta);
	}
}

// The boot screen
//
void boot_screen() {
	printFmt("Agon Quark VDP Version %d.%02d", VERSION, REVISION);
	#if RC > 0
		printFmt(" RC%d", RC);
	#endif
	printFmt("\n\r");
}

// Debug printf to PC
//
void debug_log(const char *format, ...) {
	#if DEBUG == 1
	va_list ap;
	va_start(ap, format);
	auto size = vsnprintf(nullptr, 0, format, ap) + 1;
	if (size > 0) {
		va_end(ap);
		va_start(ap, format);
		char buf[size + 1];
		vsnprintf(buf, size, format, ap);
		DBGSerial.print(buf);
	}
	va_end(ap);
	#endif
}

// Set console mode
// Parameters:
// - mode: 0 = off, 1 = on
//
void setConsoleMode(bool mode) {
	consoleMode = mode;
}

// Switch to terminal mode
//
void switchTerminalMode() {
	cls(true);
	canvas.reset();
	Terminal.begin(_VGAController.get());	
	Terminal.connectSerialPort(VDPSerial);
	Terminal.enableCursor(true);
	terminalMode = true;
}

void print(char const * text) {
	for (auto i = 0; i < strlen(text); i++) {
		processor->vdu(text[i]);
	}
}

void printFmt(const char *format, ...) {
	va_list ap;
	va_start(ap, format);
	int size = vsnprintf(nullptr, 0, format, ap) + 1;
	if (size > 0) {
		va_end(ap);
		va_start(ap, format);
		char buf[size + 1];
		vsnprintf(buf, size, format, ap);
		print(buf);
	}
	va_end(ap);
}

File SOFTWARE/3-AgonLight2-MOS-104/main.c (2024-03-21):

/*
 * Title:			AGON MOS
 * Author:			Dean Belfield
 * Created:			19/06/2022
 * Last Updated:	11/11/2023
 *
 * Modinfo:
 * 11/07/2022:		Version 0.01: Tweaks for Agon Light, Command Line code added
 * 13/07/2022:		Version 0.02
 * 15/07/2022:		Version 0.03: Warm boot support, VBLANK interrupt
 * 25/07/2022:		Version 0.04; Tweaks to initialisation and interrupts
 * 03/08/2022:		Version 0.05: Extended MOS for BBC Basic, added config file
 * 05/08/2022:		Version 0.06: Interim release with hardware flow control enabled
 * 10/08/2022:		Version 0.07: Bug fixes
 * 05/09/2022:		Version 0.08: Minor updates to MOS
 * 02/10/2022:		Version 1.00: Improved error handling for languages, changed bootup title to Quark
 * 03/10/2022:		Version 1.01: Added SET command, tweaked error handling
 * 20/10/2022:					+ Tweaked error handling
 * 13/11/2022:		Version 1.02
 * 14/03/2023		Version 1.03: SD now uses timer0, does not require interrupt
 *								+ Stubbed command history
 * 22/03/2023:					+ Moved command history to mos_editor.c
 * 23/03/2023:				RC2	+ Increased baud rate to 1152000
 * 								+ Improved ESP32->eZ80 boot sync
 * 29/03/2023:				RC3 + Added UART1 initialisation, tweaked startup sequence timings
 * 16/05/2023:		Version 1.04: Fixed MASTERCLOCK value in uart.h, added startup beep
 * 03/08/2023:				RC2	+ Enhanced low-level keyboard functionality
 * 27/09/2023:					+ Updated RTC
 * 11/11/2023:				RC3	+ See Github for full list of changes
 */

#include <eZ80.h>
#include <defines.h>
#include <stdio.h>
#include <CTYPE.h>
#include <String.h>

#include "defines.h"
#include "config.h"
#include "uart.h"
#include "spi.h"
#include "timer.h"
#include "ff.h"
#include "clock.h"
#include "mos.h"
#include "i2c.h"

#define		MOS_version		1
#define		MOS_revision 	4
#define		MOS_rc			0

extern void *	set_vector(unsigned int vector, void(*handler)(void));

extern void 	vblank_handler(void);
extern void 	uart0_handler(void);
extern void 	i2c_handler(void);

extern char 			coldBoot;		// 1 = cold boot, 0 = warm boot
extern volatile	char 	keycode;		// Keycode 
extern volatile char	gp;				// General poll variable

extern volatile BYTE history_no;
extern volatile BYTE history_size;

static char  	cmd[256];				// Array for the command line handler

// Wait for the ESP32 to respond with a GP packet to signify it is ready
// Parameters:
// - pUART: Pointer to a UART structure
// - baudRate: Baud rate to initialise UART with
// Returns:
// - 1 if the function succeeded, otherwise 0
//
int wait_ESP32(UART * pUART, UINT24 baudRate) {	
	int	i, t;

	pUART->baudRate = baudRate;			// Initialise the UART object
	pUART->dataBits = 8;
	pUART->stopBits = 1;
	pUART->parity = PAR_NOPARITY;
	pUART->flowControl = FCTL_HW;
	pUART->interrupts = UART_IER_RECEIVEINT;

	open_UART0(pUART);					// Open the UART 
	init_timer0(10, 16, 0x00);  		// 10ms timer for delay
	gp = 0;								// Reset the general poll byte	
	for(t = 0; t < 200; t++) {			// A timeout loop (200 x 50ms = 10s)
		putch(23);						// Send a general poll packet
		putch(0);
		putch(VDP_gp);
		putch(1);
		for(i = 0; i < 5; i++) {		// Wait 50ms
			wait_timer0();
		}
		if(gp == 1) break;				// If general poll returned, then exit for loop
	}
	enable_timer0(0);					// Disable the timer
	return gp;
}

// Initialise the interrupts
//
void init_interrupts(void) {
	set_vector(PORTB1_IVECT, vblank_handler); 	// 0x32
	set_vector(UART0_IVECT, uart0_handler);		// 0x18
	set_vector(I2C_IVECT, i2c_handler);			// 0x1C
}

// The main loop
//
int main(void) {
	UART 	pUART0;

	DI();											// Ensure interrupts are disabled before we do anything
	init_interrupts();								// Initialise the interrupt vectors
	init_rtc();										// Initialise the real time clock
	init_spi();										// Initialise SPI comms for the SD card interface
	init_UART0();									// Initialise UART0 for the ESP32 interface
	init_UART1();									// Initialise UART1
	EI();											// Enable the interrupts now
	
	if(!wait_ESP32(&pUART0, 1152000)) {				// Try to lock onto the ESP32 at maximum rate
		if(!wait_ESP32(&pUART0, 384000))	{		// If that fails, then fallback to the lower baud rate
			gp = 2;									// Flag GP as 2, just in case we need to handle this error later
		}
	}	
	if(coldBoot == 0) {								// If a warm boot detected then
		putch(12);									// Clear the screen
	}
	printf("Agon Quark MOS Version %d.%02d", MOS_version, MOS_revision);
	#if MOS_rc > 0
		printf(" RC%d", MOS_rc);
	#endif
	printf("\n\r\n\r");
	#if	DEBUG > 0
	printf("@Baud Rate: %d\n\r\n\r", pUART0.baudRate);
	#endif

	mos_mount();									// Mount the SD card

	putch(7);										// Startup beep
	history_no = 0;
	history_size = 0;

	// Load the autoexec.bat config file
	//
	#if enable_config == 1	
	if(coldBoot > 0) {								// Check it's a cold boot (after reset, not RST 00h)
		mos_BOOT("autoexec.txt", cmd, sizeof cmd);	// Then load and run the config file
	}	
	#endif

	// The main loop
	//
	while(1) {
		if(mos_input(&cmd, sizeof(cmd)) == 13) {
			int err = mos_exec(&cmd);
			if(err > 0) {
				mos_error(err);
			}
		}
		else {
			printf("%cEscape\n\r", MOS_prompt);
		}
	}

	return 0;
}

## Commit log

2022-12-14 Initial upload CAD files
    [72w2538_292303-4.stp, ALSRobot-BUZZER.step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]
2023-06-09 Update
    revision B
    [72w2538_292303-4.stp, ALSRobot-BUZZER.step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]
2024-03-21 Update README.md
    Notice about ESP32 package 3.x.x
2024-03-21 Updated VDP, MOS and BASIC to the latest versions
    VDP and MOS updated from 1.04-rc1 to 1.04 (thanks to Dean Belfield - breakintoprogram)
    Changed Arduino project for the VDP, MOS project for ZDS2 IDE.
    BASIC updated from 1.05 to 1.06 version.
    The bin file in the SD card content has been changed to the latest one.
    Added latest MOS file in the SD card files.
    Added updater for the VDP using only bin files (thanks to Jeroen Venema - envenomator)
    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

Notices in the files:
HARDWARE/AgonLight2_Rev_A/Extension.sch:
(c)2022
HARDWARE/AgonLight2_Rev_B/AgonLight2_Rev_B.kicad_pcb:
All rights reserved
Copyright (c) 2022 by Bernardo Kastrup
